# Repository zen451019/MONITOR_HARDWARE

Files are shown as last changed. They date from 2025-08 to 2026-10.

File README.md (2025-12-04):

# NEMO: Electromechanical Monitoring Firmware

This repository contains the complete source code for the firmware for NEMO (Node for Electromechanical Monitoring & Operation), a high-performance IoT node designed for real-time monitoring of analog signals.

The system is optimized to capture, process, and transmit voltage and current data from sensors, making it an ideal solution for predictive maintenance, energy consumption monitoring, and industrial machinery diagnostics applications.

## Modbus master monitor documentation

English
https://zen451019.github.io/MONITOR_HARDWARE/28-11-25/English/MASTER_MODBUS/html/index.html

Spanish
https://zen451019.github.io/MONITOR_HARDWARE/28-11-25/Español/MASTER_MODBUS/html/index.html

## Modbus slave monitor documentation
English
https://zen451019.github.io/MONITOR_HARDWARE/28-11-25/English/SLAVE_MODBUS/html/index.html

Spanish
https://zen451019.github.io/MONITOR_HARDWARE/28-11-25/Español/SLAVE_MODBUS/html/index.html

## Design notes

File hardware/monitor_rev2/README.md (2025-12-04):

# MODBUS MASTER MONITOR

## Description
This PCB uses an ESP32 TTGO LoRa V2.1 that functions as a Modbus master and acts as a gateway for Modbus slaves with various integrated sensors. The design includes a UART to RS485 transceiver for network communication using the Modbus protocol. Additionally, it integrates a voltage detector for a 12-volt battery, a multipurpose digital input, and an 8-position DIP switch for Modbus address selection.

## Repository Contents
- `monitor_REV2/` folder: KiCad files for the schematic and PCB.
- `docs/` folder: Diagrams, images, and PDFs of the design.

## Schematic
Schematic

## PCB
PCB

## Manufacturing
### Gerber Files
The Gerber files are in `monitor_REV2/output`.

### Bill of Materials (BOM)
Included as `monitor_REV2/monitor REV2.csv`.

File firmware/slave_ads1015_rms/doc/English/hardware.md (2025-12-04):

@file hardware.md
@defgroup group_hardware Hardware and System

@section group_hardware_overview Overview
This module implements the ESP32 hardware configuration and complete flow of:
- I2C peripheral configuration for ADS1015 communication.
- RS485 UART configuration for Modbus RTU communication.
- ADC conversion interrupt system initialization.
- FreeRTOS configuration with tasks distributed across cores.

@section Structure_and_components Structure and Components

- Pin and peripheral configuration
  - I2C_SDA_PIN, I2C_SCL_PIN: I2C bus for ADS1015.
  - RX_PIN, TX_PIN: RS485 serial communication.
  - ADS_ALERT_PIN: conversion complete interrupt.

- Hardware objects
  - Adafruit_ADS1015: analog-to-digital converter instance.
  - HardwareSerial: serial port for Modbus RTU.
  - ModbusServerRTU: Modbus protocol server.

- System configuration
  - NUM_CHANNELS: configured ADC channels (3 channels).
  - Speed parameters: 19200 bps UART, 400kHz I2C, 3300 SPS ADC.
  - GAIN_TWOTHIRDS: ADS1015 gain for ±6.144V range.

@section group_hardware_api Main API
- Configuration: `I2C_SDA_PIN`, `I2C_SCL_PIN`, `ADS_ALERT_PIN`, `RX_PIN`, `TX_PIN`, `NUM_CHANNELS`.
- Objects: `ads`.
- Functions: `setup()`, `loop()`, `on_adc_data_ready()`.

@section group_hardware_usage Usage
Flow summary:

1) Hardware initialization
   - I2C bus configuration (SDA=9, SCL=8) at 400kHz.
   - ADS1015 initialization with TWOTHIRDS gain and 3300 SPS speed.
   - UART configuration (RX=20, TX=21) at 19200 bps, 8N1 for RS485.
   - Interrupt registration on pin 10 for ADS1015 ALERT signal.

2) FreeRTOS task configuration
   - `task_adquisicion`: core 0, priority 5, ADC conversion management.
   - `task_procesamiento`: core 0, priority 3, RMS calculation with FIFOs.
   - `dataUpdateTask`: core 0, priority 1, Modbus register updates.
   - Modbus server: core 0, RTU request handling.

3) ADC configuration
   - Single-ended mode on 3 channels (A0, A1, A2).
   - Interrupt-driven conversions using ALERT signal.
   - Round-robin sequence between channels managed by ISR.

4) Modbus configuration
   - RTU server with ID=1, timeout=2000ms.
   - Worker registration for function 03 (holding register read).
   - Discovery response (registers 0-7) and RMS data (registers 10+).

Warnings and best practices:
- Verify I2C connections before `ads.begin()` to avoid hangs.
- Use external pullups on SDA/SCL lines if communication issues occur.
- Properly configure ADS1015 ALERT signal for interrupts.
- Verify I2C bus speed according to cable length.
- Protect concurrent hardware access using appropriate semaphores.
- Ensure stable power supply for accurate ADC conversions.

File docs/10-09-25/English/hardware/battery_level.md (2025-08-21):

## Battery Level

The battery in an electromechanical system acts as a primary or backup power source, ensuring startup, continuous operation in the event of power outages, and system stability. It also dampens transients, supplies peak currents to actuators, and keeps control and sensing circuits powered for reliable operation.

## ## Signal Conditioning

The battery signal is direct current (DC) and, due to its voltage level, the [ESP32](./central_controller.md) cannot monitor it directly. Therefore, a voltage divider is implemented that reduces the signal to a safe range for the microcontroller, while maintaining its representativeness with respect to the actual battery level.



$$
V_{out} = V_{in} \frac{ R_2 }{R_1 + R_2}
$$
With Vin max at 3.3 volts and Vout max at 15 volts for a safe range, and defining R2 = 3.3 kΩ, we find R1.

$$
R_1 = R_2 \frac{ V_{in}-V_{out}}{V_{out}}
$$
$$
R_1 = 3.3 kΩ \frac{ 15V-3.3V}{3.3V} = 11700Ω
$$
Approximating the value of R1 to a commercial resistor, we have that R1 = 12 kΩ, with this the maximum Vin is

$$
V_{in} = 3.3V \frac{ 12 kΩ + 3.3 kΩ }{3.3 kΩ} = 15.3 V
$$

This voltage divider adapts the range from 0 V to 15.3 V to a safe range from 0 V to 3.3 V for microcontroller reading. The actual value is then scaled using software.



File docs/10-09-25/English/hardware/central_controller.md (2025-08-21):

# Central Controller

A microcontroller with high computing power, multiple input/output interfaces, integrated analog-to-digital conversion, and robust communication capabilities is required as the central control device. For these reasons, the ESP32 family was selected, which offers an appropriate balance between performance, wireless connectivity, development ecosystem, and cost, enabling local processing, communications management, and real-time control within a single SoC.

## Module Selection

To accelerate development and consolidate computing, radio, and power functions onto a single board, the TTGO LoRa32 v2.1 module/board is selected, based on the ESP32‑PICO‑D4 SoC and integrated with an SX127x family LoRa transceiver. This choice provides a ready-to-prototype and ready-to-operate environment, with wireless connectivity and sufficient I/O resources for system data acquisition and transmission.

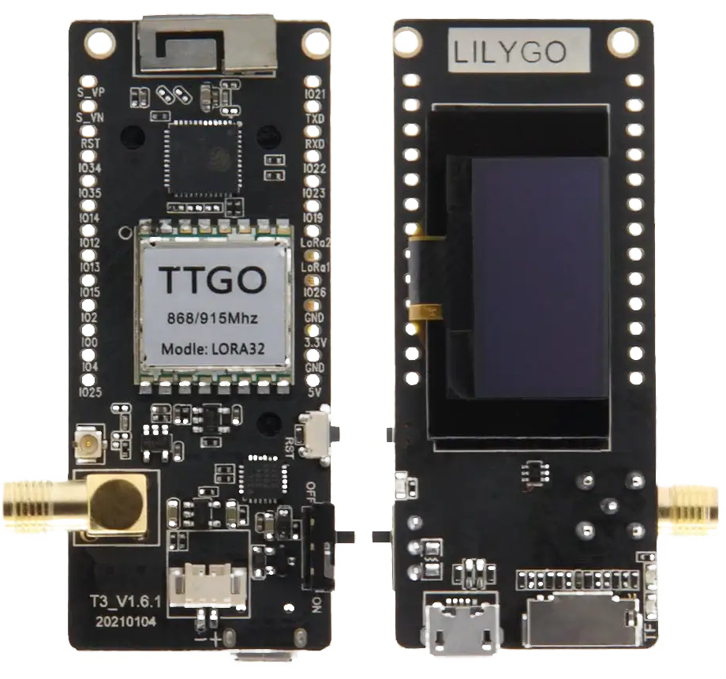
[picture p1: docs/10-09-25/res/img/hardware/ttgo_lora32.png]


### SoC ESP32 PICO D4 Capabilities

* CPU: dual-core Xtensa LX6 up to 240 MHz, with ULP coprocessor for ultra-low power tasks.
* Memory: integrated SRAM and support for external Flash; DMA for high-performance peripherals.
* ADC/DAC: 12-bit ADC with multiple channels and 2 8-bit DACs
* GPIO and interfaces: UART, I2C, SPI, I2S, PWM (ledc), RMT, SD/SDIO; Ethernet MAC and CAN (TWAI).
* Security: AES encryption, SHA, RSA/ECC, HMAC; Secure Boot and Flash Encryption.
* Industrial temperature range: −40 °C to +85 °C.

### Integrated LoRa Radio

The TTGO LoRa32 v2.1 incorporates a LoRaSX1276 transceiver compatible with LoRaWAN in the target regional band (868/915 MHz), with configurable dispersion factors and bandwidths, and adjustable transmission power for long-range links.

### Relevant Features of the TTGO LoRa32 v2.1

* Power supply: integrated regulator, USB input and 3V3 pin; charger for Li‑ion/Li‑Po battery with JST connector.
* User interface: integrated OLED display, buttons, and status LEDs for local diagnostics.
* Connectivity and programming: USB‑UART port for programming/debugging and log support; LoRa antenna included.

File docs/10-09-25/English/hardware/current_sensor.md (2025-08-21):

# Three-phase Current Transducer

The current transducer is the element responsible for capturing the electrical current present in the electromechanical system and transforming it into a signal suitable for the microcontroller's acquisition stage, through the corresponding conditioning. There are multiple variants of current transducers, based on principles such as the Hall effect, shunt resistance, or current transformer, and available with analog or digital outputs, depending on the interface requirements and system specifications.

## SCT-013-000 Sensor

The SCT-013-000 is a non-invasive split-core AC current transducer that uses a current transformer to measure AC with galvanic isolation. In its variant (100 A : 50 mA), it delivers a proportional current signal that requires an external load resistance (burden) to convert it into a voltage suitable for reading by microcontrollers.

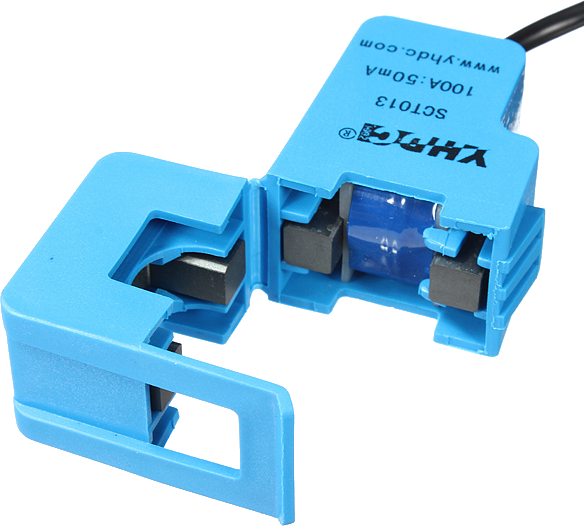
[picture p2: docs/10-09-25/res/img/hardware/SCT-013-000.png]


### Features
- Clip-type split core, installation without interrupting the circuit and with safe galvanic isolation.
- Transformation ratio 100 A : 50 mA (model SCT-013-000, without integrated load resistance).
- Requires external burden resistance sized according to the ADC range and the current level to be measured.
- Analog output proportional to the primary current; requires center bias for AC reading with 3.3 V or 5 V ADC.
- Nominal frequency 50/60 Hz; good linearity in residential and industrial applications.

## Signal Conditioning

The SCT-013-000 delivers an AC signal on its secondary side proportional to the current flowing through the primary side, operating as a current transformer. In this version (100 A : 50 mA), the ratio is 2000:1, so that, for example, if 50 A RMS flows through the primary, 25 mA RMS will flow through the secondary. In order for the microcontroller to register this magnitude, it is necessary to convert the secondary current into a voltage using a load resistor (**burden**) connected in parallel between the sensor terminals. According to Ohm's law, the resulting voltage is :  $$V = I_{sec} × R_{burden}$$
To size the **burden** resistance, the target voltage level at the sensor output must be considered so that the input range of the analog-to-digital converter (ADC) of the [ESP32](./central_controller.md), typically 0 to 3.3 V, is not exceeded. Consequently, the voltage generated by the secondary current through the **burden** must be, at most, equal to or less than the ADC limit. In AC applications, it is common to add a DC bias at the midpoint of the ADC scale to center the signal within the 0–3.3 V range and avoid clipping.

![[../../res/img/hardware/Sensor_and_conditioning.drawio.svg]]

A voltage range of 2.828 V has been considered, which is comfortably within the ADC range. By not operating near its limits, there is sufficient safety margin to reduce the risk of signal saturation and clipping.

Assuming a target voltage of

$$
2.828 V_{pico a pico} = 1.414 V_{pico}
$$
With a max current value
$$
I_{RMS(sec)} = 50 mA
$$
To resolve R
$$
I_{RMS(sec)} × R_{burden} = V_{RMS}   
$$
$$
50mA × R_{burden} =  \frac{ V_{pico} }{\sqrt{2}} 
$$
$$
50mA × R_{burden} =  \frac{ 1.414 V_{pico} }{\sqrt{2}} = 1 V_{RMS}
$$
$$
R_{burden} \approx 20 \Omega
$$

As a result, the necessary load resistance (burden) is approximately 20 Ω. It is still necessary to add a bias voltage to the signal, as otherwise half of the amplitude would be lost due to the microcontroller's inability to measure negative voltages. To take advantage of the widest possible dynamic range, this bias is set at half the measurement range, for which a voltage divider is used. The following equation represents the output voltage as a function of the input voltage to the voltage divider.



$$
V_{out} = V_{in} \frac{ R_2 }{R_1 + R_2}
$$
If R2 = R1
$$
V_{out} = V_{in} \frac{ R_2 }{2 R_2}
$$
$$
V_{out} =  \frac{ V_{in} }{2}
$$

To limit the current, R = 10 kΩ is selected. With this value, the following conditioning circuit is proposed for the SCT-013-000 AC current sensor (100 A / 50 mA).

![[../../res/img/hardware/Diagrama_sensor_corriente.drawio.svg]]

A 100 nF capacitor is added as an anti-aliasing filter and another 10 µF capacitor to keep the bias voltage stable. Like the [voltage sensor](./voltage_sensor.md), the sensor and its conditioning circuit can only measure a single-phase signal. To compensate for this and obtain two-phase or three-phase measurements, the use of three sensors with their respective conditioning circuits is proposed; in this way, each one is responsible for one voltage line and complete measurements are obtained.

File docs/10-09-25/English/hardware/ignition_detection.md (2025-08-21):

# Ignition Detection

The module must have a mechanism to detect when the electromechanical system is turned on and off, as certain variables depend directly on it being active in order to be processed correctly. To this end, a digital input is designed to allow the microcontroller to capture external signals.

The signal to be monitored will be the presence or absence of DC voltage from the battery, the controller, or any other device in the electromechanical system. This offers flexibility in both hardware (using a relay, the controller itself, etc., to generate the power-on signal) and software for encoding the logic.

## Signal Conditioning

In order for the microcontroller to safely capture these signals, given the differences in voltage levels, an opto-coupler level shifter is used, providing level adaptation and galvanic isolation.



Each time a digital signal arrives, the optocoupler activates its diode, which in turn turns on the phototransistor. This allows the pin on the [ESP32](./central_controller.md) to drop to GND. For correct detection, the ESP32 pin must be configured as an input with pull-up.

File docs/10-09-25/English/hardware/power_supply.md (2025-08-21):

# Module power supply

The module's power supply must be reliable, stable, and uninterrupted. Since data is transmitted 24/7, it is essential to avoid shutdowns in the event of any contingency. This requires a power supply system that anticipates possible failures and, as far as possible, mitigates or counteracts them.
## Requirements

- **Power Supply:** The main power supply is the electromechanical system battery, so the module must be able to draw power from this source.
- **Uninterrupted Power Supply:** The module must continue to operate even if the main power source is interrupted, so it must include a system that guarantees a continuous power supply.
- **Stable voltage level:** Both the [ESP32](./central_controller.md) and the other components of the module require a 3.3-volt power supply. Therefore, the power supply system must guarantee a stable source for the module.

To meet these requirements, two modules are selected to form the power supply system.

## DC-DC step-down converter

- Input: 12–24 VDC. Output: 5 VDC.
- Maximum power: 50 W. Efficiency: 95%.
- Protections: overcurrent, overvoltage, overtemperature, shutdown, and short circuit.
- Temperature range: −40 to 85 °C
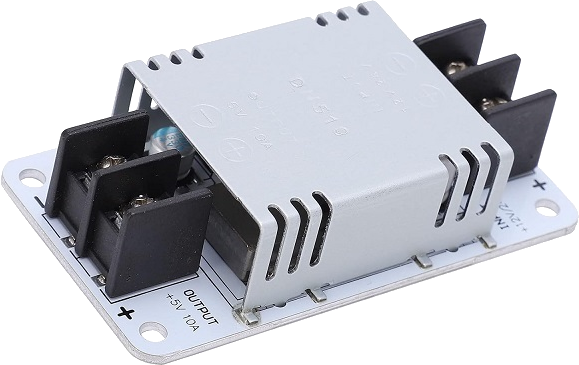
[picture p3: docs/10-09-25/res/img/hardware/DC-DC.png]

### 18650 battery UPS module
- Input: 5 VDC. Output: 3.3 VDC (800mA), 3.7VDC.
- With on/off switch.
- Low voltage and overcharge protection activation button.
- Maximum battery protection current limit: 2A.
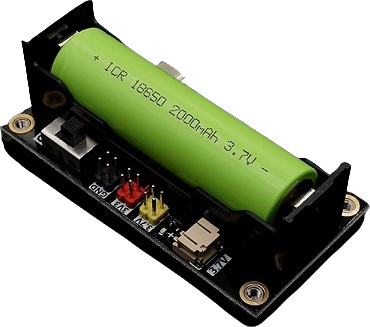
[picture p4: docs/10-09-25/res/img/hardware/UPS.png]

With this arrangement, the DC-DC converter is connected to the electromechanical system battery and delivers a fixed 5 V. That voltage powers the UPS module, which charges its 18650 cell and, through its 3.3 V regulator, supplies a stable voltage to the module.

In this way, the power supply system has protections against battery contingencies (voltage drops, short circuits, etc.). In addition, if the power supply is interrupted, the UPS kicks in instantly, ensuring continuity and preventing the module from shutting down.

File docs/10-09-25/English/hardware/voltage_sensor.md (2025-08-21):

# Three-phase Voltage Transducer

The voltage transducer is the device responsible for measuring the voltage signal generated by the electromechanical system and converting it into a signal compatible with the microcontroller's acquisition stage, through the corresponding signal conditioning. There are various types of voltage transducers, with analog or digital outputs, depending on their measurement principle and the system's interface requirements.

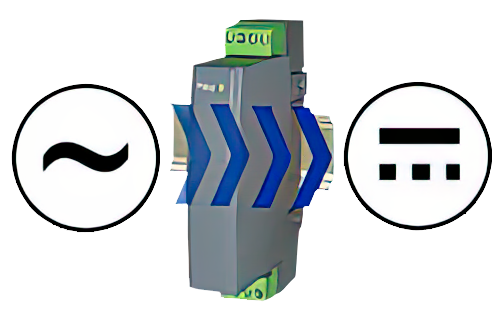
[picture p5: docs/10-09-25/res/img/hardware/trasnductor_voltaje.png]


##  ZMPT101B Sensor

The ZMPT101B is a single-phase AC voltage transducer that uses a microtransformer to measure AC voltages with galvanic isolation. The module integrates an amplifier and a potentiometer for calibrating the gain, delivering a proportional analog signal suitable for reading with microcontrollers.
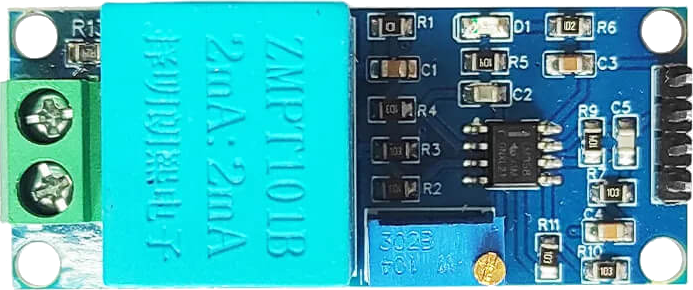
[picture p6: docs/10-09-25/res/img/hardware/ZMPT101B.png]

### Features

* Galvanic isolation via microtransformer, safe for network measurements.
* Module with conditioning stage: operational amplifier and adjustment trimmer.
* Proportional analog output, compatible with 3.3 V and 5 V ADCs.
* Nominal frequency: 50/60 Hz; good linearity in residential and industrial applications.

## Signal Conditioning

The ZMPT101B module delivers an analog signal proportional to the AC input voltage. When powered by 3.3 V, the output is an alternating signal superimposed on a reference level of 1.65 V, so that variations around that point are proportional to the measured voltage and can be sampled with an analog-to-digital converter from the [ESP32](./central_controller.md).

Thanks to this module, it is possible to record a representative AC voltage signal with little more than a direct connection between the ZMPT101B module and the microcontroller. In this way, signal conditioning is reduced to the inclusion of a capacitor designed to filter high-frequency components and improve the performance of the microcontroller's analog-to-digital converter (ADC) during sampling.

Since the ZMPT101B sensor is a single-phase device, its application in three-phase voltage measurement is limited. To compensate for this restriction, it is proposed to use three ZMPT101B sensors, each dedicated to one phase of the system, thus obtaining an effective three-phase measurement.

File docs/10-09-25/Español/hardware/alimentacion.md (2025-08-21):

# Alimentación del modulo

La alimentación del módulo debe ser confiable, estable e ininterrumpida. Como los datos se transmiten 24/7, es imprescindible evitar apagados ante cualquier eventualidad. Para ello, se requiere un sistema de alimentación que contemple posibles fallas y, en lo posible, las mitigue o contrarreste.
## Requerimientos

- **Punto de Alimentación:** El principal punto de alimentación es la batería del sistema electromecánico, por lo que el módulo debe ser capaz de tomar energía de esta fuente.
- **Alimentación ininterrumpida:** El módulo debe seguir operando aun si se interrumpe la fuente principal, por lo que debe incluir un sistema que garantice un suministro continuo de energía.
- **Nivel de voltaje estable:** Tanto el [ESP32](./controlador_central.md) como los demás componentes del módulo requieren una alimentación de 3.3 Voltios. Por lo tanto, el sistema de alimentación debe garantizar una fuente estable para el módulo.

Para cumplir estos requisitos, se seleccionan dos módulos para conformar el sistema de alimentación.

## Conversor reductor DC-DC

- Entrada: 12–24 VDC. Salida: 5 VDC.
- Potencia máxima: 50 W. Eficiencia: 95%.
- Protecciones: sobrecorriente, sobretensión, sobretemperatura, apagado y cortocircuito.
- Rango de temperatura: −40 a 85 °C



###  Módulo UPS de batería 18650

- Entrada: 5 VDC. Salida: 3.3 VDC (800mA), 3.7VDC.
- Con interruptor on/off.
- Botón de activación de protección contra baja tensión y sobredescarga.
- Límite máximo de corriente de protección de la batería: 2A.



Con este arreglo, el convertidor DC‑DC se conecta a la batería del sistema electromecánico y entrega 5 V fijos. Ese voltaje alimenta el módulo UPS, que carga su celda 18650 y, mediante su regulador de 3.3 V, suministra una tensión estable al módulo.



De este modo, el sistema de alimentación cuenta con protecciones ante eventualidades de la batería (caídas de tensión, cortocircuitos, etc.). Además, si se interrumpe la alimentación, la UPS entra en acción de forma instantánea, garantizando la continuidad y evitando que el módulo se apague.

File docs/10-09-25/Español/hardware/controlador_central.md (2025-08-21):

# Controlador Central

Como dispositivo de control central se requiere un microcontrolador con alta capacidad de cómputo, múltiples interfaces de entrada/salida, conversión analógica–digital integrada y capacidades de comunicación robustas. Por estos motivos se selecciona la familia ESP32, que ofrece un balance adecuado entre desempeño, conectividad inalámbrica, ecosistema de desarrollo y costo, permitiendo ejecutar procesamiento local, gestión de comunicaciones y control en tiempo real dentro de un solo SoC.

## Selección del módulo

Para acelerar el desarrollo y consolidar en una sola placa las funciones de cómputo, radio y alimentación, se selecciona el módulo/placa TTGO LoRa32 v2.1, basado en el SoC ESP32‑PICO‑D4 e integrado con un transceptor LoRa de la familia SX127x. Esta elección proporciona un entorno listo para prototipado y operación, con conectividad inalámbrica y recursos de E/S suficientes para la adquisición y transmisión de datos del sistema.



### Capacidades del SoC ESP32 PICO D4

* CPU: doble núcleo Xtensa LX6 hasta 240 MHz, con coprocesador ULP para tareas de ultra bajo consumo.
* Memoria: SRAM integrada y soporte para Flash externa; DMA para periféricos de alto rendimiento.
* ADC/DAC: ADC de 12 bits con múltiples canales y 2 DAC de 8 bits
* GPIO e interfaces: UART, I2C, SPI, I2S, PWM (ledc), RMT, SD/SDIO; Ethernet MAC y CAN (TWAI).
* Seguridad: cifrado AES, SHA, RSA/ECC, HMAC; Secure Boot y Flash Encryption.
* Rango de temperatura industrial: −40 °C a +85 °C.

### Radio LoRa integrada

La TTGO LoRa32 v2.1 incorpora un transceptor LoRa SX1276 compatible con LoRaWAN en la banda regional objetivo (868/915 MHz), con factores de dispersión y anchos de banda configurables, y potencia de transmisión ajustable para enlaces de largo alcance.

### Características relevantes de la placa TTGO LoRa32 v2.1

* Alimentación: regulador integrado, entrada por USB y pin 3V3; cargador para batería Li‑ion/Li‑Po con conector JST.
* Interfaz de usuario: pantalla OLED integrada, botones y LED de estado para diagnóstico local.
* Conectividad y programación: puerto USB‑UART para programación/depuración y soporte de logs; antena para LoRa incluida.

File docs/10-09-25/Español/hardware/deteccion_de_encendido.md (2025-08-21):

# Detección De Encendido

El modulo debe contar con un mecanismo para detectar el encendido y apagado del sistema electromecánico, ya que ciertas variables dependen directamente de que esté activo para procesarse correctamente. Para ello, se diseña una entrada digital que permita al microcontrolador captar señales externas.

La señal a monitorear será la presencia o ausencia de voltaje DC, proveniente de la batería, el controlador o cualquier otro dispositivo del sistema electromecánico. Esto ofrece flexibilidad tanto en hardware (usando un relé, el propio controlador, etc., para generar la señal de encendido) como en software para codificar la lógica.

## Acondicionamiento de señal

Para que el microcontrolador capte estas señales de forma segura, dadas las diferencias de nivel de voltaje, se utiliza un level shifter con optoacoplador, proporcionando adaptación de niveles y aislamiento galvánico.



Cada vez que llega una señal digital, el optoacoplador activa su diodo, lo que a su vez enciende el fototransistor. Esto permite que el pin del [ESP32](./controlador_central) caiga a GND. Para una detección correcta, el pin del ESP32 debe configurarse como una entrada con pull-up.

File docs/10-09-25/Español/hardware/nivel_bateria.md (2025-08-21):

## Nivel de batería

La batería de un sistema electromecánico cumple el papel de fuente de energía primaria o de respaldo, asegurando el arranque, la continuidad de operación ante cortes de suministro y la estabilidad del sistema. Además, amortigua transitorios, suministra corrientes de pico a actuadores, y mantiene alimentados los circuitos de control y sensado para un funcionamiento confiable.

## Acondicionar señal

La señal de una batería es de corriente continua (DC) y, debido a su nivel de voltaje, el [ESP32](./controlador_central.md) no puede monitorearla directamente. Por ello, se implementa un divisor de voltaje que reduce la señal a un rango seguro para el microcontrolador, manteniendo su representatividad respecto al nivel real de la batería.


$$
V_{out} = V_{in} \frac{ R_2 }{R_1 + R_2}
$$
Siendo el Vin máximo 3.3 Volts y el Vout máximo Y un Vout máximo de 15 volts para tener un rango seguro y definiendo R2 = 3.3 kΩ se halla R1

$$
R_1 = R_2 \frac{ V_{in}-V_{out}}{V_{out}}
$$
$$
R_1 = 3.3 kΩ \frac{ 15V-3.3V}{3.3V} = 11700Ω
$$
Aproximando el valor de R1 a una resistencia comercial tenemos que R1 = 12 kΩ, con esto el Vin máximo queda

$$
V_{in} = 3.3V \frac{ 12 kΩ + 3.3 kΩ }{3.3 kΩ} = 15.3 V
$$

Este divisor de voltaje adapta el rango de 0 V a 15.3 V a un rango seguro de 0 V a 3.3 V para la lectura del microcontrolador. Posteriormente, el valor real se escala mediante software.



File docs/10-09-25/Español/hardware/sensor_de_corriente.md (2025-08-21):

../../res/img/hardware/# Transductor de corriente trifásico

El transductor de corriente es el elemento responsable de captar la corriente eléctrica presente en el sistema electromecánico y de transformarla en una señal adecuada para la etapa de adquisición del microcontrolador, mediante el acondicionamiento correspondiente. Existen múltiples variantes de transductores de corriente, basadas en principios como el efecto Hall, la resistencia shunt o el transformador de corriente, y disponibles con salidas analógicas o digitales, de acuerdo con las necesidades de interfaz y las especificaciones del sistema.

## Sensor SCT-013-000

El SCT-013-000  es un transductor de corriente alterna no invasivo de núcleo partido que emplea un transformador de corriente para medir AC con aislamiento galvánico. En su variante (100 A : 50 mA) entrega una señal de corriente proporcional que requiere una resistencia de carga (burden) externa para convertirla en una tensión apta para lectura por microcontroladores.



### Características
- Núcleo partido tipo clip, instalación sin interrumpir el circuito y con aislamiento galvánico seguro.
- Relación de transformación 100 A : 50 mA (modelo SCT-013-000, sin resistencia de carga integrada).
- Requiere resistencia burden externa dimensionada según el rango del ADC y el nivel de corriente a medir.
- Salida analógica proporcional a la corriente primaria; precisa sesgo de media (bias) para lectura AC con ADC de 3.3 V o 5 V.
- Frecuencia nominal 50/60 Hz; buena linealidad en aplicaciones residenciales e industriales.

## Acondicionamiento de señal

El SCT-013-000 entrega una señal de corriente alterna en su secundario proporcional a la corriente que circula por el primario, al operar como un transformador de corriente. En esta versión (100 A : 50 mA), la relación es 2000:1, de modo que, por ejemplo, si por el primario circulan 50 A RMS, por el secundario circularán 25 mA RMS. Para que el microcontrolador pueda registrar esta magnitud, es necesario convertir la corriente secundaria en una tensión mediante una resistencia de carga (**burden**) conectada en derivación entre los terminales del sensor. Por ley de Ohm, la tensión resultante es :  $$V = I_{sec} × R_{burden}$$
Para dimensionar la resistencia de **burden** debe considerarse el nivel de tensión objetivo en la salida del sensor, de modo que no se exceda el rango de entrada del convertidor analógico-digital (ADC) del [ESP32](./controlador_central.md), típicamente 0 a 3.3 V. En consecuencia, la tensión generada por la corriente secundaria a través de la **burden** debe ser, como máximo, igual o inferior al límite del ADC. En aplicaciones de corriente alterna, es habitual añadir un sesgo de corriente continua (bias) a mitad de escala del ADC para centrar la señal dentro del rango 0–3.3 V y evitar recortes.

![[../../res/img/hardware/señal_acodiciona.drawio.svg]]

Se ha considerado un rango de tensión de 2.828 V, el cual se ubica cómodamente dentro del rango del ADC. Al no operar cerca de sus límites, se dispone de un margen de seguridad suficiente que reduce el riesgo de saturación y recorte de la señal. 

Suponiendo un voltaje objetivo de

$$
2.828 V_{pico a pico} = 1.414 V_{pico}
$$
Con una corriente máxima de
$$
I_{RMS(sec)} = 50 mA
$$
Se despeja R
$$
I_{RMS(sec)} × R_{burden} = V_{RMS}   
$$
$$
50mA × R_{burden} =  \frac{ V_{pico} }{\sqrt{2}} 
$$
$$
50mA × R_{burden} =  \frac{ 1.414 V_{pico} }{\sqrt{2}} = 1 V_{RMS}
$$
$$
R_{burden} \approx 20 \Omega
$$

Como resultado, la resistencia de carga (burden) necesaria es de aproximadamente 20 Ω. Aún es necesario añadir una tensión de polarización (bias) a la señal, ya que de lo contrario se perdería la mitad de la amplitud debido a la incapacidad del microcontrolador para medir tensiones negativas. Para aprovechar el mayor rango dinámico posible, se fija dicha polarización en la mitad del rango de medida, para lo cual se emplea un divisor de tensión, la siguiente ecuación representa el voltaje de salida en función del voltaje de entrada al divisor de tensión.



$$
V_{out} = V_{in} \frac{ R_2 }{R_1 + R_2}
$$
Si R2 = R1
$$
V_{out} = V_{in} \frac{ R_2 }{2 R_2}
$$
$$
V_{out} =  \frac{ V_{in} }{2}
$$

Para limitar la corriente, se selecciona R = 10 kΩ. Con este valor, se propone el siguiente circuito de acondicionamiento para el sensor de corriente alterna SCT-013-000 (100 A / 50 mA).

![[../../res/img/hardware/Diagrama_sensor_corriente.drawio.svg]]

Se agrega un capacitor de 100 nF como filtro antialias y otro de 10 µF para mantener estable la tensión de bias. Al igual que el [sensor de voltaje](./sensor_de_voltaje.md), el sensor y su circuito de acondicionamiento solo pueden medir una señal monofásica. Para compensarlo y obtener mediciones bifásicas o trifásicas, se propone el uso de tres sensores con sus respectivos acondicionamientos; de esta forma, cada uno se encarga de una línea de voltaje y se obtienen mediciones completas.

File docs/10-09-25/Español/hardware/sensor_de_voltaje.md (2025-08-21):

# Transductor del voltaje trifásico

El transductor de voltaje es el dispositivo encargado de medir la señal de tensión generada por el sistema electromecánico y convertirla en una señal compatible con la etapa de adquisición del microcontrolador, mediante el correspondiente acondicionamiento de señal. Existen diversos tipos de transductores de tensión, con salidas analógicas o digitales, según su principio de medición y los requisitos de interfaz del sistema.



## Sensor zmpt101b

El ZMPT101B es un transductor de tensión alterna monofásica que utiliza un microtransformador para medir voltajes AC con aislamiento galvánico. El módulo integra un amplificador y un potenciómetro para calibrar la ganancia, entregando una señal analógica proporcional apta para lectura con microcontroladores.

### Características

* Aislamiento galvánico mediante microtransformador, seguro para mediciones de red.
* Módulo con etapa de acondicionamiento: amplificador operacional y trimmer de ajuste.
* Salida analógica proporcional, compatible con ADC de 3.3 V y 5 V.
* Frecuencia nominal: 50/60 Hz; buena linealidad en aplicaciones residenciales e industriales.

## Acondicionamiento de señal

El módulo ZMPT101B entrega una señal analógica proporcional al voltaje AC de entrada. Cuando se alimenta con 3,3 V, la salida es una señal alterna superpuesta a un nivel de referencia de 1,65 V, de modo que las variaciones alrededor de ese punto son proporcionales a la tensión medida y pueden muestrearse con un conversor análogo digital del [ESP32](./controlador_central.md).



Gracias a este módulo es posible registrar una señal representativa de la tensión en corriente alterna con poco más que una conexión directa entre el módulo ZMPT101B y el microcontrolador. De este modo, el acondicionamiento de la señal se reduce a la inclusión de un condensador destinado a filtrar componentes de alta frecuencia y a mejorar el desempeño del convertidor analógico-digital (ADC) del microcontrolador durante el muestreo.



Dado que el sensor ZMPT101B es un dispositivo monofásico, su aplicación en la medición de tensión trifásica se encuentra limitada. Para compensar esta restricción, se propone emplear tres sensores ZMPT101B, cada uno dedicado a una fase del sistema, obteniendo así una medición trifásica efectiva.

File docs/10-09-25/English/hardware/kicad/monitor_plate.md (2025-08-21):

# Electromechanical variable monitoring module MONITOR

Electronic board based on the [TTGO LoRa32 V2.1](../central_controller.md) module (ESP32 + LoRa) for measuring electrical parameters of electromechanical systems and transmitting them wirelessly. The system integrates three-phase AC voltage and current sensing, battery level monitoring, and a digital input for event detection.
#### Specifications
- Power supply: 3.3 V / 800 mA LDO for logic.
- Dedicated inputs for external current sensors.
- Integrated LoRa connectivity in the TTGO LoRa32 V2.1.
- Screw terminals for AC mains and sensor connections.
### [Hardware Architecture](../architecture.md)

## Interfaces and Pins

Voltage measurement: terminal blocks for connecting the three-phase AC voltage signal using [ZMPT101B](../voltage_sensor.md) modules, with power supply and analog output to the ESP32 ADC through a 5-pin JST connector.

| INPUT | DESCRIPTION | OUTPUT  |
| ----- | --- | --- |
| 1 | NEUTRAL | |
| 2 | LINE 3 | GPIO 36 |
| 3 | LINE 2 | GPIO 39 |
| 4 | LINE 1 | GPIO 34 |

Current measurement: terminal blocks for connecting [SCT-013-000](../current_sensor.md) sensors (current transformers), conditioning circuit, and output to the ESP32 ADC.

| INPUT | DESCRIPTION | OUTPUT  |
| ----- | --- | --- |
| 8 | SENSOR 3 WHITE TERMINAL | |
| 9 | SENSOR 3 RED TERMINAL | GPIO 13 |
| 10 | SENSOR 2 WHITE TERMINAL | |
| 11 | SENSOR 2 RED TERMINAL | GPIO 04 |
| 12 | SENSOR 1 WHITE TERMINAL | |
| 13 | SENSOR 1 RED TERMINAL | GPIO 25 |
Battery: terminal block connection for [battery voltage](../battery_level.md), resistive divider output to ESP32 ADC.

Power on/off signal: terminal block connection to [level shifter](../ignition_detection.md) circuit with PC817 optocoupler, output to ESP32 pull-up configured pin.

| INPUT | DESCRIPTION | OUTPUT  |
| ----- | --- | --- |
| 5 | BATTERY NEGATIVE | |
| 6 | POWER ON SIGNAL  | GPIO 35 |
| 7 | BATTERY POSITIVE | GPIO 14 |

[Power Supply](../power_supply.md): 3.3 Volt input through a 2-pin JST connector (auxiliary 4-pin JST connector, not soldered), powering the ESP32 and other components.
#### Electrical Requirements

- Main input: 3.3 V DC (capacity according to TTGO + sensor consumption).
- Analog signals: matched to the ESP32 ADC range (0–3.3 V). It is recommended to verify that dividers/conditioning circuits maintain proper amplitude and offset.
### [Electrical Schematic of the Monitor Board](./Schema.md)
— Detailed diagram of components and electrical connections.

### [PCB Design of the Monitor Board](./plate.md)
— Layout and physical distribution of components on the printed circuit board.

### [3D Model of the Monitor](./3D_E.md)
— Three-dimensional representation of the final assembly for visualization and mechanical verification.

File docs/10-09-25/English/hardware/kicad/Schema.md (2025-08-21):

# Circuit Schema

The schematic design of the system is carried out using the KICAD electronic design platform, version 9.0. This specialized software allows for the detailed and accurate creation of electrical and electronic diagrams, facilitating the graphical representation of components and their interconnections within the system. As a result of this process, a complete and structured schematic is obtained.

![[../../../res/img/schema/Esquematico.svg]]

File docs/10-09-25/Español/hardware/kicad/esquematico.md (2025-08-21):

# Esquema del circuito 

El diseño esquemático del sistema se lleva a cabo utilizando la plataforma de diseño electrónico KICAD, versión 9.0. Este software especializado permite la creación detallada y precisa de diagramas eléctricos y electrónicos, facilitando la representación gráfica de los componentes y sus interconexiones dentro del sistema. Como resultado de este proceso, se obtiene un esquema completo y estructurado.

![[../../../res/img/schema/Esquematico.svg]]

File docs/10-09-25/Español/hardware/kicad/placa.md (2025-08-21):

# PBC

El diseño de la placa de circuito impreso (PCB) se lleva a cabo en el editor de PCB integrado en KICAD V9.0, donde se realiza la disposición precisa de los componentes sobre la superficie de la placa y se definen las rutas de las pistas que los conectan eléctricamente. Durante este proceso, se identificó que algunos componentes clave, como el sensor de voltaje y el microcontrolador ESP32, no contaban con esquemas ni huellas prediseñadas en la biblioteca del software. Por esta razón, fue necesario crear manualmente tanto los esquemáticos como las huellas correspondientes para estos elementos, garantizando así su correcta integración en el diseño.

![[../../../res/img/schema/placa.svg]]

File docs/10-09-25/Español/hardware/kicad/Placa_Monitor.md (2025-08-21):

# Modulo de monitoreo de variables electromecánicas MONITOR

Placa electrónica basada en modulo [TTGO LoRa32 V2.1](../controlador_central.md) (ESP32 + LoRa) para medir parámetros eléctricos de sistemas electromecánicos y transmitirlos de forma inalámbrica. El sistema integra sensado de tensión y corriente AC trifásica, monitoreo de nivel batería y una entrada digital para la detección de eventos.
#### Especificaciones
- Alimentación: LDO a 3.3 V/800 mA para lógica.
- Entradas dedicadas para sensores de corriente externos.
- Conectividad LoRa integrada en el TTGO LoRa32 V2.1.
- Bornas de tornillo para conexión de red AC, sensores.
- Conectores JST para conexiones de lógica y alimentación.

### [Arquitectura de hardware](../arquitectura.md)

## Interfaces y pines

Medición de voltaje : borneras para conexión de señal de voltaje de corriente alterna trifásica mediante módulos [ZMPT101B](../sensor_de_voltaje.md), alimentación y salida analógica hacia ADC ESP32 mediante conector JST de 5 pines.

| ENTRADA | DESCRIPCIÓN | SALIDA  |
| --- | --- | --- |
| 1 | NEUTRO | |
| 2 | LINEA 3 | GPIO 36 |
| 3 | LINEA 2 | GPIO 39 |
| 4 | LINEA 1 | GPIO 34 |

Medición de corriente: borneras para la conexión de sensores [SCT-013-000](../sensor_de_corriente.md) (transformador de corriente), circuito de acondicionamiento y salida hacia ADC de ESP32.

| ENTRADA | DESCRIPCIÓN | SALIDA  |
| --- | --- | --- |
| 8 | TERMINAL BLANCO SENSOR 3 | |
| 9 | TERMINAL ROJO SENSOR 3 | GPIO 13 |
| 10 | TERMINAL BLANCO SENSOR 2 | |
| 11 | TERMINAL ROJO SENSOR 2 | GPIO 04 |
| 12 | TERMINAL BLANCO SENSOR 1 | |
| 13 | TERMINAL ROJO SENSOR 1 | GPIO 25 |

Batería: bornera de conexión de [voltaje de batería](../nivel_bateria.md), divisor resistivo salida hacia ADC ESP32.

Señal de encendido y apagado: bornera de conexión hacia circuito [level shifter](../deteccion_de_encendido.md) con optoacoplador PC817, salida a pin configuración pull-up ESP32.

| ENTRADA | DESCRIPCIÓN | SALIDA  |
| --- | --- | --- |
| 5 | NEGATIVO BATERIA | |
| 6 | SEÑAL DE ENCENDIDO | GPIO 35 |
| 7 | POSITIVO DE LA BAERIA | GPIO 14 |

[Alimentación](../alimentacion.md): Entrada de 3.3 Voltios mediante conector JST de dos 2 pines ( conector JST de 4 pines auxiliar, no soldado), alimentación de ESP32 Y demás componentes. DESCRIPCION

#### Requisitos eléctricos

- Entrada principal: 3.3 V DC (capacidad según consumo del TTGO + sensores).
- Señales analógicas: adecuadas al rango ADC del ESP32 (0–3.3 V). Se recomienda verificar que los divisores/condicionamiento mantengan amplitud y offset correctos.

### [Esquema eléctrico de la placa Monitor](./esquematico.md) 
— Diagrama detallado de los componentes y conexiones eléctricas.
### [Diseño de la PCB de la placa Monitor](./placa.md) 
— Layout y distribución física de los componentes en la placa de circuito impreso.
###  [Modelo 3D del Monitor](./3D.md)
— Representación tridimensional del ensamblaje final para visualización y verificación mecánica.

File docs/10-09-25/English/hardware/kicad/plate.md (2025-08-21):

# PBC

The printed circuit board (PCB) design is carried out in the PCB editor integrated into KICAD V9.0, where the precise layout of the components on the board surface is performed and the routes of the tracks that connect them electrically are defined. During this process, it was identified that some key components, such as the voltage sensor and the ESP32 microcontroller, did not have pre-designed schematics or footprints in the software library. For this reason, it was necessary to manually create both the schematics and the corresponding footprints for these elements, thus ensuring their correct integration into the design.
![[placa.svg]]

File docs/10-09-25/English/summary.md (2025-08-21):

# SUMMARY

## Objective

Monitor operating variables in electromechanical systems using dedicated hardware: precise measurement of operating voltage, operating current, battery level, and other critical parameters through sensors and data acquisition modules, with wireless data transmission to a LoRaWAN Gateway.
## Key Metrics

- **System voltage:** ability to accurately measure voltage in single-phase, two-phase, and three-phase AC systems, within a range of 0 to 220 V AC.
- **System current:** ability to accurately measure alternating current in single-phase, two-phase, and three-phase systems, within a range of 0 to 100 A AC.
- **Battery voltage:** ability to accurately measure the battery voltage of the electromechanical system (when applicable) and estimate its state of charge (SoC).
- **Event detection:** ability to detect power-on and power-off events in the electromechanical system.
## Requirements

In addition to measuring current and voltage in three-phase systems, the module must wirelessly transmit the information using LoRaWAN technology, sending it to a gateway located a few meters or even tens of meters away from the acquisition module. It must also guarantee uninterrupted transmission, requiring autonomous operation capability when the main power supply is deactivated.

### [Electromechanical Variables Monitoring Board — Monitor](./hardware/kicad/monitor_plate.md)

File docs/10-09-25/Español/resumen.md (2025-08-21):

# RESUMEN

## Objetivo 

Monitorear variables de operación en sistemas electromecánicos mediante hardware dedicado: medición precisa de voltaje de funcionamiento, corriente de operación, nivel de batería y otros parámetros críticos usando sensores y módulos de adquisición de datos, con transmisión inalámbrica de datos hacia un Gateway Lora WAN.
## Métricas clave

* Tensión del sistema: capacidad para medir con precisión el voltaje en sistemas monofásicos, bifásicos y trifásicos de corriente alterna, en un rango de 0 a 220 V AC.
* Corriente del sistema: capacidad para medir con precisión corriente alterna en sistemas monofásicos, bifásicos y trifásicos, en un rango de 0 a 100 A AC.
* Tensión de batería: capacidad para medir con precisión el voltaje de la batería del sistema electromecánico (cuando aplique) y estimar su estado de carga (SoC).
* Detección de eventos: Capacidad para detectar eventos de encendido y apagado en el sistema electromecánico. 
## Requerimientos

El módulo, además de medir corriente y tensión en sistemas trifásicos, debe transmitir la información de forma inalámbrica mediante tecnología LoRaWAN, enviándola a un gateway ubicado a pocos metros o a decenas de metros del módulo de adquisición. Asimismo, debe garantizar transmisión ininterrumpida, por lo que requiere capacidad de operación autónoma cuando la fuente de alimentación principal esté desactivada.

### [Placa de monitoreo de variables electromecánicas Monitor](./hardware/kicad/Placa_Monitor.md)

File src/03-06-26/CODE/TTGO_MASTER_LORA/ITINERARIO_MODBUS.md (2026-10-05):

# Itinerario Modbus — `TTGO_MASTER_LORA` (versión ÚLTIMA)

Master Modbus RTU sobre LoRaWAN (ESP32 / TTGO LoRa32 v2.1).
Arquitectura **table-driven**: una tabla estática de lecturas y una sola tarea de polling.

- **Dispositivo actual**: medidor trifásico `DEV_TRIFASICO_NUEVO` (slave **1**).
- **Base commiteada de referencia**: `origin/main` → `4a03fc7`
  (`DEV_TRIFASICO_NUEVO`, polling cada 30 s, `-D SINGLE_CHANNEL_MODE` + `pre:apply_lmic_patch.py`).

---

## 1. Configuración del bus RS485 (`kBusCfg`)

| Parámetro | Valor |
|---|---|
| Baud rate | `9600` |
| UART config | `SERIAL_8N1` |
| RX pin | `13` |
| TX pin | `12` |
| Timeout por defecto | `2000 ms` |

Archivo: `include/ModbusConfig.h`.

## 2. Configuración por dispositivo (`kDeviceCfg`)

| Slave | Function code | `swapWords` | Timeout |
|---|---|---|---|
| `DEV_TRIFASICO_NUEVO` = **1** | `0x04` (input registers) | `true` (byte bajo primero / little-endian por registro) | `2000 ms` |

Los helpers `lookupFunctionCode()`, `lookupTimeout()` y `lookupSwapWords()` resuelven
estos valores por `slaveID`; si no hay entrada, se usa `0x03`, `kBusCfg.defaultTimeoutMs` y `false`.

## 3. Itinerario de instrucciones (`kRequests[]`)

Orden exacto en que se ejecutan las lecturas (el `channelIndex` documenta el orden dentro
de cada `sensorType`; la agrupación real sigue el orden de la tabla):

| # | sensorType (bit) | Dirección | #regs | canal | `swapWordOrder` | Descripción |
|---|---|---|---|---|---|---|
| 1 | BATERIA (0) | `0x003A` | 2 | 0 | `true` | Energía activa total (32-bit, LOW word first) |
| 2 | VOLTAJE (1) | `0x0000` | 1 | 0 | `false` | V Fase A (16-bit, 0.1 V) |
| 3 | VOLTAJE (1) | `0x0001` | 1 | 1 | `false` | V Fase B |
| 4 | VOLTAJE (1) | `0x0002` | 1 | 2 | `false` | V Fase C |
| 5 | CORRIENTE (2) | `0x0003` | 1 | 0 | `false` | I Fase A (16-bit, 0.01 A) |
| 6 | CORRIENTE (2) | `0x0004` | 1 | 1 | `false` | I Fase B |
| 7 | CORRIENTE (2) | `0x0005` | 1 | 2 | `false` | I Fase C |
| 8 | EXT+0 (3) | `0x0020` | 2 | 0 | `true` | Potencia activa total (int32, LOW word first) |
| 9 | EXT+1 (4) | `0x0024` | 2 | 0 | `true` | Potencia aparente total (int32 signed) |
| 10 | EXT+2 (5) | `0x0022` | 2 | 0 | `true` | Potencia reactiva total (int32 signed) |
| 11 | EXT+3 (6) | `0x0027` | 1 | 0 | `false` | Factor de potencia combinado |
| 12 | EXT+4 (7) | `0x0006` | 1 | 0 | `false` | Frecuencia fase A (0.01 Hz) |

Total: **12 requests**.

## 4. Cómo las toma (`mainPollingTask`, `src/main.cpp`)

Cada `POLL_INTERVAL_MS` se ejecuta un ciclo completo:

1. **Resolver parámetros**: `fnCode`, `timeout` y `swapWords` desde `kDeviceCfg`.
2. **Lectura**: `modbus_api_read_registers(slaveID, fnCode, startAddr, numRegs, timeout)`.
3. **Orden de bytes** del registro: si `swapWords`, se emite `lo,hi`; si no, `hi,lo`.
4. **Padding** de cada request a múltiplo de 4 bytes (se anteponen ceros).
5. **`swapWordOrder`**: si aplica, intercambia palabra alta/baja (`bytes[0]↔[2]`, `bytes[1]↔[3]`).
6. **Agrupación** por `sensorType` concatenando los bytes en el orden de la tabla.
7. **Fallo parcial**: si un request falla, se marca `failedTypes[sensorType]` y ese tipo
   completo se descarta del payload.
8. **Cierre de grupo**: se rellena a múltiplo de 4; `regsPerChannel = size / 4`.
9. **Payload**: `construirPayloadUnificado(msgId, payloads)`.
10. **Envío**: `xQueueSend(queueFragmentos, ...)` → tarea LoRa (`LMIC_setTxData2`).

## 5. Formato del payload LoRa

```
[ msgId(1B) ][ timestamp(4B BE / UNIX) ][ activateByte(1B) ][ lenBytes(1B c/u) ][ dataBlocks ]
```

- `activateByte`: un bit por `sensorType` (definidos en `include/SensorRegistry.h`).
  - bit 0 = BATERIA, bit 1 = VOLTAJE, bit 2 = CORRIENTE, bits 3..7 = EXT+0..EXT+4.
- `lenBytes`: un byte por bit activo, en orden LSB→MSB; valor = registros por canal (`& 0x1F`).
- `dataBlocks`: bloques de datos en el mismo orden; cada canal ocupa 32 bits (4 bytes).

## 6. Build (`platformio.ini`)

```
[env:ttgo-lora32-v21]
platform = espressif32
board = ttgo-lora32-v21
framework = arduino
monitor_speed = 921600
lib_deps =
  ModbusClient=https://github.com/eModbus/eModbus.git
  mcci-catena/MCCI LoRaWAN LMIC library@^5.0.1
  adafruit/Adafruit SSD1306@^2.5.15
build_flags =
  -D ARDUINO_LMIC_PROJECT_CONFIG_H_SUPPRESS
  -D CFG_us915
  -D CFG_sx1276_radio
  -D SINGLE_CHANNEL_MODE
extra_scripts =
  pre:apply_lmic_patch.py
```

`SINGLE_CHANNEL_MODE` (en `initLoRa()`): `LMIC_selectSubBand(0)`, deshabilita canales
1..7 y 64 → modo gateway de canal único. Sin el flag, usa `LMIC_selectSubBand(7)`.
`apply_lmic_patch.py` parchea la librería LMIC durante el build.

## 7. Estado de esta carpeta

- Código local basado en `main` con el intervalo de polling extendido a
  `POLL_INTERVAL_MS = 600000` (10 min). **Sin auto-restart.**
- Incluye `-D SINGLE_CHANNEL_MODE` + `pre:apply_lmic_patch.py` (gateway de canal único),
  ya integrado en `main` (commit `4a03fc7`, merge `9eb61bb`).
- La tabla `kRequests[]`, el flujo y el payload son idénticos a la versión 630.

### Requisito local NO versionado: `include/loraconfig.h`

Contiene las credenciales LoRaWAN y está en `.gitignore` (no viaja en git). Debe existir
para compilar; sin él aparece `fatal error: loraconfig.h: No such file or directory`.

## 8. Diferencias con la versión 630

| Aspecto | Esta versión (3 fases) | `TTGO_MASTER_LORA_630` |
|---|---|---|
| Slave ID | 1 | 10 |
| `swapWords` | `true` (byte bajo primero) | `false` (byte alto primero) |
| Formato | 16-bit (V/I) + int32 LOW-word-first | float IEEE-754 32-bit (MSB primero) |
| Requests | 12 | 11 |
| Tensión | F-N L1/L2/L3 | F-F L1L2/L2L3/L3L1 |
| Energía | total `0x003A` | total `0x0156` |
| Macros LMIC | `SINGLE_CHANNEL_MODE` + parche | no |

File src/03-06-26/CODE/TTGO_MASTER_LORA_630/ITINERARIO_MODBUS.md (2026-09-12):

# Itinerario Modbus — `TTGO_MASTER_LORA_630` (copia congelada)

Master Modbus RTU sobre LoRaWAN (ESP32 / TTGO LoRa32 v2.1).
Arquitectura **table-driven**: una tabla estática de lecturas y una sola tarea de polling.

- **Snapshot congelado** del commit **`96ad3a6`** (rama `backup-sdm630`).
- **Dispositivo**: analizador Eastron **SDM630MCT** (`DEV_SDM`, slave **10**, float IEEE-754 32-bit).
- Reprogramable tal cual: es un proyecto PlatformIO completo e independiente.

---

## 1. Configuración del bus RS485 (`kBusCfg`)

| Parámetro | Valor |
|---|---|
| Baud rate | `9600` |
| UART config | `SERIAL_8N1` |
| RX pin | `13` |
| TX pin | `12` |
| Timeout por defecto | `2000 ms` |

Archivo: `include/ModbusConfig.h`.

## 2. Configuración por dispositivo (`kDeviceCfg`)

| Slave | Function code | `swapWords` | Timeout |
|---|---|---|---|
| `DEV_SDM` = **10** | `0x04` (input registers) | `false` (byte alto primero / MSB register first) | `2000 ms` |

Los helpers `lookupFunctionCode()`, `lookupTimeout()` y `lookupSwapWords()` resuelven
estos valores por `slaveID`; si no hay entrada, se usa `0x03`, `kBusCfg.defaultTimeoutMs` y `false`.

## 3. Itinerario de instrucciones (`kRequests[]`)

Orden exacto en que se ejecutan las lecturas (todas float 32-bit = 2 registros):

| # | sensorType (bit) | Dirección | #regs | canal | `swapWordOrder` | Registro SDM630 | Descripción |
|---|---|---|---|---|---|---|---|
| 1 | BATERIA (0) | `0x0156` | 2 | 0 | `false` | 30343 | Energía activa total (kWh) |
| 2 | VOLTAJE (1) | `0x00C8` | 2 | 0 | `false` | 30201 | V L1-L2 |
| 3 | VOLTAJE (1) | `0x00CA` | 2 | 1 | `false` | 30203 | V L2-L3 |
| 4 | VOLTAJE (1) | `0x00CC` | 2 | 2 | `false` | 30205 | V L3-L1 |
| 5 | CORRIENTE (2) | `0x0006` | 2 | 0 | `false` | 30007 | I L1 |
| 6 | CORRIENTE (2) | `0x0008` | 2 | 1 | `false` | 30009 | I L2 |
| 7 | CORRIENTE (2) | `0x000A` | 2 | 2 | `false` | 30011 | I L3 |
| 8 | EXT+0 (3) | `0x0034` | 2 | 0 | `false` | 30053 | Potencia activa total (P) |
| 9 | EXT+1 (4) | `0x0038` | 2 | 0 | `false` | 30057 | Potencia aparente total (S) |
| 10 | EXT+2 (5) | `0x003C` | 2 | 0 | `false` | 30061 | Potencia reactiva total (Q) |
| 11 | EXT+3 (6) | `0x003E` | 2 | 0 | `false` | 30063 | Factor de potencia total (PF) |
| 12 | EXT+4 (7) | `0x0046` | 2 | 0 | `false` | 30071 | Frecuencia |

Total: **11 requests** (comparten `SENSOR_ID_EXT_START + n` para P/S/Q/PF/Frecuencia).

## 4. Cómo las toma (`mainPollingTask`, `src/main.cpp`)

Cada `POLL_INTERVAL_MS` (30 s) se ejecuta un ciclo completo:

1. **Resolver parámetros**: `fnCode`, `timeout` y `swapWords` desde `kDeviceCfg`.
2. **Lectura**: `modbus_api_read_registers(slaveID, fnCode, startAddr, numRegs, timeout)`.
3. **Orden de bytes** del registro: si `swapWords` (aquí `false`), emite `hi,lo`.
4. **Padding** de cada request a múltiplo de 4 bytes (se anteponen ceros).
5. **`swapWordOrder`**: si aplica (aquí `false`), intercambia palabra alta/baja.
6. **Agrupación** por `sensorType` concatenando los bytes en el orden de la tabla.
7. **Fallo parcial**: si un request falla, se marca `failedTypes[sensorType]` y ese tipo
   completo se descarta del payload.
8. **Cierre de grupo**: se rellena a múltiplo de 4; `regsPerChannel = size / 4`.
9. **Payload**: `construirPayloadUnificado(msgId, payloads)`.
10. **Envío**: `xQueueSend(queueFragmentos, ...)` → tarea LoRa (`LMIC_setTxData2`).

> Nota: en este commit **no** existe el retardo inter-frame de 10 ms entre lecturas
> (se añadió después en `3439a67`) ni auto-reinicio por cantidad de mensajes.

## 5. Formato del payload LoRa

```
[ msgId(1B) ][ timestamp(4B BE / UNIX) ][ activateByte(1B) ][ lenBytes(1B c/u) ][ dataBlocks ]
```

- `activateByte`: un bit por `sensorType` (definidos en `include/SensorRegistry.h`).
  - bit 0 = BATERIA, bit 1 = VOLTAJE, bit 2 = CORRIENTE, bits 3..7 = EXT+0..EXT+4.
- `lenBytes`: un byte por bit activo, en orden LSB→MSB; valor = registros por canal (`& 0x1F`).
- `dataBlocks`: bloques de datos en el mismo orden; cada canal ocupa 32 bits (4 bytes).

## 6. Build (`platformio.ini`)

```
[env:ttgo-lora32-v21]
platform = espressif32
board = ttgo-lora32-v21
framework = arduino
monitor_speed = 921600
lib_deps =
  ModbusClient=https://github.com/eModbus/eModbus.git
  mcci-catena/MCCI LoRaWAN LMIC library@^5.0.1
  adafruit/Adafruit SSD1306@^2.5.15
build_flags =
  -D ARDUINO_LMIC_PROJECT_CONFIG_H_SUPPRESS
  -D CFG_us915
  -D CFG_sx1276_radio
```

Sin `SINGLE_CHANNEL_MODE` y sin `apply_lmic_patch.py` (pasó a subbanda 7 estándar).
Para reprogramar un gateway de canal único habría que añadir esos dos elementos.

## 7. Requisito local NO versionado: `include/loraconfig.h`

`include/loraconfig.h` está en `.gitignore` porque contiene las credenciales LoRaWAN
(`DEVADDR`, `NWKSKEY`, `APPSKEY`, etc.). **No se incluye en los snapshots de git**, así que
hay que colocarlo manualmente para poder compilar (error típico:
`fatal error: loraconfig.h: No such file or directory`).

- En este snapshot ya se copió desde `TTGO_MASTER_LORA/include/loraconfig.h`.
- Para el dispositivo 630 debes ajustar ahí su `DEVADDR` / `NWKSKEY` / `APPSKEY` propios.

## 8. Diferencias con la versión última (3 fases)

| Aspecto | Esta versión (630) | `TTGO_MASTER_LORA` |
|---|---|---|
| Slave ID | 10 | 1 |
| `swapWords` | `false` (byte alto primero) | `true` (byte bajo primero) |
| Formato | float IEEE-754 32-bit (MSB primero) | 16-bit (V/I) + int32 LOW-word-first |
| Requests | 11 | 12 |
| Tensión | F-F L1L2/L2L3/L3L1 | F-N L1/L2/L3 |
| Energía | total `0x0156` | total `0x003A` |
| Macros LMIC | no | `SINGLE_CHANNEL_MODE` + parche |

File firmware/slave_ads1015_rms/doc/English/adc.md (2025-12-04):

@file adc.md
@defgroup group_adc_rms ADC Processing and RMS Calculation

@section group_adc_rms_overview Overview
This module implements analog signal acquisition via ADS1015 and the complete flow of:
- ADC sample acquisition in round-robin mode between 3 channels using interrupts.
- Real-time processing with circular FIFOs for efficient RMS calculation.
- RMS value history storage in thread-safe buffers.
- Application of channel-specific conversion factors for individual calibration.

@section Structure_and_components Structure and Components

- Data and configuration
  - ADC_Sample: sample structure with value and associated channel.
  - RMS_FIFO: circular buffer with cumulative sums for incremental calculation.
  - CONVERSION_FACTORS[]: channel-specific calibration factors.

- Acquisition and processing
  - queue_adc_samples: FreeRTOS queue for acquisition → processing transfer.
  - fifos[NUM_CHANNELS]: array of circular FIFOs for each channel.
  - rms_history_ch0/ch1/ch2: independent histories of RMS values.

- Main tasks
  - `task_adquisicion`: ADC conversion management with improved multiplexer.
  - `task_procesamiento`: incremental RMS calculation and history update.
  - ISR: `on_adc_data_ready()` for conversion completion notification.

@section group_adc_rms_api Main API
- Configuration: `FIFO_SIZE`, `PROCESS_INTERVAL_MS`, `RMS_HISTORY_SIZE`, `CONVERSION_FACTORS[]`.
- Structures: `ADC_Sample`, `RMS_FIFO`.
- Data: `queue_adc_samples`, `fifos[]`, `rms_history_ch0/ch1/ch2`, `rms_history_mutex`.
- Functions: `task_adquisicion()`, `task_procesamiento()`, `get_rms_history()`, `on_adc_data_ready()`.

@section group_adc_rms_usage Usage
Flow summary:

1) ADC initialization
   - ADS1015 configuration: TWOTHIRDS gain (±6.144V), 3300 SPS speed.
   - Interrupt configuration on ALERT pin for completed conversions.
   - Creation of `queue_adc_samples` queue with FIFO_SIZE capacity.
   - Initialization of `rms_history_mutex` mutex for history protection.

2) Sample acquisition
   - `task_adquisicion` executes on core 0 with priority 5.
   - Round-robin sequence between channels 0, 1, 2 using explicit multiplexer.
   - Direct mapping: channel → MUX configuration (SINGLE_0/SINGLE_1/SINGLE_2).
   - ISR `on_adc_data_ready()` notifies conversion completion via `adc_data_ready` flag.
   - Samples queued in `queue_adc_samples` with ADC_Sample structure.

3) RMS processing
   - `task_procesamiento` consumes samples from queue on core 0 with priority 3.
   - Circular FIFO update with incremental algorithm:
     - Sum maintenance: sum_x (∑x) and sum_x2 (∑x²).
     - Circular buffer with automatic replacement upon reaching FIFO_SIZE=320.
     - Mean calculation: μ = sum_x / count.
     - Variance calculation: σ² = (sum_x2 / count) - μ².
     - RMS value: √σ² with negative variance protection.

4) History management
   - RMS calculation every PROCESS_INTERVAL_MS=1000ms.
   - Storage in independent circular buffers per channel.
   - Thread-safe protection with `rms_history_mutex`.
   - `get_rms_history()` function for extracting last N values.

5) Channel calibration
   - `CONVERSION_FACTORS[]` array with specific factors:
     - Channel 0: 0.653f
     - Channel 1: 0.679f  
     - Channel 2: 1.133f
   - Applied in `dataUpdateTask` to compensate sensor differences.
   - Allows individual adjustment of measurement ranges and conditioning.

6) Incremental RMS algorithm
   - O(1) efficiency for new sample insertion.
   - No need to traverse entire buffer for calculation.
   - Automatic maintenance of cumulative statistics.
   - Robust overflow management in circular buffer.

Warnings and best practices:
- Verify ADS1015 power supply stability for accurate conversions.
- Configure external pullups on I2C lines if communication issues occur.
- Validate ALERT pin connection before enabling interrupts.
- Protect RMS history access with appropriate mutex timeout.
- Calibrate CONVERSION_FACTORS[] according to actual sensor characteristics.
- Monitor processing latency to avoid queue saturation.
- Verify that FIFO_SIZE is sufficient for required analysis window.

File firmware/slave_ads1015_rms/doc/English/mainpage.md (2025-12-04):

@mainpage Modbus RTU Slave Monitor with RMS Sensor

@section summary Summary
Firmware for Modbus RTU slave device on ESP32 with ADS1015 ADC, calculates real-time RMS values using circular FIFOs, maintains measurement history and responds to Modbus RTU queries over RS485 within a FreeRTOS environment.

@section deps Dependencies
 * FreeRTOS: tasks, queues, semaphores and synchronization.
 * Arduino core ESP32 + Wire/I2C + ModbusServerRTU.
 * [Adafruit_ADS1X15](https://github.com/adafruit/Adafruit_ADS1X15) for ADC communication.
 * PlatformIO as recommended toolchain.

@section groups Groups
 * `group_hardware`: pin configuration, peripherals and system initialization.
 * `group_adc_rms`: ADC acquisition, signal processing and RMS calculation with circular FIFOs.
 * `group_modbus`: Modbus RTU server, registers and RS485 communication.
 
@section flow General Flow
  1. **Startup**: `setup()` initializes Serial/I2C, ADS1015, ModbusServerRTU, queues and tasks.
  2. **ADC Configuration**: sets gain, sampling rate and interrupt mode for ADS1015.
  3. **Acquisition**: `task_adquisicion` manages round-robin conversions between channels using interrupts; queues samples in `queue_adc_samples`.
  4. **Processing**: `task_procesamiento` consumes samples, updates circular FIFOs with cumulative sums and calculates RMS periodically using incremental algorithms.
  5. **History**: RMS values are stored in thread-safe circular buffers protected by `rms_history_mutex`.
  6. **Modbus Update**: `dataUpdateTask` extracts data from history, applies conversion factor and updates `holdingRegisters`.
  7. **Modbus Responses**: `readHoldingRegistersWorker` handles read requests for configuration parameters (registers 0-7) and RMS data (registers 10+).
  8. **Debug**: `loop()` displays RMS values periodically for system verification.
 
@section data_paths Queues and Synchronization
* `queue_adc_samples`: bridge acquisition → processing of ADC samples.
* `fifos[NUM_CHANNELS]`: circular buffers for efficient RMS calculation.
* `rms_history_ch0/ch1/ch2`: independent histories for each channel.
* `holdingRegisters`: Modbus registers updated periodically.
* `rms_history_mutex` and `dataMutex`: critical synchronization for concurrent access.

@section modbus_interface Modbus Interface
* **Registers 0-7**: sensor configuration parameters (sensorID, numberOfChannels, startAddress, etc.).
* **Registers 10+**: historical RMS data organized by channel with applied conversion factor.
* **Function 03**: holding register read with address validation and error handling.
* **Discovery**: responds with `SensorData` structure for automatic identification by masters.

@section rms_algorithm RMS Algorithm
* **Circular FIFO**: 320-sample buffer with cumulative sums for efficiency.
* **Incremental calculation**: mean and variance calculated without traversing entire buffer.
* **Periodic update**: RMS values calculated every 1000ms.
* **Thread-safe**: protected access through semaphores for safe concurrency.

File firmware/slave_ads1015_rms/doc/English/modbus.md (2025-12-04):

@file modbus.md
@defgroup group_modbus Modbus Communication

@section group_modbus_overview Overview
This module implements the Modbus RTU server (ESP32) and the complete flow of:
- Response to sensor discovery requests from RS485 masters.
- Holding register management for RMS data and configuration parameters.
- Periodic data updates from the RMS processing subsystem.
- Error handling and address validation in the Modbus protocol.

@section Structure_and_components Structure and Components

- Data and configuration
  - SensorData: sensor parameter definition for discovery.
  - holdingRegisters[]: Modbus register array with RMS data.
  - sensor: global instance with device configuration.

- Communication and protocol
  - ModbusServerRTU: RTU server with configurable timeout.
  - HardwareSerial: RS485 serial port for physical communication.
  - readHoldingRegistersWorker(): main worker for function 03.

- Main tasks
  - `dataUpdateTask`: periodic register update from RMS history.
  - Callbacks: registered worker for READ_HOLD_REGISTER.

@section group_modbus_api Main API
- Configuration: `SLAVE_ID`, `NUM_REGISTERS`, `MODBUS_UPDATE_INTERVAL_MS`.
- Data: `SensorData`, `holdingRegisters[]`, `sensor`.
- Communication: `ModbusSerial`, `MBserver`, `dataMutex`.
- Functions: `dataUpdateTask()`, `readHoldingRegistersWorker()`.

@section group_modbus_usage Usage
Flow summary:

1) Modbus initialization
   - RS485 UART configuration (19200 bps, 8N1) on pins RX=20, TX=21.
   - ModbusServerRTU initialization with SLAVE_ID=1 and timeout=2000ms.
   - Worker registration for function 03 (holding register read).
   - Creation of `dataMutex` for register protection.

2) Sensor discovery
   - readHoldingRegistersWorker() responds to requests for addresses 0-7.
   - Returns SensorData structure with: sensorID=1, numberOfChannels=3, startAddress=10.
   - Includes parameters: maxRegisters=18, samplingInterval=1000ms, dataType=1, scale=1.
   - Enables automatic identification by Modbus masters.

3) Data update
   - `dataUpdateTask` runs every 300ms on core 0 with priority 1.
   - Extracts RMS history using get_rms_history() for each channel.
   - Applies CONVERSION_FACTOR=0.618 to convert to physical units.
   - Updates holdingRegisters[] thread-safely with dataMutex.

4) Data read response
   - readHoldingRegistersWorker() handles requests for addresses 10+.
   - Validates address range and number of requested registers.
   - Protects access to holdingRegisters[] with dataMutex (100ms timeout).
   - Returns RMS data organized by channel or ILLEGAL_DATA_ADDRESS error.

5) Modbus error handling
   - Validation of out-of-range addresses (>= NUM_REGISTERS).
   - SERVER_DEVICE_BUSY response if dataMutex cannot be obtained.
   - Debug logs for received ServerID and FunctionCode.

Warnings and best practices:
- Ensure consistent layout of 8 parameter registers for discovery.
- Respect data offset in Modbus RTU registers according to specification.
- Protect access to holdingRegisters[] with dataMutex in all operations.
- Verify NUM_REGISTERS limits to prevent buffer overflow.
- Maintain consistency between numberOfChannels and data organization in registers.
- Configure appropriate server timeout according to expected RS485 bus latency.

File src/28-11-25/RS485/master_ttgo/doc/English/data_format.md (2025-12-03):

@file data_format.md
@defgroup group_data_format Data Format & Payload

@section group_data_format_overview Overview
This module is responsible for:
- Parsing raw Modbus responses from `queueRespuestas`.
- Normalizing data per sensor and generating `SensorDataPayload`.
- Aggregating multiple payloads into a compact message with Activate Byte and metadata.
- Delivering ready-for-transmission fragments to the external layer (LMIC) via `queueFragmentos`.

@section Structure_and_components Structure and components

- Intermediate transport
  - ResponseFormat: raw data from `handleData()` (bytes, length, deviceId, order).

- Normalized data
  - SensorDataPayload: per-sensor packet with processed registers and metadata (sensorID, slaveID, useful length).

- Tasks/Flow
  - `DataFormatter`: decides if response is discovery or sampling, and produces `SensorDataPayload`.
  - `DataAggregatorTask`: consumes payloads, builds Activate Byte, adds headers and constructs final message.

@section group_data_format_api Main API
- Input
  - `queueRespuestas` (ResponseFormat).
- Output
  - `queueSensorDataPayload` (SensorDataPayload).
  - `queueFragmentos` (aggregated message ready for transmission).
- Utilities
  - `formatAndEnqueueSensorData()` (extraction and formatting).
  - `parseAndStoreDiscoveryResponse()` (discovery; updates structures).
  - `construirPayloadUnificado()` (aggregation).
  - `BitPacker` optional compression by `compressedBytes`.

@section group_data_format_usage Usage
Flow summary:

1) Response formatting
   - `DataFormatter` reads `ResponseFormat` from `queueRespuestas`.
   - Discovery: validates structure and delegates sensor parameter update (see group \ref group_modbus_discovery "Modbus").
   - Sampling: extracts registers, applies `dataType`, `scale` and compression if `compressedBytes > 0`.
   - Generates `SensorDataPayload` and publishes it to `queueSensorDataPayload`.

2) Payload aggregation
   - `DataAggregatorTask` consumes `SensorDataPayload` within a fixed interval.
   - Builds Activate Byte per present sensor and calculates lengths per channel.
   - Calls `construirPayloadUnificado()` and publishes result to `queueFragmentos`.

3) Delivery to transmission
   - The aggregated fragment is ready to be taken by the external transmission task.

@section Structure_and_encoding Structure and payload encoding

The firmware uses an optimized binary scheme to maximize transmission efficiency over LoRaWAN. This section describes the payload structure to facilitate decoder implementation.

Payload components:

- Header (1 byte): Message identifier to maintain reception order.
- Timestamp (4 bytes): Time mark since system startup in UNIX format.
- Activate byte (1 byte): Flags indicating operation by sensor type, encoded bit by bit (Bit 0 = battery, Bit 1 = voltage, Bit 2 = current; rest reserved).
- Data length bytes (depend on Activate byte): Define quantity and encoding format for each active sensor type. The number of these bytes equals the number of active sensors indicated in the Activate byte.

Structure of each length byte (8 bits):

```
Bit 7 | Bit 6 | Bit 5 | Bit 4 | Bit 3 | Bit 2 | Bit 1 | Bit 0
------|-------|-------|-------|-------|-------|-------|-------
PKD   | 2BIT  |               DATA_LENGTH (5 bits)
```

Field descriptions:

- Bits 0-4 (DATA_LENGTH): Number of sensor readings (0–31 samples).
- Bit 6 (2BIT):
  - 0: Standard encoding (1 bit per sample).
  - 1: 2-bit per sample encoding.
- Bit 7 (PKD):
  - 0: Byte-aligned format.
  - 1: Bit-level packed format.

Length byte order:

Length bytes follow the same order as the Activate byte flags (LSB → MSB):

- Bit 0: Battery (if active)
- Bit 1: Voltage (if active)
- Bit 2: Current (if active)

Example: If Activate byte = 0x06 (voltage + current active), there will be 2 length bytes: first for voltage, second for current.

- Data bytes: Bytes with sensor data; both the Activate byte and length bytes are necessary to decode this data.

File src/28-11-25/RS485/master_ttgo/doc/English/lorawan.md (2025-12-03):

@file lorawan.md
@defgroup group_lorawan LoRaWAN

@section group_lorawan_overview Overview
This module manages LoRaWAN transmission using LMIC:
- Initializes the LMIC stack and device HAL (TTGO LORA 32 V2.1).
- Manages frame construction and transmission from `queueFragmentos`.
- Monitors LMIC events (EV_TXCOMPLETE, join, duty cycle) and synchronizes via `semaforoEnvioCompleto`.

@section Structure_and_components Structure and components

- Configuration
  - Network parameters (OTAA/ABP), channels and region.
  - HAL and SPI/Radio pinmap.

- Transport to LMIC
  - Fragment: binary block ready for transmission (produced by aggregation in Data Format).

- Tasks/Callbacks
  - `tareaLoRa`: takes fragments from `queueFragmentos` and calls `LMIC_setTxData2`.
  - `tareaRunLoop`: executes `os_runloop_once` to process LMIC events.
  - `onEvent()`: event callback (EV_TXCOMPLETE, EV_JOINED, EV_LINK_DEAD, etc.).

@section group_lorawan_api Main API
- Input
  - `queueFragmentos` (payload ready for TX).
- Output
  - Signaling via `semaforoEnvioCompleto` after EV_TXCOMPLETE.
- Functions/Callbacks
  - `LMIC_setTxData2(port, data, len, confirmed)`.
  - `onEvent(ev)` state and error handling.
  - `tareaLoRa`, `tareaRunLoop`.
- Configuration
  - `LMIC_reset()`, `LMIC_setTxData2()`, `LMIC_setClockError()`, channel/region setup.

@section group_lorawan_usage Usage
Flow summary:

1) LoRaWAN startup
   - Initializes HAL/SPI/Radio and resets LMIC (`LMIC_reset()`).
   - Configures OTAA/ABP, region and channels.
   - Creates `tareaRunLoop` and `tareaLoRa`.

2) Data transmission
   - `tareaLoRa` blocks on `queueFragmentos`, builds frame and calls `LMIC_setTxData2`.
   - Avoids collisions by checking `LMIC.opmode & OP_TXRXPEND`.

3) LMIC events
   - `onEvent(EV_TXCOMPLETE)`: releases `semaforoEnvioCompleto` and optionally schedules next transmission.
   - `onEvent(EV_JOINED/EV_JOINING)`: controls join state.
   - Handles duty cycle and retries according to region.

Best practices (LoRaWAN)
- Check `OP_TXRXPEND` before sending to avoid breaking duty cycle.
- Use consistent application ports and payload sizes within regional limits.
- Minimize work inside `onEvent`; delegate to tasks when possible.
- Adjust `LMIC_setClockError()` if crystal has notable deviation.
- Ensure join retry with backoff and log states for diagnostics.

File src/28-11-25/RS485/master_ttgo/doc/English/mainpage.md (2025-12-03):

@mainpage Modbus RTU Master Monitor

@section summary Summary
Firmware for a Modbus RTU master gateway on ESP32 TTGO LORA 32 V2.1 based on RS485, schedules periodic readings, normalizes data and transmits it via LoRaWAN (LMIC) within a FreeRTOS environment.

@section deps Dependencies
 * FreeRTOS: tasks, queues, semaphores and synchronization.
 * Arduino core ESP32 + SPI/UART + ModbusClientRTU.
 * [LMIC (LoRaWAN)](https://github.com/mcci-catena/arduino-lmic) and associated HAL stack.
 * PlatformIO as recommended toolchain.

@section groups Groups
 * `group_modbus_discovery`: Pure Modbus (discovery, scheduler, EventManager, callbacks, tokens).
 * `group_data_format`: parsing and response normalization.
 * `group_lorawan`: LMIC and transmission.
 
@section flow General flow
  1. **Startup**: `setup()` initializes Serial/SPI, ModbusClientRTU, queues and tasks.
  2. **Discovery**: `initialDiscoveryTask` issues FC03→EventManager orders, which delegates to MB; `parseAndStoreDiscoveryResponse` fills `slaveList`.
  3. **Scheduling**: `initScheduler` derives `scheduleList`; `DataRequestScheduler` publishes sampling events to `queueEventos_Scheduler`.
  4. **Event management**: `EventManager` prioritizes scheduler vs peripheral, creates tokens, invokes `MB.addRequest` and registers context in `requestBuffer`.
  5. **Modbus callbacks**: `handleData`/`handleError` encapsulate responses and send them to `queueRespuestas`, updating failures and cleaning scheduler as needed.
  6. **Formatting**: `DataFormatter` decides if response is discovery or sampling; uses `BitPacker` and `formatAndEnqueueSensorData` to generate `SensorDataPayload` and sends them to `queueSensorDataPayload`.
  7. **Aggregation**: `DataAggregatorTask` consumes payloads, builds an Activate Byte and constructs the final message with `construirPayloadUnificado`, which deposits to `queueFragmentos`.
  8. **LoRaWAN transmission**: `tareaLoRa` takes fragments, waits for `semaforoEnvioCompleto` and calls `LMIC_setTxData2`; `tareaRunLoop` maintains `os_runloop_once`.
 
@section data_paths Queues and synchronization
* `queueEventos_Peripheral` and `queueEventos_Scheduler`: input to EventManager.
* `queueRespuestas`: bridge callbacks → formatter.
* `queueSensorDataPayload`: normalized data ready for aggregation.
* `queueFragmentos`: packets ready for LMIC.
* `schedulerMutex` and `semaforoEnvioCompleto`: critical synchronization.

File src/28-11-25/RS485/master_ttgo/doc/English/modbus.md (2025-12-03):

@file modbus.md
@defgroup group_modbus_discovery Modbus Core

@section group_modbus_overview Overview
This module implements the Modbus RTU client (ESP32/TTGO) and the complete flow of:
- Initial sensor discovery on RS485 slaves.
- Periodic reading scheduling (Scheduler) based on each sensor's parameters.
- Response and error management with token correlation.
- Data formatting in payloads per sensor and aggregation in a LoRaWAN payload.

@section Structure_and_components Structure and components

- Data and configuration
  - ModbusSensorParam, ModbusSlaveParam: sensor and slave definitions.
  - SensorSchedule: sampling scheduler entries.
  - ResponseFormat: internal response transport from callbacks.

- Requests and correlation
  - ModbusRequestInfo: asynchronous request tracking by token.
  - API: addRequest(), findRequestByToken(), DiscoveryOrder, RequestType.

- Main tasks
  - `initialDiscoveryTask`: sensor discovery.
  - `EventManager`: translates events into Modbus transactions and registers tokens.
  - `DataRequestScheduler`: generates sampling events according to scheduleList.
  - Callbacks: `handleData` and `handleError`.

@section group_modbus_api Main API
- Data/Config: `ModbusSensorParam`, `ModbusSlaveParam`, `SensorSchedule`.
- Transport: `ResponseFormat`.
- Requests: `ModbusRequestInfo`, `DiscoveryOrder`, `RequestType`, `addRequest()`, `findRequestByToken()`.
- Callbacks/Tasks: `initialDiscoveryTask`, `handleData`, `handleError`, `EventManager`, `DataRequestScheduler`.

@section group_modbus_usage Usage
Flow summary:

1) Modbus startup
   - Initializes UART RS485 and ModbusClientRTU (timeout/begin).
   - Registers callbacks: handleData(), handleError().
   - Creates tasks: EventManager and DataRequestScheduler.
   - Launches initialDiscoveryTask with devicesToQuery.

2) Discovery
   - initialDiscoveryTask publishes order=DISCOVERY_READ_SENSOR_PARAM.
   - EventManager sends read request (addr=0, qty=8) and registers token.
   - handleData() parses and updates slaveList with parseAndStoreDiscoveryResponse().
   - initScheduler() calculates scheduleList.

3) Periodic sampling
   - DataRequestScheduler triggers REQUEST_SAMPLING according to nextSampleTime.
   - EventManager queries getSensorParams() and sends read request with startAddress/numRegs.
   - handleData() delivers registers to the next subsystem.

4) Modbus errors
   - handleError(): handles TIMEOUT, increases consecutiveFails, removes inactive slaves and recalculates scheduler.
   - Tokens are invalidated after processing.

Warnings and best practices:
- Ensure consistent layout of 8 parameter registers for discovery.
- Respect offset 3 for register data in Modbus RTU responses.
- Protect scheduleList access with `schedulerMutex`.
- Review `MAX_*` limits to avoid overflow in queues and tokens.

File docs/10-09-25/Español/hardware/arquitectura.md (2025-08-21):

# Arquitectura del Sistema

El sistema se compone de un controlador central responsable de la adquisición, procesamiento y transmisión de datos, apoyado por múltiples transductores y módulos de acondicionamiento que adaptan las distintas señales para su correcta lectura e interpretación por el controlador.

![[../../res/img/hardware/Arquitecruta_Sistema.drawio.svg]]

Las señales crudas pasan por acondicionamiento, son digitalizadas por el controlador, procesadas y clasificadas, y finalmente serializadas en vectores de datos para su envío por LoRaWAN. El gateway recibe y reenvía los datos a la plataforma de backend donde se almacenan y explotan.

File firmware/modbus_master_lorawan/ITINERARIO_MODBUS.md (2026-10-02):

# Itinerario Modbus — `TTGO_MASTER_MODBUS_LORA`

Master Modbus RTU sobre LoRaWAN (ESP32 / TTGO LoRa32 v2.1).
Arquitectura **table-driven**: una tabla estática de lecturas y una sola tarea de polling.

- **Dispositivo**: medidor trifásico **`DEV_TRIFASICO_NUEVO`** (slave **1**, `u16`/`int32` little-endian por registro, ver `manual_modbus_rtu_clean.txt`).
- Reprogramable tal cual: es un proyecto PlatformIO completo e independiente.
- **Stack LoRaWAN**: **RadioLib** (migrado desde MCCI LMIC). Activación **OTAA**, **Class A**.
  Rejoin en cada arranque; solo se persisten los **nonces** en NVS (`Preferences`).

---

## 1. Configuración del bus RS485 (`kBusCfg`)

| Parámetro | Valor |
|---|---|
| Baud rate | `9600` |
| UART config | `SERIAL_8N1` |
| RX pin | `13` |
| TX pin | `12` |
| Timeout por defecto | `2000 ms` |

Archivo: `include/ModbusConfig.h`.

## 2. Configuración por dispositivo (`kDeviceCfg`)

| Slave | Function code | `swapWords` | Timeout |
|---|---|---|---|
| `DEV_TRIFASICO_NUEVO` = **1** | `0x04` (input registers) | `true` (byte bajo primero / little-endian por registro) | `2000 ms` |

Los helpers `lookupFunctionCode()`, `lookupTimeout()` y `lookupSwapWords()` resuelven
estos valores por `slaveID`; si no hay entrada, se usa `0x03`, `kBusCfg.defaultTimeoutMs` y `false`.

## 3. Itinerario de instrucciones (`kRequests[]`)

Orden exacto en que se ejecutan las lecturas (el `channelIndex` documenta el orden dentro
de cada `sensorType`; la agrupación real sigue el orden de la tabla):

| # | sensorType (bit) | Dirección | #regs | canal | `swapWordOrder` | Descripción |
|---|---|---|---|---|---|---|
| 1 | BATERIA (0) | `0x003A` | 2 | 0 | `true` | Energía activa total (32-bit, LOW word first) |
| 2 | VOLTAJE (1) | `0x0000` | 1 | 0 | `false` | V Fase A (16-bit, 0.1 V) |
| 3 | VOLTAJE (1) | `0x0001` | 1 | 1 | `false` | V Fase B |
| 4 | VOLTAJE (1) | `0x0002` | 1 | 2 | `false` | V Fase C |
| 5 | CORRIENTE (2) | `0x0003` | 1 | 0 | `false` | I Fase A (16-bit, 0.01 A) |
| 6 | CORRIENTE (2) | `0x0004` | 1 | 1 | `false` | I Fase B |
| 7 | CORRIENTE (2) | `0x0005` | 1 | 2 | `false` | I Fase C |
| 8 | EXT+0 (3) | `0x0020` | 2 | 0 | `true` | Potencia activa total (int32, LOW word first) |
| 9 | EXT+1 (4) | `0x0024` | 2 | 0 | `true` | Potencia aparente total (int32 signed) |
| 10 | EXT+2 (5) | `0x0022` | 2 | 0 | `true` | Potencia reactiva total (int32 signed) |
| 11 | EXT+3 (6) | `0x0027` | 1 | 0 | `false` | Factor de potencia combinado |
| 12 | EXT+4 (7) | `0x0006` | 1 | 0 | `false` | Frecuencia fase A (0.01 Hz) |

Total: **12 requests**.

## 4. Cómo las toma (`mainPollingTask`, `src/main.cpp`)

Cada `POLL_INTERVAL_MS` (30 s) se ejecuta un ciclo completo:

1. **Resolver parámetros**: `fnCode`, `timeout` y `swapWords` desde `kDeviceCfg`.
2. **Lectura**: `modbus_api_read_registers(slaveID, fnCode, startAddr, numRegs, timeout)`.
3. **Orden de bytes** del registro: si `swapWords` (aquí `true`), emite `lo,hi`
   (endereza el little-endian del dispositivo a big-endian).
4. **Padding** de cada request a múltiplo de 4 bytes (se anteponen ceros).
5. **`swapWordOrder`**: si aplica (aquí `true` en los 32-bit), intercambia palabra alta/baja.
6. **Retardo inter-frame**: `vTaskDelay(10 ms)` entre lecturas (margen RS485).
7. **Agrupación** por `sensorType` concatenando los bytes en el orden de la tabla.
8. **Fallo parcial**: si un request falla, se marca `failedTypes[sensorType]` y ese tipo
   completo se descarta del payload.
9. **Cierre de grupo**: se rellena a múltiplo de 4; `regsPerChannel = size / 4`.
10. **Payload**: `construirPayloadUnificado(msgId, payloads)`.
11. **Envío**: `xQueueSend(queueFragmentos, ...)` → tarea LoRa
    (`node.sendReceive(..., FPORT_DATA, ...)` de RadioLib).
12. **Downlink**: si `sendReceive` devuelve ventana > 0, se procesan los comandos en
    `FPORT_CMD` (ver sección 9).
13. **Espera**: `ulTaskNotifyTake` con `g_pollIntervalMs` (mutable por downlink); un
    comando `FORCE_POLL` despierta el ciclo de inmediato.

> Nota: el retardo inter-frame de 10 ms entre lecturas (commit `3439a67`) **sí** está
> presente. No hay auto-reinicio por cantidad de mensajes.

## 5. Formato del payload LoRa

```
[ msgId(1B) ][ timestamp(4B BE / UNIX) ][ activateByte(1B) ][ lenBytes(1B c/u) ][ dataBlocks ]
```

- `activateByte`: un bit por `sensorType` (definidos en `include/SensorRegistry.h`).
  - bit 0 = BATERIA, bit 1 = VOLTAJE, bit 2 = CORRIENTE, bits 3..7 = EXT+0..EXT+4.
- `lenBytes`: un byte por bit activo, en orden LSB→MSB; valor = registros por canal (`& 0x1F`).
- `dataBlocks`: bloques de datos en el mismo orden; cada canal ocupa 32 bits (4 bytes).

## 6. Build (`platformio.ini`)

```
[env:ttgo-lora32-v21]
platform = espressif32
board = ttgo-lora32-v21
framework = arduino
monitor_speed = 921600
lib_deps =
  ModbusClient=https://github.com/eModbus/eModbus.git
  jgromes/RadioLib@^7.0.0
```

Sin `build_flags` de LMIC y sin `SINGLE_CHANNEL_MODE`/`apply_lmic_patch.py`.

### Pinout de radio (TTGO LoRa32 v2.1)

| Señal | GPIO |
|---|---|
| NSS/CS | 18 |
| DIO0/IRQ | 26 |
| RST | 23 |
| DIO1 | 33 |

Definido en `src/main.cpp`: `SX1276 radio = new Module(18, 26, 23, 33);`.

### Subbanda US915

`LoRaWANNode node(&radio, &US915, LORAWAN_SUB_BAND);` con `LORAWAN_SUB_BAND = 2`.
RadioLib indexa las subbandas **desde 1**: subbanda **2** = **FSB 2** (canales 8-15),
que es la que tiene configurada el gateway. Debe coincidir con el `FSB` del gateway.

## 7. Requisito local NO versionado: `include/loraconfig.h`

`include/loraconfig.h` está en `.gitignore` porque contiene las credenciales LoRaWAN.
**No se incluye en los snapshots de git**, así que hay que colocarlo manualmente para poder
compilar (error típico: `fatal error: loraconfig.h: No such file or directory`).

Ahora usa **OTAA** (placeholders `0x00...` por defecto):

| Símbolo | Bytes | Descripción |
|---|---|---|
| `DEVEUI[8]` | 8 | Device EUI (MSB primero) |
| `JOINEUI[8]` | 8 | Join/App EUI (todo ceros es válido en desarrollo) |
| `APPKEY[16]` | 16 | Application root key |
| `NWKKEY[16]` | 16 | Network root key (LoRaWAN 1.0.x: igual a `APPKEY`) |

El helper `lorawan_eui_to_uint64()` empaqueta los EUI big-endian al `uint64_t` de RadioLib.

## 8. Diferencias con la versión SDM630

| Aspecto | Esta versión (trifásico) | `TTGO_MASTER_LORA_630` (SDM630MCT) |
|---|---|---|
| Slave ID | 1 | 10 |
| `swapWords` | `true` (byte bajo primero) | `false` (byte alto primero) |
| Formato | 16-bit (V/I) + int32 LOW-word-first | float IEEE-754 32-bit (MSB primero) |
| Requests | 12 | 11 |
| Tensión | F-N A/B/C | F-F L1L2/L2L3/L3L1 |
| Energía | total `0x003A` | total `0x0156` |
| Stack LoRaWAN | RadioLib (OTAA/Class A) | LMIC (o RadioLib tras la migración) |

## 9. Downlink / control (`FPORT_CMD` = 2, Class A)

Cada uplink abre las ventanas RX1/RX2; si el servidor encola un downlink, RadioLib lo
entrega en `sendReceive()` y `handleDownlink()` lo procesa:

| Comando | Bytes | Acción |
|---|---|---|
| `0x01` SET_POLL_INTERVAL | `[1..4]` uint32 BE (ms) | Cambia `g_pollIntervalMs` (mín. 1000) |
| `0x02` FORCE_POLL | — | Despierta el ciclo de polling ya (`xTaskNotifyGive`) |
| `0x03` SET_TX_POWER | `[1]` int8 (dBm) | `node.setTxPower()` |
| `0x04` SET_DATARATE | `[1]` uint8 DR | `node.setDatarate()` (ADR debe estar off) |
| `0x05` REBOOT | — | `ESP.restart()` |
| `0x06` REJOIN | — | `node.clearSession()` + join |
| `0x07` SET_ADR | `[1]` 0/1 | `node.setADR()` |

Uplinks en `FPORT_DATA` = 1.

### Persistencia y rejoin (estrategia)

- **Se re-une en cada arranque** (OTAA). No se persiste la sesión: así el `FCnt` arranca en 0
  y el servidor acepta la sesión nueva, sin huecos de contador ni desgaste de NVS.
- Solo se persiste el **DevNonce/JoinNonce** (`saveNonces()` / `loadNonces()`), para que el
  Join Server no rechace el join por `reuse_dev_nonce`. `loadNonces()` se llama **después** de
  `beginOTAA()` (que limpia el buffer y fija el checksum).
- **Auto-rejoin**: si fallan `REJOIN_FAIL_THRESHOLD` (3) uplinks seguidos con error de radio,
  se hace `clearSession()` + join. También de forma manual con el comando `0x06`.
- **Reintentos de join en el arranque**: `joinNetwork()` intenta hasta `JOIN_MAX_ATTEMPTS`
  (5) con `JOIN_RETRY_DELAY_MS` (5 s). Si el DevNonce guardado va por detrás de la marca del
  servidor (`reuse_dev_nonce`), cada intento lo incrementa y se autocorrige en segundos.
  Loguea el **DevNonce** restaurado y el de cada intento (`readDevNonce()`).
- `joinNetwork()` aplica `setADR(false)`/`setDatarate(3)`/`setTxPower(20)` **después** de
  activar (durante el join, `selectChannels()` deja el DR en 0 y provocaría `PACKET_TOO_LONG`).

> En Class A el downlink solo puede llegar tras un uplink. Para control en cualquier
> momento habría que pasar a Class C (`node.setClass(RADIOLIB_LORAWAN_CLASS_C)` +
> `getDownlinkClassC()`).

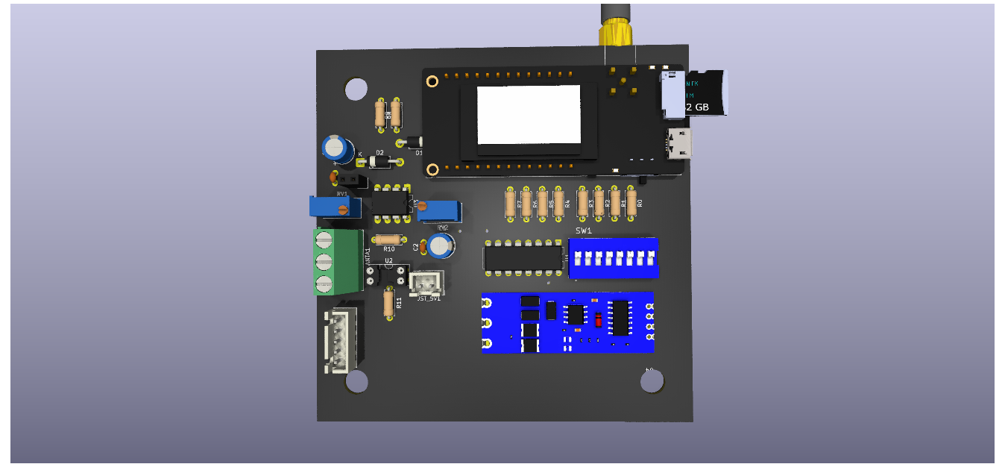
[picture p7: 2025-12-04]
hardware/monitor_rev2/docs/3D_MODEL.png

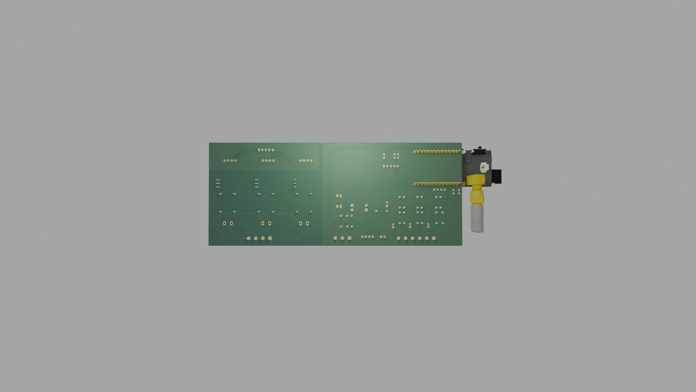
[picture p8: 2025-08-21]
docs/10-09-25/res/img/schema/3d_plate_back.png

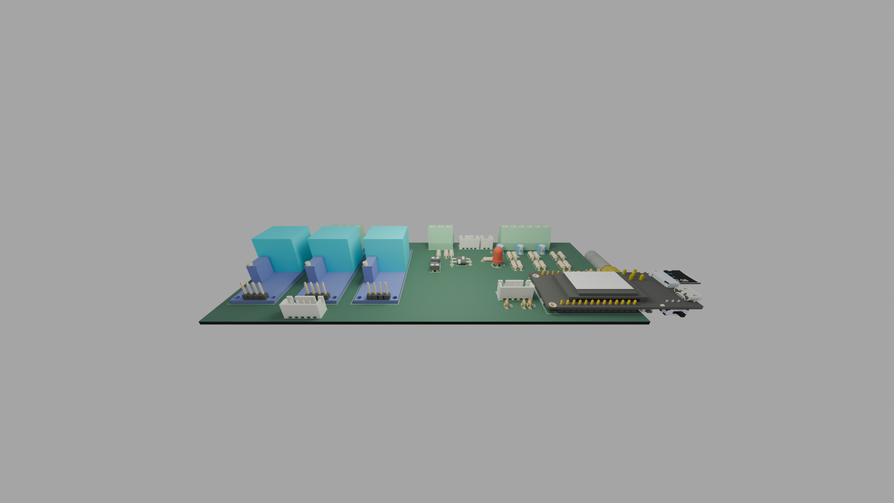
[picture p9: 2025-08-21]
docs/10-09-25/res/img/schema/3d_plate_side.png

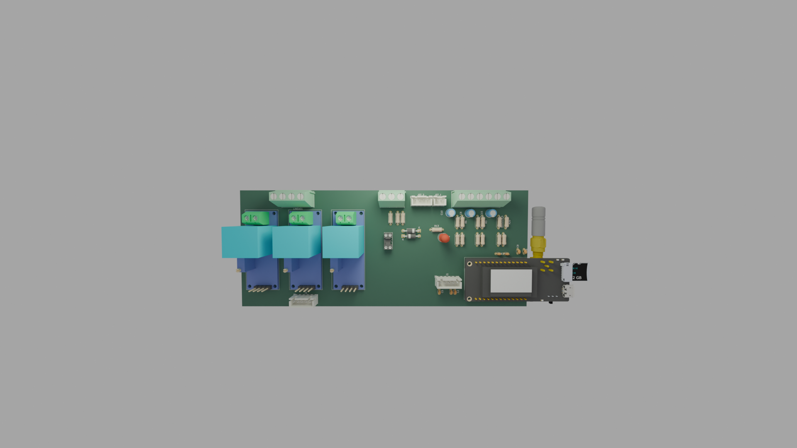
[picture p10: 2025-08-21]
docs/10-09-25/res/img/schema/3d_plate_front.png

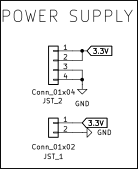
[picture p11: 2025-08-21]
docs/10-09-25/res/img/schema/POWER_SUPPLY.png

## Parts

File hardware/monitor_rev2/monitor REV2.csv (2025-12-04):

Id | Identificador | Huella | Cantidad | Identificación | Suministrador y ref
1 | R8,R9 | R_Axial_DIN0207_L6.3mm_D2.5mm_P7.62mm_Horizontal | 2 | 100k |  | SI
2 | D1,D2 | D_DO-41_SOD81_P10.16mm_Horizontal | 2 | 1N5819 |  | FALTA
3 | C4,C1 | CP_Radial_D6.3mm_P2.50mm | 2 | 100uF |  | SI
4 | C2,C3 | C_Disc_D3.0mm_W1.6mm_P2.50mm | 2 | 100nF |  | SI
5 | R6,R4,R5,R11,R1,R7,R3,R2,R0 | R_Axial_DIN0207_L6.3mm_D2.5mm_P7.62mm_Horizontal | 9 | 10k |  | FALTA
6 | RV1,RV2 | Potentiometer_Bourns_3296W_Vertical | 2 | R_Potentiometer |  | FALTA
7 | PLANTA1 | TerminalBlock_Phoenix_MKDS-1,5-3-5.08_1x03_P5.08mm_Horizontal | 1 | Screw_Terminal_01x03 |  | SI
8 | J2 | JST_XH_B5B-XH-A_1x05_P2.50mm_Vertical | 1 | Conn_01x05 |  | SI
9 | U4 | XY-017 | 1 | ~ |  | SI
10 | U3 | DIP-8_W7.62mm_LongPads | 1 | LM358 |  | FALTA
11 | U2 | DIP-4_W7.62mm_Socket_LongPads | 1 | PC817 |  | SI
12 | J1 | PinSocket_1x02_P2.54mm_Vertical | 1 | Conn_01x02_Pin |  | SI
13 | U1 | DIP-16_W7.62mm | 1 | 74HC165 |  | FALTA
14 | R10 | R_Axial_DIN0207_L6.3mm_D2.5mm_P7.62mm_Horizontal | 1 | 1.2k |  | SI
15 | JST_5V1 | JST_XH_B2B-XH-A_1x02_P2.50mm_Vertical | 1 | Conn_01x02 |  | SI
16 | SW1 | SW_DS01C-254-S-08BE | 1 | SW_DIP_x08 |  | FALTA
17 | ESP32 | ttgo_lora32 | 1 | ~ |  | SI

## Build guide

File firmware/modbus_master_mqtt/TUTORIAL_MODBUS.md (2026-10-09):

# Tutorial: como funciona y como se extiende el Modbus de `modbus_master_mqtt`

Guia practica de la variante MQTT del master Modbus. Explica la arquitectura, como
agregar lecturas (bloques y senales), como escribir funciones de decodificacion y como
llega la data a la tarea MQTT.

---

## 1. Idea general

El firmware lee el medidor por **bloques** (varios registros contiguos en una sola
peticion Modbus), decodifica cada valor con **su propia funcion**, y entrega el
resultado a la tarea MQTT por una **cola**.

```
mainPollingTask (core 0)                       tareaMqtt (core 1)
  1. por cada bloque: leer registros
  2. por cada senal: llamar su decode()
  3. armar MeasureFrame  ---- xQueueSend ---->  [ queueMqtt ] --- xQueueReceive ---> (JSON + publish)
```

Piezas clave (en `include/ModbusConfig.h`):

| Pieza | Que es |
|---|---|
| `kBlocks[]` | Que rangos de registros se leen y como (1 peticion por bloque) |
| `kSignals[]` | Cada valor: a que sensor/canal pertenece y **como decodificarlo** |
| `mb_u16/mb_i32/mb_byte` | Helpers de decodificacion (little-endian) |
| `SensorRegistry.h` | IDs logicos de sensor (`SENSOR_ID_*`) |

En `src/main.cpp`:

| Pieza | Que es |
|---|---|
| `MeasureFrame` / `SensorValues` | Estructura que viaja a la tarea MQTT (valores ya escalados) |
| `mainPollingTask` | Lee bloques, decodifica y encola |
| `tareaMqtt` | Recibe el frame y (a futuro) publica JSON |

---

## 2. El modelo de datos

### 2.1 Bloque (`ModbusBlock`)
Una peticion Modbus = un bloque.

```cpp
struct ModbusBlock {
    uint8_t  slaveID;       // esclavo (1)
    uint8_t  functionCode;  // 0x04 = input registers
    uint16_t startAddr;     // direccion inicial
    uint16_t numRegs;       // cuantos registros leer
};
```

```cpp
const ModbusBlock kBlocks[] = {
    {DEV_TRIFASICO_NUEVO, 0x04, 0x0000, 9},  // V A/B/C + I A/B/C + Freq A/B/C
    {DEV_TRIFASICO_NUEVO, 0x04, 0x0020, 6},  // P/Q/S totales
    {DEV_TRIFASICO_NUEVO, 0x04, 0x0026, 2},  // Factor de potencia
    {DEV_TRIFASICO_NUEVO, 0x04, 0x003A, 2},  // Energia activa total
};
```

### 2.2 Senal (`ModbusSignal`)
Cada valor que quieres publicar. Lleva **su funcion** `decode`.

```cpp
struct ModbusSignal {
    uint8_t sensorType;                                  // SENSOR_ID_*
    uint8_t channel;                                     // 0,1,2,3...
    uint8_t blockIndex;                                  // indice en kBlocks
    float (*decode)(const uint8_t* data, size_t len);    // como decodificar
};
```

### 2.3 Funcion de decodificacion
Recibe los **bytes crudos del bloque** (`data`, `len`) y devuelve el valor final.
Es el equivalente al `lambda` por sensor de ESPHome: tu decides como acomodar los datos.

```cpp
{SENSOR_ID_VOLTAJE, 0, 0, [](const uint8_t* d, size_t n) { return mb_u16(d, n, 0) * 0.1f; }},
```

---

## 3. Orden de bytes (importante)

El medidor **no** usa el orden Modbus estandar. Manda:

- **Dentro de cada registro:** byte bajo primero (little-endian de 16 bits).
- **En valores de 32 bits:** palabra baja primero (little-endian de 32 bits).

Resultado: en el aire, los valores son **little-endian puro**. Por eso los helpers
decodifican directo:

```cpp
uint16_t mb_u16(const uint8_t* d, size_t len, uint16_t reg);  // d[2r] | d[2r+1]<<8
int32_t  mb_i32(const uint8_t* d, size_t len, uint16_t reg);  // 4 bytes little-endian
uint8_t  mb_byte(const uint8_t* d, size_t len, uint16_t i);   // byte crudo i
```

`reg` es el **offset en registros dentro del bloque** (0 = primer registro del bloque).

> Los helpers tienen guardas de limites: si pides fuera de rango devuelven 0.

---

## 4. Como agregar una lectura

### Caso A: extender un bloque existente (registros contiguos)
Ejemplo ya aplicado: **Frecuencia B/C** (`0x0007`, `0x0008`) son contiguos al bloque 0.

1. Subir `numRegs` del bloque 0 de `7` a `9`:
   ```cpp
   {DEV_TRIFASICO_NUEVO, 0x04, 0x0000, 9},
   ```
2. Agregar las senales (mismo `sensorType`, nuevos `channel`):
   ```cpp
   {SENSOR_ID_FRECUENCIA, 1, 0, [](const uint8_t* d, size_t n) { return mb_u16(d, n, 7) * 0.01f; }},
   {SENSOR_ID_FRECUENCIA, 2, 0, [](const uint8_t* d, size_t n) { return mb_u16(d, n, 8) * 0.01f; }},
   ```
   El offset (7 y 8) es el registro **dentro del bloque** (0x0007 - 0x0000 = 7).

### Caso B: bloque nuevo (registros en otra zona)
1. Agregar el bloque:
   ```cpp
   // Potencia activa por fase A/B/C (32-bit) @0x000E..0x0013
   {DEV_TRIFASICO_NUEVO, 0x04, 0x000E, 6},
   ```
   (recuerda: es un indice nuevo, p. ej. 4)
2. Agregar las senales apuntando a ese `blockIndex`:
   ```cpp
   {SENSOR_ID_POTENCIA_ACTIVA, 0, 4, [](const uint8_t* d, size_t n) { return mb_i32(d, n, 0) * 0.1f; }}, // Fase A
   {SENSOR_ID_POTENCIA_ACTIVA, 1, 4, [](const uint8_t* d, size_t n) { return mb_i32(d, n, 2) * 0.1f; }}, // Fase B
   {SENSOR_ID_POTENCIA_ACTIVA, 2, 4, [](const uint8_t* d, size_t n) { return mb_i32(d, n, 4) * 0.1f; }}, // Fase C
   ```

> Regla: `channel` debe ser < `MQTT_MAX_CHANNELS` (hoy 4). Si necesitas mas, sube esa constante en `main.cpp`.

---

## 5. Ejemplo real: Factor de Potencia empaquetado

El medidor empaqueta **dos valores por registro** (cada byte ×0.01):

| Registro | Byte bajo | Byte alto |
|---|---|---|
| `0x0026` | Fase B | Fase A |
| `0x0027` | Combinado | Fase C |

Como el dispositivo manda **byte bajo primero**, en el aire:
- `0x0026` = `[B, A]`  -> `d[0]=B`, `d[1]=A`
- `0x0027` = `[Combinado, C]` -> `d[2]=Combinado`, `d[3]=C`

Se lee con `mb_byte`:

```cpp
{SENSOR_ID_FACTOR_POTENCIA, 0, 2, [](const uint8_t* d, size_t n) { return mb_byte(d, n, 1) * 0.01f; }}, // A
{SENSOR_ID_FACTOR_POTENCIA, 1, 2, [](const uint8_t* d, size_t n) { return mb_byte(d, n, 0) * 0.01f; }}, // B
{SENSOR_ID_FACTOR_POTENCIA, 2, 2, [](const uint8_t* d, size_t n) { return mb_byte(d, n, 3) * 0.01f; }}, // C
{SENSOR_ID_FACTOR_POTENCIA, 3, 2, [](const uint8_t* d, size_t n) { return mb_byte(d, n, 2) * 0.01f; }}, // Combinado
```

Esto es exactamente lo que pediste: **una funcion por llamada** para separar los 4 datos.

---

## 6. Como agregar un TIPO de sensor nuevo

Hoy hay 8 tipos (IDs 0..7) y `main.cpp` usa `acc[8]` / `frame.sensors[8]`.

1. Definir el ID en `include/SensorRegistry.h`:
   ```cpp
   constexpr uint8_t SENSOR_ID_MI_SENSOR = 8;
   ```
2. Subir los topes en `src/main.cpp`:
   ```cpp
   #define MQTT_MAX_SENSORS  9   // o mas
   ```
   y en `mainPollingTask` el arreglo `SensorAcc acc[8];` -> `acc[MQTT_MAX_SENSORS];`
   y el bucle `for (uint8_t st = 0; st < 8; ++st)` -> `< MQTT_MAX_SENSORS`.
3. Agregar su bloque/senal en `kBlocks`/`kSignals`.
4. (Cuando exista el paso MQTT) mapear el ID -> nombre de topic.

> Nota: los IDs 0..7 coinciden con los bits del `activateByte` del firmware LoRaWAN y
> con `codec.js`. A partir de 8 ya no existen en ese formato; son **solo para MQTT**.

---

## 7. Como llega la data a la tarea MQTT

En `mainPollingTask`:

1. Por cada bloque: `modbus_api_read_registers(...)` (sincrona).
2. Si el bloque responde, por cada senal de ese bloque: `a.value[channel] = s.decode(r.data, r.data_len);`
3. Se arma `MeasureFrame` (con `sensorId`, `channels` y los `float value[]`).
4. `xQueueSend(queueMqtt, &frame, ...)`.

En `tareaMqtt`:

```cpp
if (xQueueReceive(queueMqtt, &frame, portMAX_DELAY) == pdTRUE) {
    // el frame llego -> aqui se empaqueta JSON y se publica
}
```

- `xQueueReceive` **duerme** hasta que hay un frame; el `pdTRUE` es el "ya hay que empaquetar".
- La cola lleva una **copia** del struct: no hay memoria compartida ni carreras.

---

## 8. Como compilar y flashear

```powershell
# Compilar
& "$env:USERPROFILE\.platformio\penv\Scripts\platformio.exe" run

# Flashear (con el TTGO por USB)
& "$env:USERPROFILE\.platformio\penv\Scripts\platformio.exe" run -t upload

# Monitor serie
& "$env:USERPROFILE\.platformio\penv\Scripts\platformio.exe" device monitor
```

Credenciales WiFi/MQTT: `include/netconfig.h` (gitignored).

---

## 9. Errores comunes

| Sintoma | Causa probable |
|---|---|
| Valor negativo raro | Usaste `mb_u16` para algo con signo (potencias -> `mb_i32`) |
| Valor x10 / /10 | Escala equivocada (V x0.1, I x0.01, P/Q/S x0.1, Freq x0.01) |
| PF absurdo | Leiste el registro completo en vez de un byte (`mb_byte`) |
| "Bloque fallo: err=..." | El medidor no acepta ese rango -> divide el bloque en sub-bloques |
| Frecuencia no cambia | No extendiste `numRegs` del bloque 0 |
| Todo 0 | Revision de cableado A/B, alimentacion, direccion de esclavo |

---

## 10. Resumen del flujo para agregar algo
1. Ver el manual del medidor: direccion y escala.
2. Decidir si va en un bloque existente (contiguo) o bloque nuevo.
3. Agregar/extender `kBlocks`.
4. Agregar la senal en `kSignals` con su `decode` (usando los helpers).
5. Si es tipo nuevo: ID + subir topes en `main.cpp`.
6. Compilar y validar en el banco.

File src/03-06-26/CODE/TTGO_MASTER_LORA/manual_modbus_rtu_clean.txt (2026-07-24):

# Manual Técnico de Especificación del Protocolo - Medidor de Energía Trifásico (Modbus-RTU)

## 1. Capa Física (Physical Layer)
* **Interfaz de comunicación:** UART / RS485.
* **Configuración de parámetros serie:**
  * Velocidad de transmisión (Baud rate): Configurable.
  * Bits de datos: 8 bits.
  * Bits de parada (Stop bits): 1 bit.
  * Paridad: Ninguna (No parity).

---

## 2. Capa de Aplicación (Modbus-RTU)
* **Rol del dispositivo:** Esclavo (Slave).

### Códigos de Función Soportados

| Código (Hex) | Operación Estándar Modbus | Descripción y Aplicación |
| :--- | :--- | :--- |
| `0x03` | Read Holding Registers | Lectura de parámetros de configuración y control del esclavo. |
| `0x04` | Read Input Registers | Lectura de los resultados de las mediciones eléctricas en tiempo real. |
| `0x10` | Write Multiple Registers | Escritura de múltiples registros para modificación de parámetros. |
| `0x41` | Calibration (Propietario) | Función de uso exclusivo para calibración de fábrica (requiere contraseña). |
| `0x42` | Reset Energy (Propietario) | Comando dedicado para reinicio y puesta a cero de los contadores de energía. |

> **Nota sobre el Código de Función 0x41 (Calibración):**  
> Reservado exclusivamente para mantenimiento y calibración en fábrica. Solo se puede direccionar usando la dirección de esclavo general `0xF8`. Requiere obligatoriamente una contraseña de 16 bits cuyo valor por defecto es `0x3721`.

### Direccionamiento de Nodos (Slave Addressing)
* **Direcciones válidas de esclavos:** `0x01` a `0xF7` (1 a 247 en decimal).
* **Dirección Broadcast (`0x00`):** Difusión general desde el Maestro. Los esclavos ejecutan la acción pero no responden para evitar colisiones en el bus.
* **Dirección General/Unitaria (`0xF8`):** Reservada para entornos de un único esclavo (Single-slave environment). Utilizada principalmente para calibración y ajustes.

---

## 3. Lectura de Resultados de Medición (Función 0x04)

### Estructura de la Trama de Petición (Maestro)
`[Dirección Esclavo] + [0x04] + [Reg. Alto] + [Reg. Bajo] + [Cant. Reg. Alto] + [Cant. Reg. Bajo] + [CRC Alto] + [CRC Bajo]`  
*(Tamaño total: 8 bytes)*

### Respuestas del Esclavo
1. **Respuesta Correcta:**  
   `[Dirección Esclavo] + [0x04] + [Número de Bytes] + [Reg 1 Data Bajo] + [Reg 1 Data Alto] + ... + [CRC Alto] + [CRC Bajo]`  
   * **IMPORTANTE (Endianness / Distribución de Bytes):** A diferencia del estándar Modbus convencional, los datos de los registros de medición se transmiten con el **byte bajo primero (Low Byte First / Little Endian a nivel de registro)**, seguido por el byte alto.

2. **Respuesta de Error (Excepción Modbus):**  
   `[Dirección Esclavo] + [0x84] + [Código de Excepción] + [CRC Alto] + [CRC Bajo]`

### Códigos de Excepción / Anomalía
* `0x01` (**Illegal Function**): Código de función no soportado.
* `0x02` (**Illegal Address**): Dirección de registro fuera de rango o inválida.
* `0x03` (**Illegal Data**): Valor de datos no permitido o cantidad de registros incorrecta.
* `0x04` (**Slave Error**): Error interno en el dispositivo esclavo.

---

## 4. Mapa de Registros de Medición (Función 0x04 - Read Input Registers)

*Nota: Todos los registros son enteros sin signo (unsigned) a menos que se indique "Signed".*

| Dirección (Hex) | Descripción de la Variable | Resolución y Tipo de Dato |
| :--- | :--- | :--- |
| `0x0000` | Voltaje Fase A | LSB = 0.1 V (Unsigned, Low Byte First) |
| `0x0001` | Voltaje Fase B | LSB = 0.1 V (Unsigned) |
| `0x0002` | Voltaje Fase C | LSB = 0.1 V (Unsigned) |
| `0x0003` | Corriente Fase A | LSB = 0.01 A (Unsigned) |
| `0x0004` | Corriente Fase B | LSB = 0.01 A (Unsigned) |
| `0x0005` | Corriente Fase C | LSB = 0.01 A (Unsigned) |
| `0x0006` | Frecuencia Voltaje Fase A | LSB = 0.01 Hz |
| `0x0007` | Frecuencia Voltaje Fase B | LSB = 0.01 Hz |
| `0x0008` | Frecuencia Voltaje Fase C | LSB = 0.01 Hz |
| `0x0009` | Ángulo de Fase Voltaje B | LSB = 0.01° (Relativo a Fase A de Voltaje) |
| `0x000A` | Ángulo de Fase Voltaje C | LSB = 0.01° (Relativo a Fase A de Voltaje) |
| `0x000B` | Ángulo de Fase Corriente A | LSB = 0.01° (Relativo a Fase A de Voltaje) |
| `0x000C` | Ángulo de Fase Corriente B | LSB = 0.01° (Relativo a Fase A de Voltaje) |
| `0x000D` | Ángulo de Fase Corriente C | LSB = 0.01° (Relativo a Fase A de Voltaje) |
| `0x000E` - `0x000F` | Potencia Activa Fase A (32-bit: Low 16 / High 16) | LSB = 0.1 W (Signed) |
| `0x0010` - `0x0011` | Potencia Activa Fase B (32-bit: Low 16 / High 16) | LSB = 0.1 W (Signed) |
| `0x0012` - `0x0013` | Potencia Activa Fase C (32-bit: Low 16 / High 16) | LSB = 0.1 W (Signed) |
| `0x0014` - `0x0015` | Potencia Reactiva Fase A (32-bit: Low 16 / High 16) | LSB = 0.1 Var (Signed) |
| `0x0016` - `0x0017` | Potencia Reactiva Fase B (32-bit: Low 16 / High 16) | LSB = 0.1 Var (Signed) |
| `0x0018` - `0x0019` | Potencia Reactiva Fase C (32-bit: Low 16 / High 16) | LSB = 0.1 Var (Signed) |
| `0x001A` - `0x001B` | Potencia Aparente Fase A (32-bit: Low 16 / High 16) | LSB = 0.1 VA (Signed) |
| `0x001C` - `0x001D` | Potencia Aparente Fase B (32-bit: Low 16 / High 16) | LSB = 0.1 VA (Signed) |
| `0x001E` - `0x001F` | Potencia Aparente Fase C (32-bit: Low 16 / High 16) | LSB = 0.1 VA (Signed) |
| `0x0020` - `0x0021` | Potencia Activa Total / Combinada (32-bit: Low 16 / High 16) | LSB = 0.1 W (Signed) |
| `0x0022` - `0x0023` | Potencia Reactiva Total / Combinada (32-bit: Low 16 / High 16) | LSB = 0.1 Var (Signed) |
| `0x0024` - `0x0025` | Potencia Aparente Total / Combinada (32-bit: Low 16 / High 16) | LSB = 0.1 VA (Signed) |
| `0x0026` | Factor de Potencia Fase A y Fase B | LSB = 0.01 (High Byte = Fase A, Low Byte = Fase B) |
| `0x0027` | Factor de Potencia Fase C y Combinado | LSB = 0.01 (High Byte = Fase C, Low Byte = Combinado) |
| `0x0028` - `0x0029` | Energía Activa Fase A (32-bit) | LSB = 0.1 kWh |
| `0x002A` - `0x002B` | Energía Activa Fase B (32-bit) | LSB = 0.1 kWh |
| `0x002C` - `0x002D` | Energía Activa Fase C (32-bit) | LSB = 0.1 kWh |
| `0x002E` - `0x002F` | Energía Reactiva Fase A (32-bit) | LSB = 0.1 kVar |
| `0x0030` - `0x0031` | Energía Reactiva Fase B (32-bit) | LSB = 0.1 kVar |
| `0x0032` - `0x0033` | Energía Reactiva Fase C (32-bit) | LSB = 0.1 kVar |
| `0x0034` - `0x0035` | Energía Aparente Fase A (32-bit) | LSB = 0.1 kVA |
| `0x0036` - `0x0037` | Energía Aparente Fase B (32-bit) | LSB = 0.1 kVA |
| `0x0038` - `0x0039` | Energía Aparente Fase C (32-bit) | LSB = 0.1 kVA |
| `0x003A` - `0x003B` | Energía Activa Total / Combinada (32-bit) | LSB = 0.1 kWh |
| `0x003C` - `0x003D` | Energía Reactiva Total / Combinada (32-bit) | LSB = 0.1 kVar |
| `0x003E` - `0x003F` | Energía Aparente Total / Combinada (32-bit) | LSB = 0.1 kVA |

---

## 5. Modificación de Parámetros del Esclavo (Función 0x10)

* Lectura de parámetros de configuración: Código `0x03` (Read Holding Registers).
* Modificación de parámetros de configuración: Código `0x10` (Write Multiple Registers).

### Estructura de la Trama de Escritura (Maestro)
`[Dirección Esclavo] + [0x10] + [Reg. Alto] + [Reg. Bajo] + [Cant. Reg. Alto] + [Cant. Reg. Bajo] + [N Bytes] + [Datos N Bytes...] + [CRC Alto] + [CRC Bajo]`

### Respuestas del Esclavo
* **Respuesta Correcta:**  
  `[Dirección Esclavo] + [0x10] + [Reg. Alto] + [Reg. Bajo] + [Cant. Reg. Alto] + [Cant. Reg. Bajo] + [CRC Alto] + [CRC Bajo]`
* **Respuesta de Error:**  
  `[Dirección Esclavo] + [0x90] + [Código de Excepción] + [CRC Alto] + [CRC Bajo]`

### Ejemplo Práctico
Para escribir 3 registros comenzando en `0x0000`:
* **Comando Maestro:** `[0x01] [0x10] [0x00] [0x00] [0x00] [0x03] [0x06] [Data 6 Bytes...] [CRC High] [CRC Low]`
* **Respuesta Esclavo:** `[0x01] [0x10] [0x00] [0x00] [0x00] [0x03] [CRC High] [CRC Low]`

---

## 6. Comando de Reinicio de Energía / Reset Energy (Función 0x42)

Comando propietario para poner a cero los contadores de consumo acumulados. Trama de longitud fija de 6 bytes.

### Estructura de la Trama de Reinicio (Maestro)
`[Dirección Esclavo] + [0x42] + [0x00] + [Secuencia de Fase] + [CRC Alto] + [CRC Bajo]`

### Codificación del Campo "Secuencia de Fase"
* `0x00`: Reiniciar Energía de Fase A.
* `0x01`: Reiniciar Energía de Fase B.
* `0x02`: Reiniciar Energía de Fase C.
* `0x03`: Reiniciar Energía de Fase Combinada / Total.
* `0x0F`: Reiniciar Toda la Energía (Reset total de todos los contadores).

### Respuestas del Esclavo
* **Respuesta Correcta (Echo/Acuse de recibo):** Réplica exacta de la trama recibida.  
  `[Dirección Esclavo] + [0x42] + [0x00] + [Secuencia de Fase] + [CRC Alto] + [CRC Bajo]`
* **Respuesta de Error:**  
  `[Dirección Esclavo] + [0xC2] + [Código de Excepción] + [CRC Alto] + [CRC Bajo]`

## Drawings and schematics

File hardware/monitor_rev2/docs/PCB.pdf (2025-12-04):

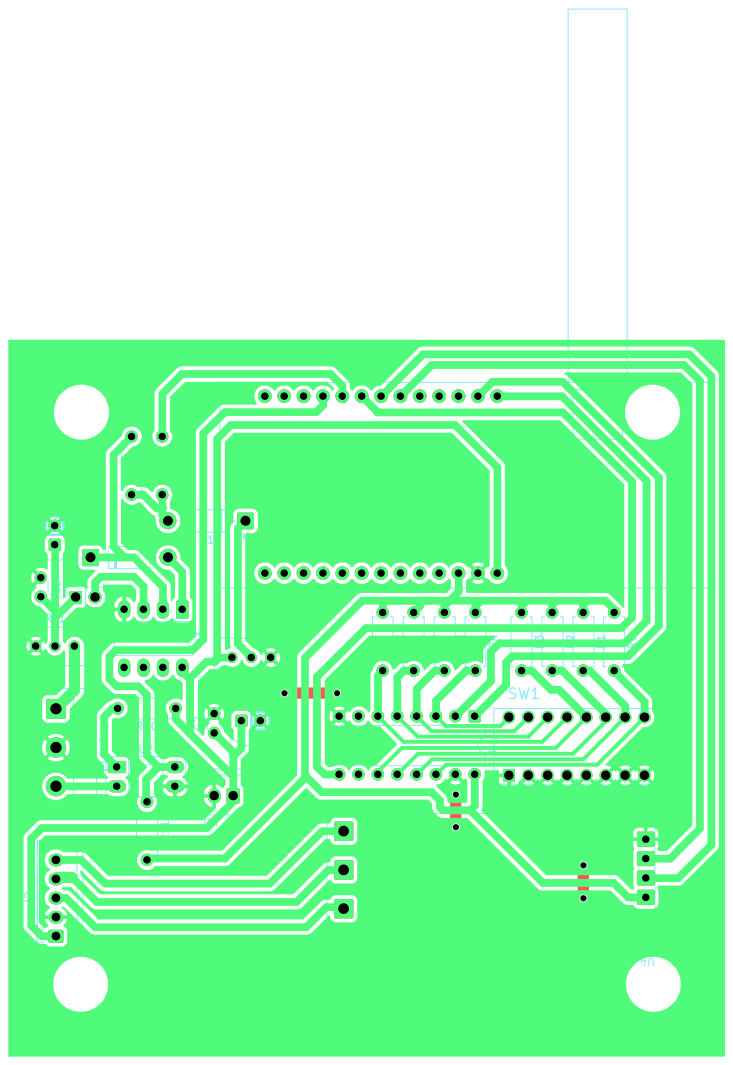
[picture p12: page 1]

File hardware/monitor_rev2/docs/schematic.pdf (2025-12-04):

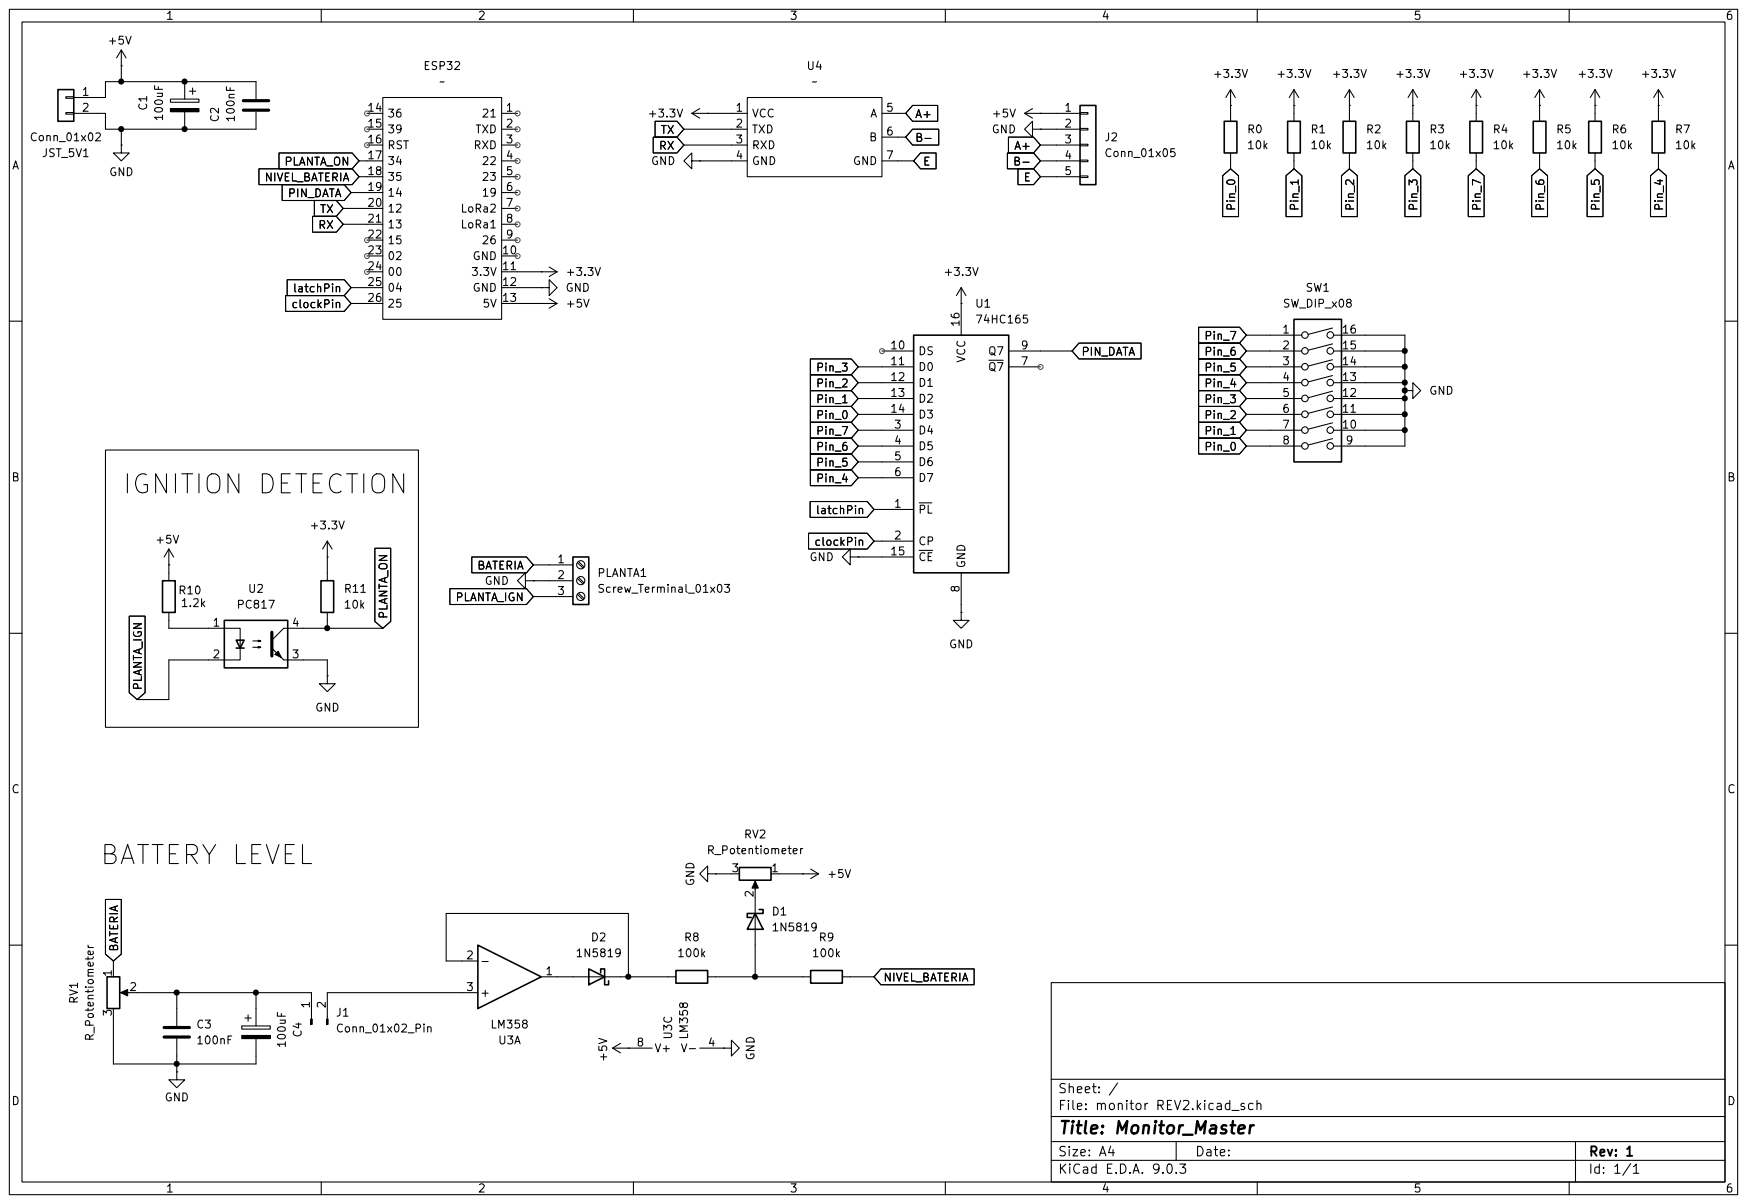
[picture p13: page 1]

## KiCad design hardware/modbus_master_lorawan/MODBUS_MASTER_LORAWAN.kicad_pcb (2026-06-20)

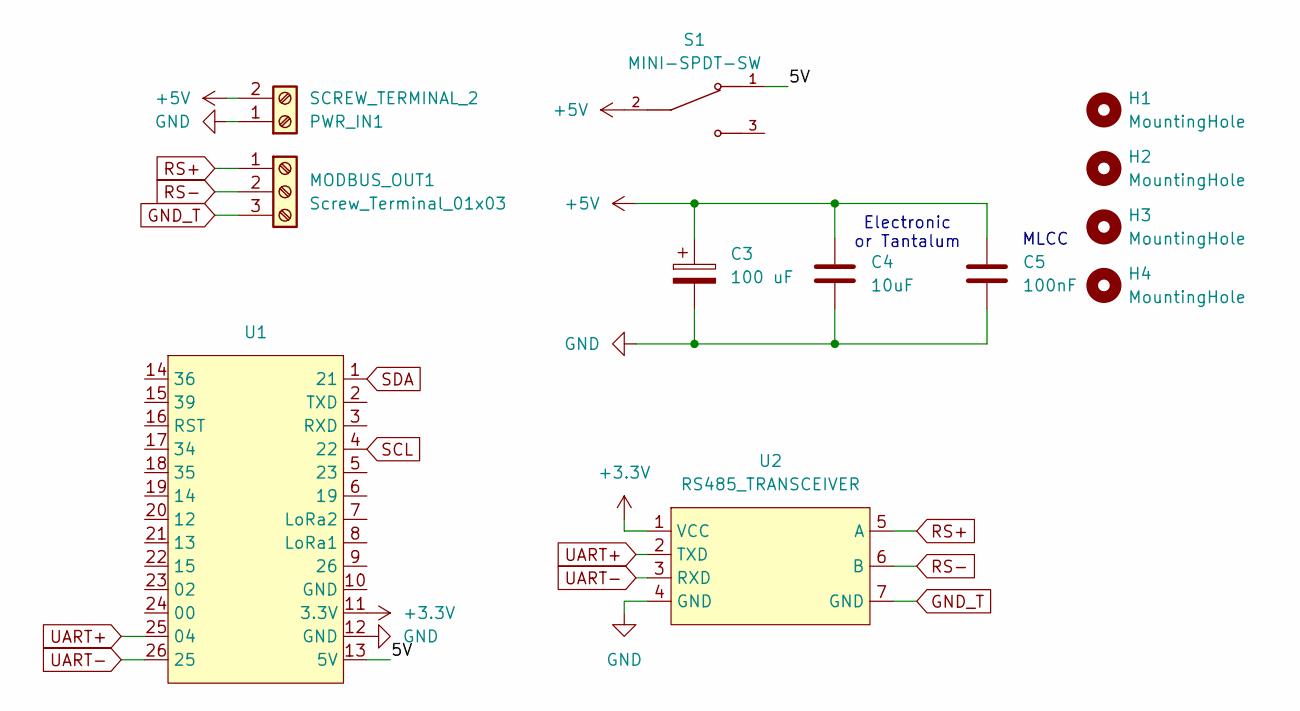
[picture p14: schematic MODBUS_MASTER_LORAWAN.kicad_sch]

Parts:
C3: 100 uF; CP_Radial_D8.0mm_P5.00mm
C4: 10uF; C_Disc_D7.5mm_W5.0mm_P5.00mm
C5: 100nF; C_Disc_D5.0mm_W2.5mm_P2.50mm
H1, H2, H3, H4: MountingHole; MountingHole_3.2mm_M3
MODBUS_OUT1: Screw_Terminal_01x03; TerminalBlock_Phoenix_MKDS-1,5-3-5.08_1x03_P5.08mm_Horizont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
PWR_IN1: SCREW_TERMINAL_2; TerminalBlock_Phoenix_MKDS-1,5-2-5.08_1x02_P5.08mm_Horizont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
S1: MINI-SPDT-SW; SW_MINI-SPDT-SW
U1: ttgo_lora32
U2: RS485_TRANSCEIVER; XY-017

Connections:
+3.3V: U1.11 (3.3V), U2.1 (VCC)
+5V: C3.1, C4.1, C5.1, PWR_IN1.2, S1.2
/5V: S1.1, U1.13 (5V)
GND: C3.2, C4.2, C5.2, PWR_IN1.1, U1.12 (GND), U2.4 (GND)
GND_T: MODBUS_OUT1.3, U2.7 (GND)
RS+: MODBUS_OUT1.1, U2.5 (A)
RS-: MODBUS_OUT1.2, U2.6 (B)
SCL: U1.4 (22)
SDA: U1.1 (21)
UART+: U1.25 (04), U2.2 (TXD)
UART-: U1.26 (25), U2.3 (RXD)

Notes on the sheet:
Electronic or Tantalum
MLCC

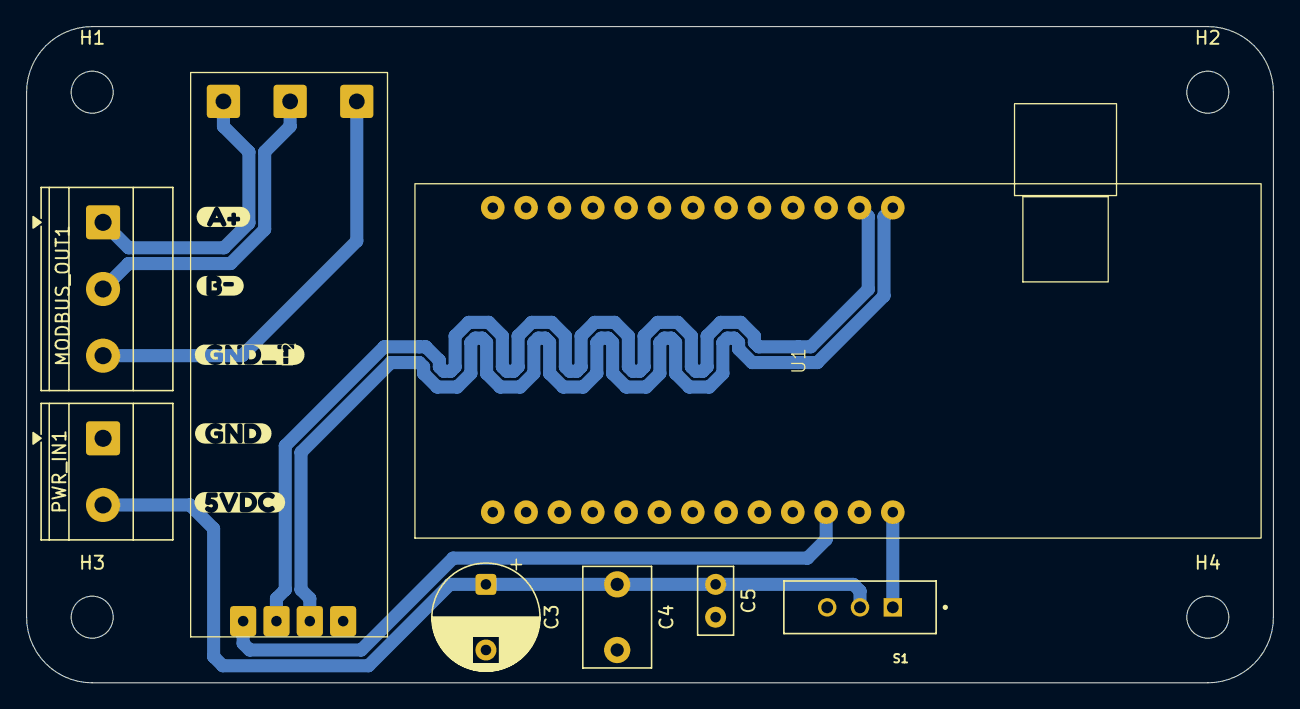
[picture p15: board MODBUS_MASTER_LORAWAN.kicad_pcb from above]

Board: 2 copper layers, 95.0 x 50.0 mm, 17 parts (0 on the bottom side), 9 nets.

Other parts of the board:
kibuzzard-6A3408A8: G***; kibuzzard-6A3408A8
kibuzzard-6A3408B7: G***; kibuzzard-6A3408B7
kibuzzard-6A34085A: G***; kibuzzard-6A34085A
kibuzzard-6A34088C: G***; kibuzzard-6A34088C
kibuzzard-6A340877: G***; kibuzzard-6A340877

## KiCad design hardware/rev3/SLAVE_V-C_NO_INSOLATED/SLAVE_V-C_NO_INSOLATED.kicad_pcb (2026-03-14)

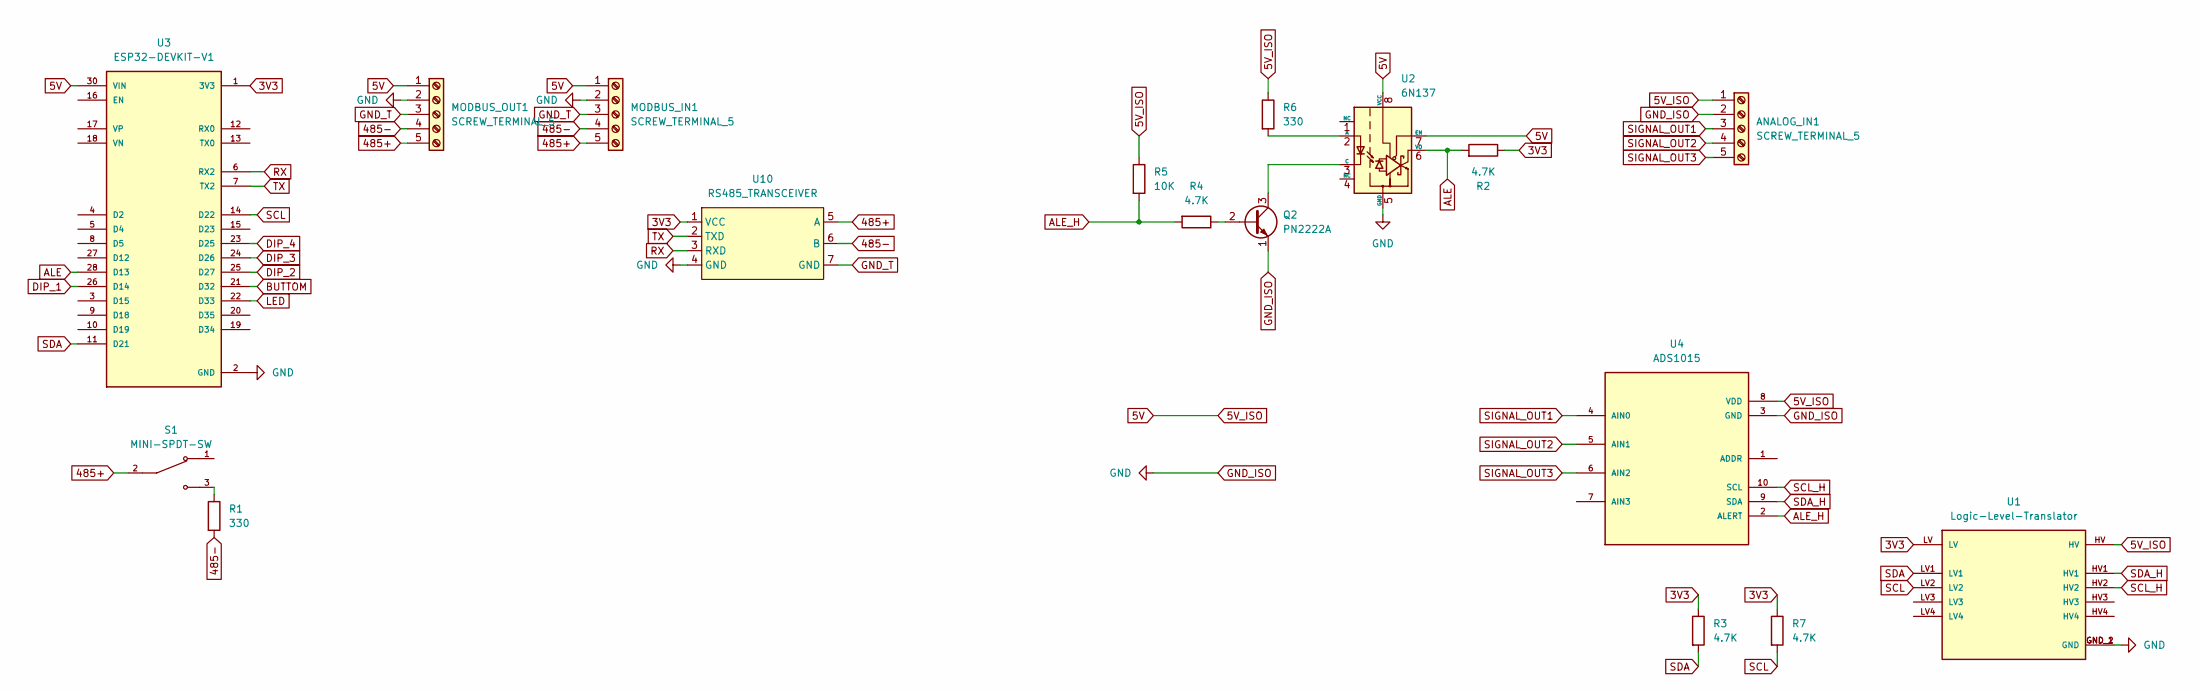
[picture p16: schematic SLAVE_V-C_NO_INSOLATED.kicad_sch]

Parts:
ANALOG_IN1: SCREW_TERMINAL_5; TerminalBlock_Phoenix_MKDS-1,5-5-5.08_1x05_P5.08mm_Horizont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
MODBUS_IN1: SCREW_TERMINAL_5; TerminalBlock_Phoenix_MKDS-1,5-5-5.08_1x05_P5.08mm_Horizont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
MODBUS_OUT1: SCREW_TERMINAL_5; TerminalBlock_Phoenix_MKDS-1,5-5-5.08_1x05_P5.08mm_Horizont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
Q2: PN2222A; TO-92_Inline
R1, R6: 330; R_Axial_DIN0207_L6.3mm_D2.5mm_P7.62mm_Horizontal
R2, R3, R4, R7: 4.7K; R_Axial_DIN0207_L6.3mm_D2.5mm_P7.62mm_Horizontal
R5: 10K; R_Axial_DIN0207_L6.3mm_D2.5mm_P7.62mm_Horizontal
S1: MINI-SPDT-SW; SW_MINI-SPDT-SW
U1: Logic-Level-Translator; CONV_BOB-12009
U2: 6N137; DIP-8_W7.62mm
U3: ESP32-DEVKIT-V1; MODULE_ESP32_DEVKIT_V1; PARTREV N/A
U4: ADS1015
U10: RS485_TRANSCEIVER; XY-017

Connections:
3V3: R2.1, R3.1, R7.1, U1.LV, U3.1 (3V3), U10.1 (VCC)
5V: ANALOG_IN1.1, MODBUS_IN1.1, MODBUS_OUT1.1, R5.1, R6.1, U1.HV, U2.7 (EN), U2.8 (VCC), U3.30 (VIN), U4.8 (VDD)
485+: MODBUS_IN1.5, MODBUS_OUT1.5, S1.2, U10.5 (A)
485-: MODBUS_IN1.4, MODBUS_OUT1.4, R1.2, U10.6 (B)
ALE: R2.2, U2.6 (VO), U3.28 (D13)
ALE_H: R4.2, R5.2, U4.2 (ALERT)
BUTTOM: U3.21 (D32)
DIP_1: U3.26 (D14)
DIP_2: U3.25 (D27)
DIP_3: U3.24 (D26)
DIP_4: U3.23 (D25)
GND_ISO: ANALOG_IN1.2, MODBUS_IN1.2, MODBUS_OUT1.2, Q2.1 (E), U1.GND_1 (GND), U1.GND_2 (GND), U2.5 (GND), U3.2 (GND), U3.29 (GND), U4.3 (GND), U10.4 (GND)
GND_T: MODBUS_IN1.3, MODBUS_OUT1.3, U10.7 (GND)
LED: U3.22 (D33)
unnamed: Q2.2 (B), R4.1
unnamed: Q2.3 (C), U2.3 (C)
unnamed: R1.1, S1.3
unnamed: R6.2, U2.2 (A)
RX: U3.6 (RX2), U10.3 (RXD)
SCL: R7.2, U1.LV2, U3.14 (D22)
SCL_H: U1.HV2, U4.10 (SCL)
SDA: R3.2, U1.LV1, U3.11 (D21)
SDA_H: U1.HV1, U4.9 (SDA)
SIGNAL_OUT1: ANALOG_IN1.3, U4.4 (AIN0)
SIGNAL_OUT2: ANALOG_IN1.4, U4.5 (AIN1)
SIGNAL_OUT3: ANALOG_IN1.5, U4.6 (AIN2)
TX: U3.7 (TX2), U10.2 (TXD)

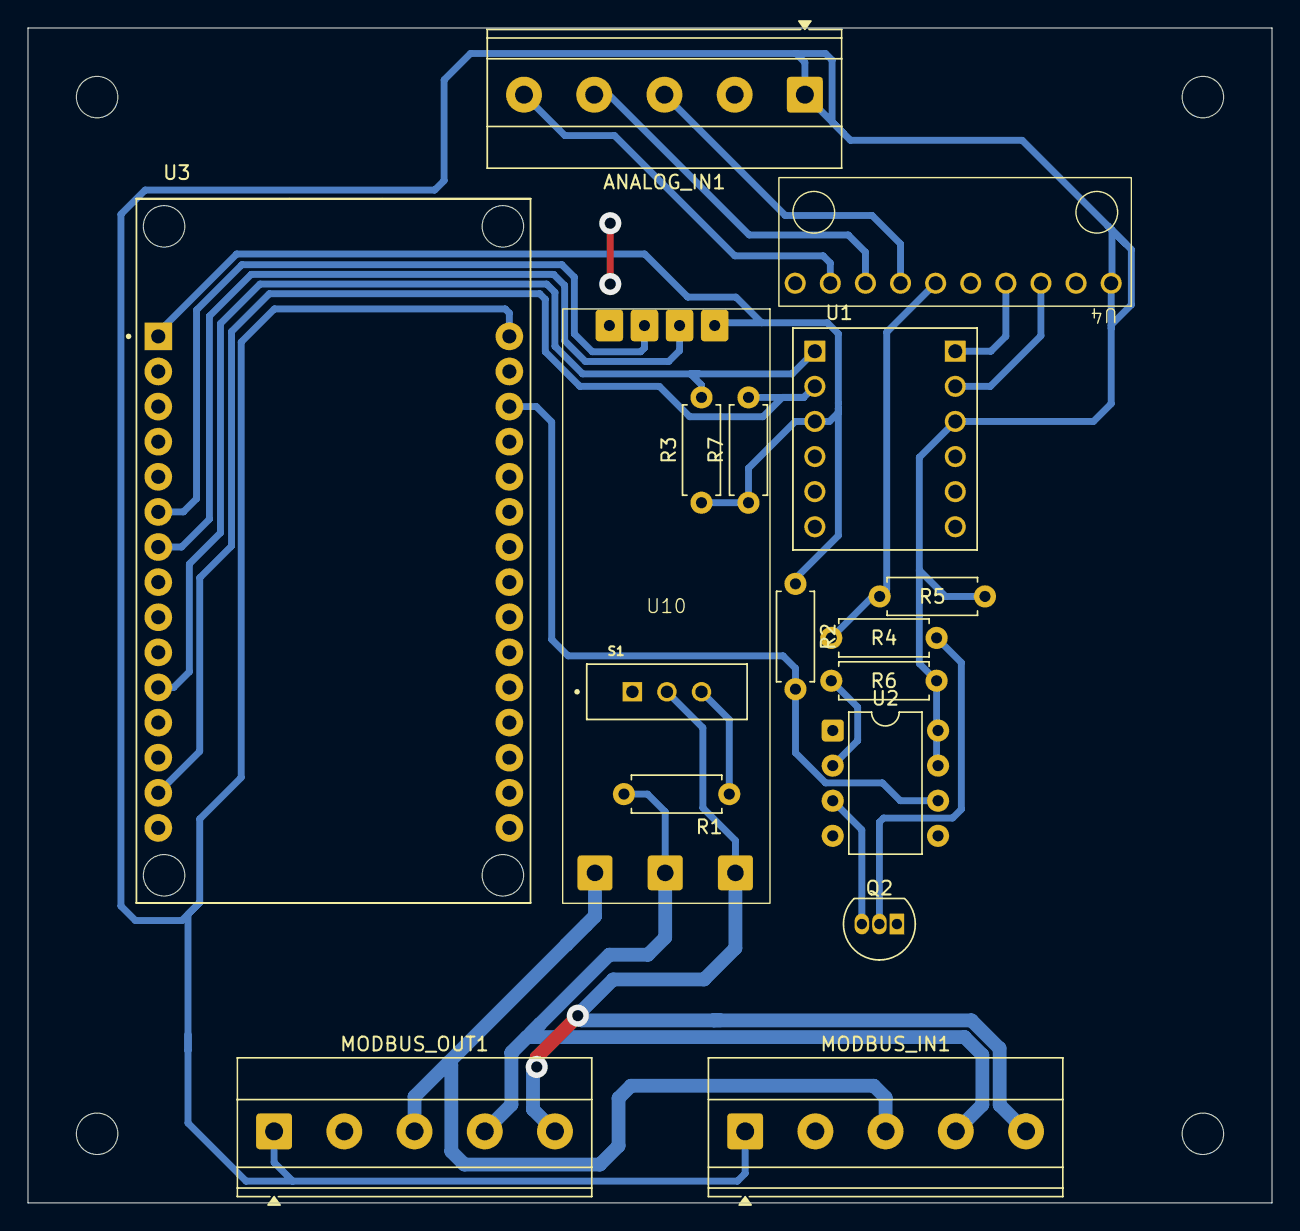
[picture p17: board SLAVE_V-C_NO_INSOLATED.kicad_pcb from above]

Board: 2 copper layers, 90.0 x 85.0 mm, 17 parts (0 on the bottom side), 21 nets.

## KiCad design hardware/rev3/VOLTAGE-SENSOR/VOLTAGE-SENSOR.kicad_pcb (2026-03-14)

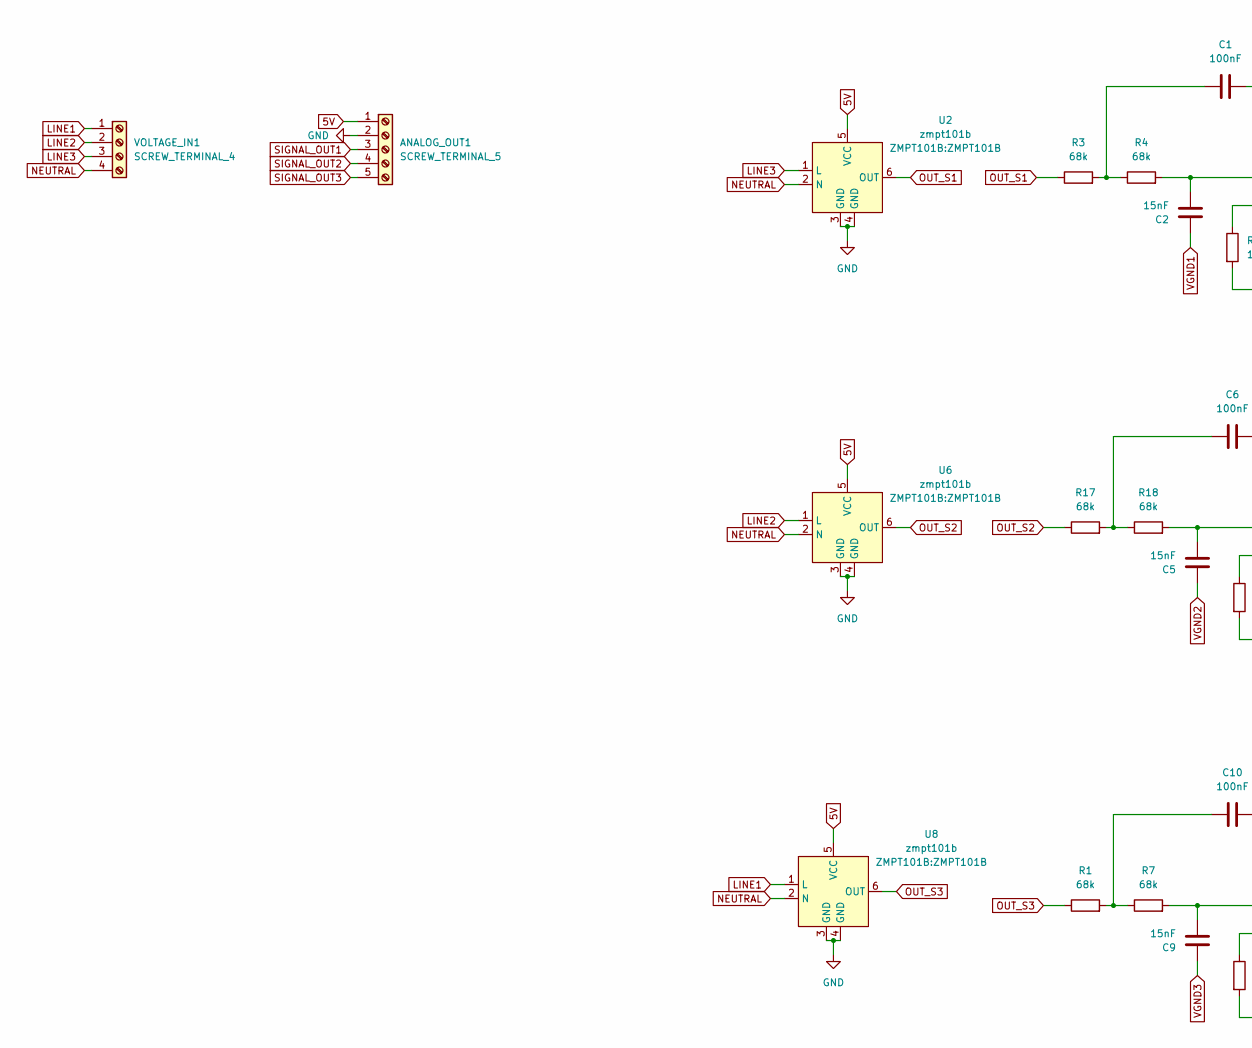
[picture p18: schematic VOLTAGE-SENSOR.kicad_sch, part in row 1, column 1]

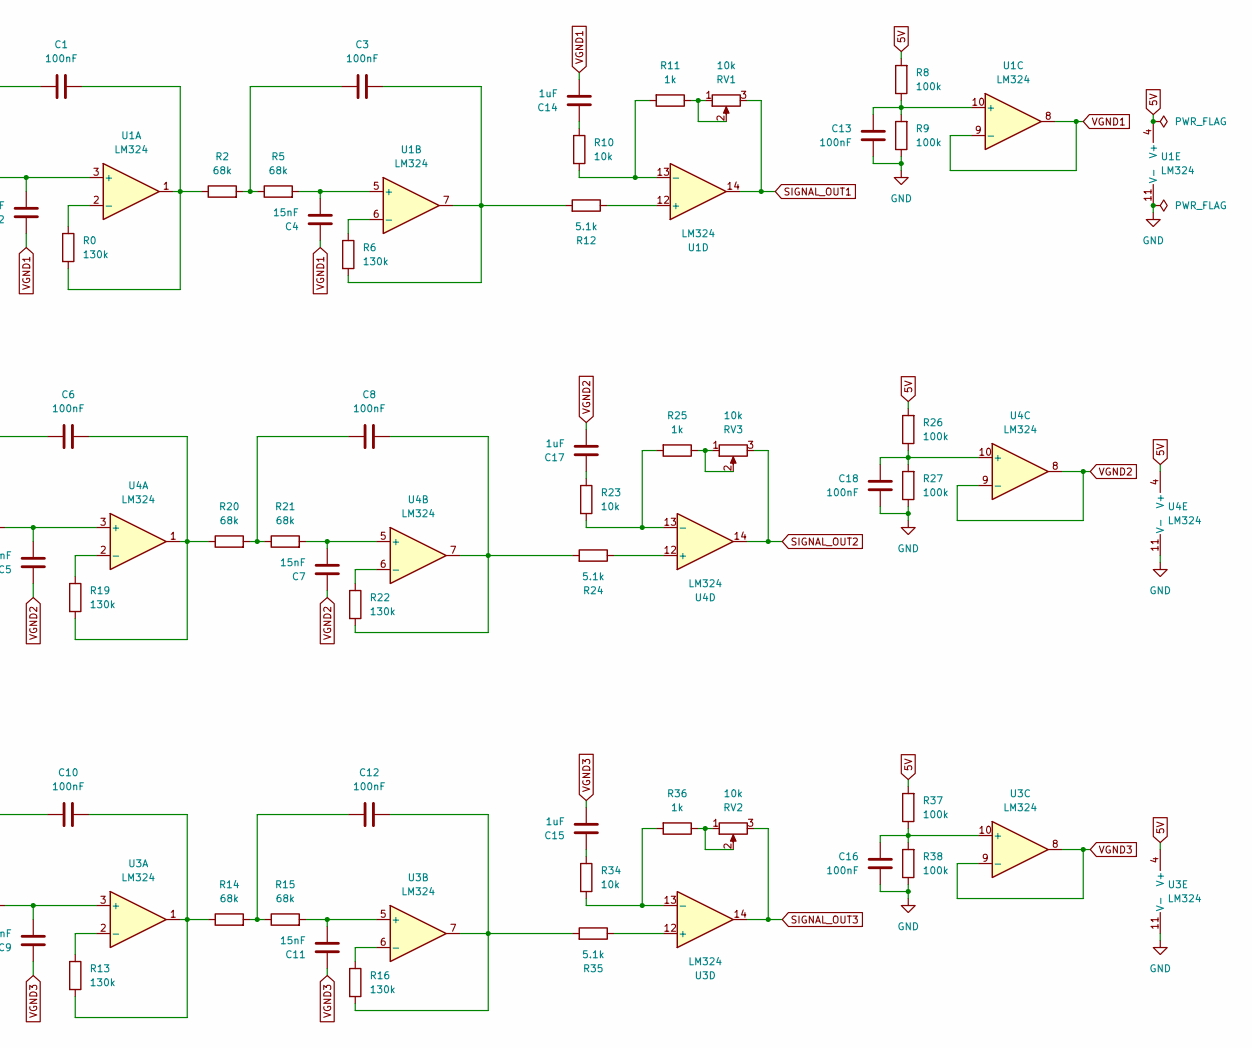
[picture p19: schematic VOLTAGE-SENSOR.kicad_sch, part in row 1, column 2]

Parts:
ANALOG_OUT1: SCREW_TERMINAL_5; TerminalBlock_Phoenix_MKDS-1,5-5-5.08_1x05_P5.08mm_Horizont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
C1, C3, C6, C8, C10, C12, C13, C16, C18: 100nF; C_Rect_L11.0mm_W4.3mm_P10.00mm_MKT
C2, C4, C5, C7, C9, C11: 15nF; C_Rect_L7.0mm_W2.5mm_P5.00mm
C14, C15, C17: 1uF; C_Rect_L7.0mm_W2.5mm_P5.00mm
R0, R6, R13, R16, R19, R22: 130k; R_Axial_DIN0207_L6.3mm_D2.5mm_P7.62mm_Horizontal
R1, R2, R3, R4, R5, R7, R14, R15, R17, R18, R20, R21: 68k; R_Axial_DIN0207_L6.3mm_D2.5mm_P7.62mm_Horizontal
R8, R9, R26, R27, R37, R38: 100k; R_Axial_DIN0207_L6.3mm_D2.5mm_P7.62mm_Horizontal
R10, R23, R34: 10k; R_Axial_DIN0207_L6.3mm_D2.5mm_P7.62mm_Horizontal
R11, R25, R36: 1k; R_Axial_DIN0207_L6.3mm_D2.5mm_P7.62mm_Horizontal
R12, R24, R35: 5.1k; R_Axial_DIN0207_L6.3mm_D2.5mm_P7.62mm_Horizontal
RV1, RV2, RV3: 10k; Potentiometer_Bourns_3296W_Vertical
U1, U3, U4: LM324; DIP-14_W7.62mm_LongPads
U2, U6, U8: zmpt101b; ZMPT101B
VOLTAGE_IN1: SCREW_TERMINAL_4; TerminalBlock_Phoenix_MKDS-1,5-4-5.08_1x04_P5.08mm_Horizont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

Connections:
5V: ANALOG_OUT1.1, R8.2, R26.2, R37.2, U1.4 (V+), U2.5 (VCC), U3.4 (V+), U4.4 (V+), U6.5 (VCC), U8.5 (VCC)
GND: ANALOG_OUT1.2, C13.1, C16.1, C18.1, R9.1, R27.1, R38.1, U1.11 (V-), U2.3 (GND), U2.4 (GND), U3.11 (V-), U4.11 (V-), U6.3 (GND), U6.4 (GND), U8.3 (GND), U8.4 (GND)
LINE1: U8.1 (L), VOLTAGE_IN1.1
LINE2: U6.1 (L), VOLTAGE_IN1.2
LINE3: U2.1 (L), VOLTAGE_IN1.3
NEUTRAL: U2.2 (N), U6.2 (N), U8.2 (N), VOLTAGE_IN1.4
unnamed: C1.1, R3.2, R4.1
unnamed: C1.2, R0.2, R2.1, U1.1
unnamed: C3.1, R2.2, R5.1
unnamed: C3.2, R6.2, R12.2, U1.7
unnamed: C6.1, R17.2, R18.1
unnamed: C6.2, R19.2, R20.1, U4.1
unnamed: C8.1, R20.2, R21.1
unnamed: C8.2, R22.2, R24.2, U4.7
unnamed: C10.1, R1.2, R7.1
unnamed: C10.2, R13.2, R14.1, U3.1
unnamed: C12.1, R14.2, R15.1
unnamed: C12.2, R16.2, R35.2, U3.7
unnamed: C14.1, R10.1
unnamed: C15.1, R34.1
unnamed: C17.1, R23.1
unnamed: R11.1, RV1.1, RV1.2
unnamed: R25.1, RV3.1, RV3.2
unnamed: R36.1, RV2.1, RV2.2
unnamed: C2.2, R4.2, U1.3 (+)
unnamed: R0.1, U1.2 (-)
unnamed: C4.2, R5.2, U1.5 (+)
unnamed: R6.1, U1.6 (-)
unnamed: C13.2, R8.1, R9.2, U1.10 (+)
unnamed: R12.1, U1.12 (+)
unnamed: R10.2, R11.2, U1.13 (-)
unnamed: C9.2, R7.2, U3.3 (+)
unnamed: R13.1, U3.2 (-)
unnamed: C11.2, R15.2, U3.5 (+)
unnamed: R16.1, U3.6 (-)
unnamed: C16.2, R37.1, R38.2, U3.10 (+)
unnamed: R35.1, U3.12 (+)
unnamed: R34.2, R36.2, U3.13 (-)
unnamed: C5.2, R18.2, U4.3 (+)
unnamed: R19.1, U4.2 (-)
unnamed: C7.2, R21.2, U4.5 (+)
unnamed: R22.1, U4.6 (-)
unnamed: C18.2, R26.1, R27.2, U4.10 (+)
unnamed: R24.1, U4.12 (+)
unnamed: R23.2, R25.2, U4.13 (-)
OUT_S1: R3.1, U2.6 (OUT)
OUT_S2: R17.1, U6.6 (OUT)
OUT_S3: R1.1, U8.6 (OUT)
SIGNAL_OUT1: ANALOG_OUT1.3, RV1.3, U1.14
SIGNAL_OUT2: ANALOG_OUT1.4, RV3.3, U4.14
SIGNAL_OUT3: ANALOG_OUT1.5, RV2.3, U3.14
VGND1: C2.1, C4.1, C14.2, U1.8, U1.9 (-)
VGND2: C5.1, C7.1, C17.2, U4.8, U4.9 (-)
VGND3: C9.1, C11.1, C15.2, U3.8, U3.9 (-)

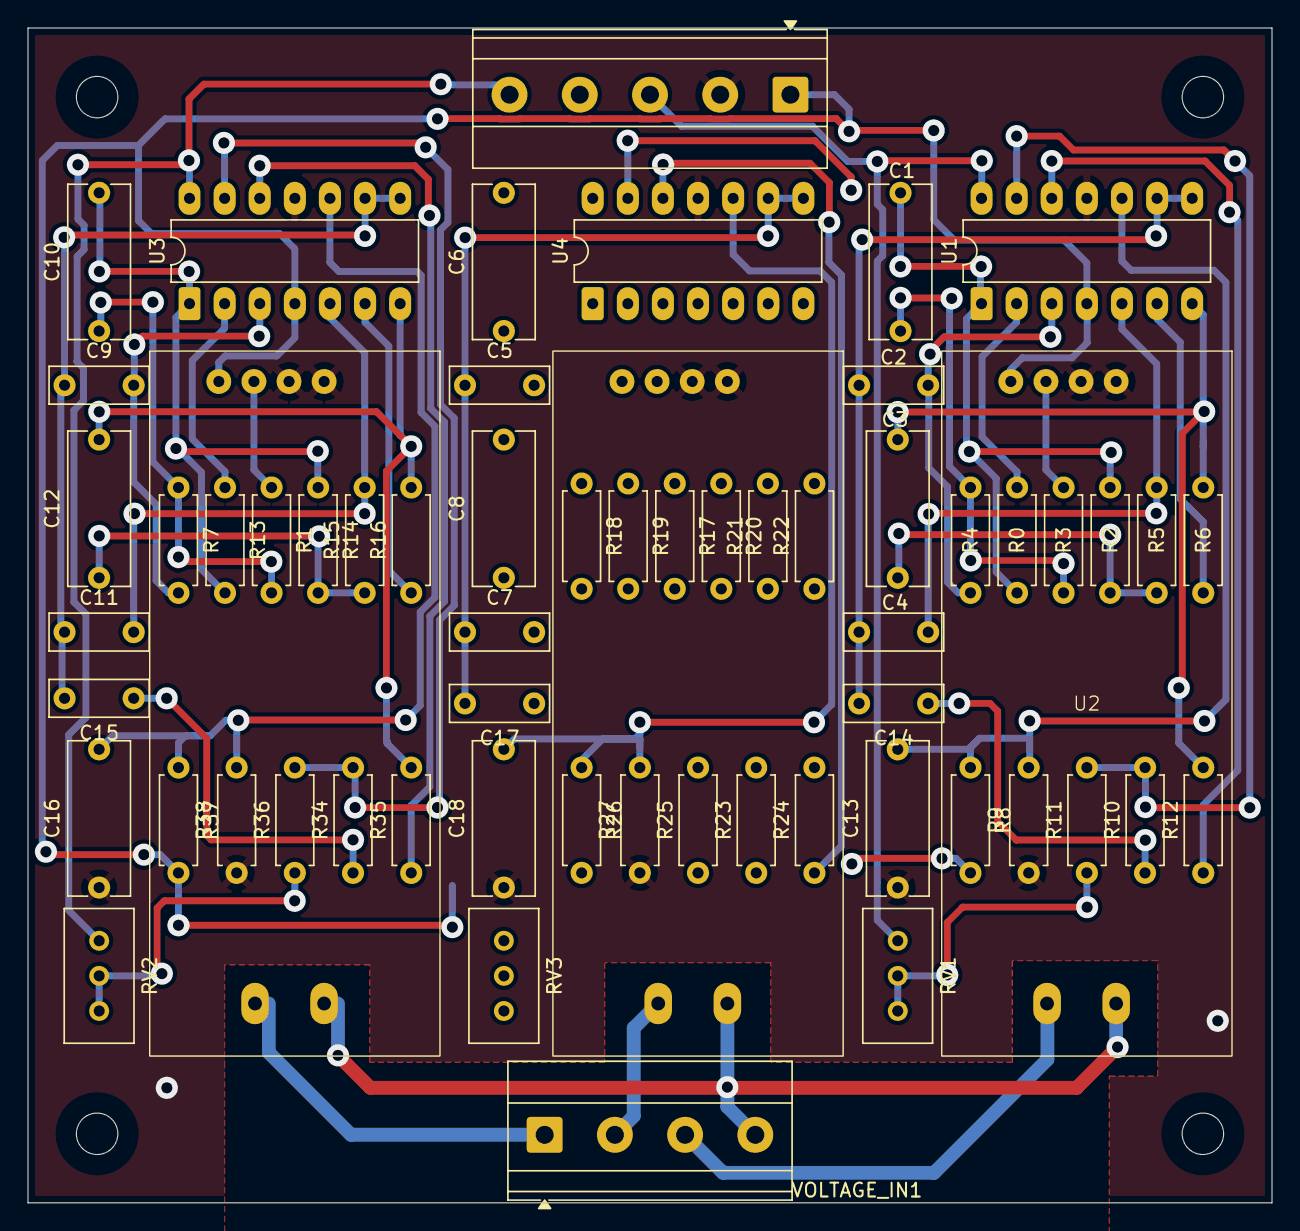
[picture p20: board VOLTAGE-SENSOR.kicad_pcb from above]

Board: 2 copper layers, 90.0 x 85.0 mm, 62 parts (0 on the bottom side), 54 nets.

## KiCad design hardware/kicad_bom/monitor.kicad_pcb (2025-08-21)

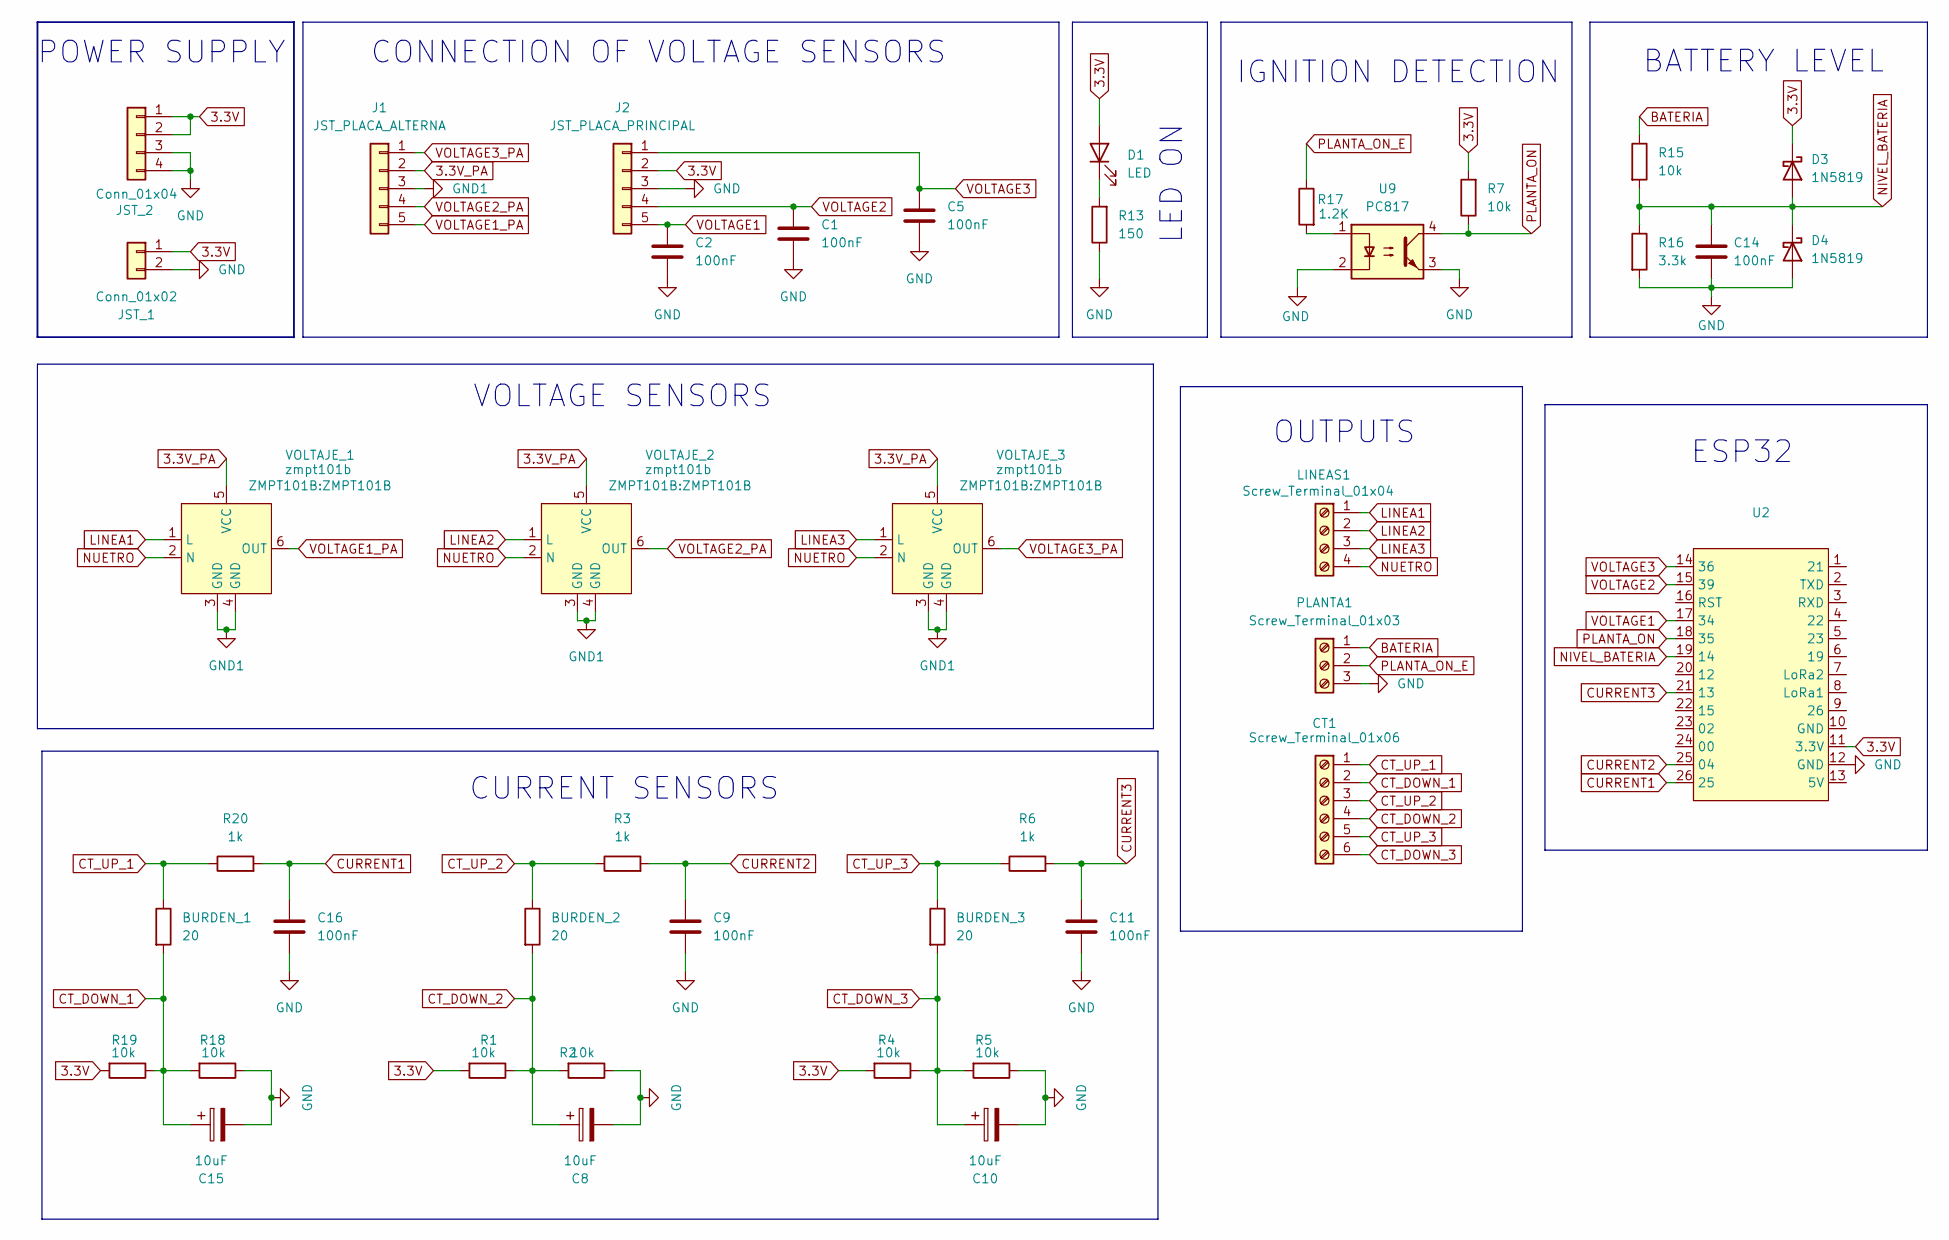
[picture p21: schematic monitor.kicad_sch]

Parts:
BURDEN_1, BURDEN_2, BURDEN_3: 20; R_Axial_DIN0207_L6.3mm_D2.5mm_P7.62mm_Horizontal
C1, C2, C5, C9, C11, C14, C16: 100nF; C_Disc_D3.0mm_W1.6mm_P2.50mm
C8, C10, C15: 10uF; CP_Radial_D5.0mm_P2.00mm
CT1: Screw_Terminal_01x06; TerminalBlock_Phoenix_MKDS-1,5-6-5.08_1x06_P5.08mm_Horizont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
D1: LED; LED_D5.0mm
D3, D4: 1N5819; D_DO-41_SOD81_P10.16mm_Horizontal
J1: JST_PLACA_ALTERNA; JST_XH_B5B-XH-A_1x05_P2.50mm_Vertical
J2: JST_PLACA_PRINCIPAL; JST_XH_B5B-XH-A_1x05_P2.50mm_Vertical
JST_1: Conn_01x02; JST_XH_B2B-XH-A_1x02_P2.50mm_Vertical
JST_2: Conn_01x04; JST_XH_B4B-XH-A_1x04_P2.50mm_Vertical
LINEAS1: Screw_Terminal_01x04; TerminalBlock_Phoenix_MKDS-1,5-4-5.08_1x04_P5.08mm_Horizont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
PLANTA1: Screw_Terminal_01x03; TerminalBlock_Phoenix_MKDS-1,5-3-5.08_1x03_P5.08mm_Horizont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
R1, R2, R4, R5, R7, R15, R18, R19: 10k; R_Axial_DIN0207_L6.3mm_D2.5mm_P7.62mm_Horizontal
R3, R6, R20: 1k; R_Axial_DIN0207_L6.3mm_D2.5mm_P7.62mm_Horizontal
R13: 150; R_Axial_DIN0207_L6.3mm_D2.5mm_P7.62mm_Horizontal
R16: 3.3k; R_Axial_DIN0207_L6.3mm_D2.5mm_P7.62mm_Horizontal
R17: 1.2K; R_Axial_DIN0207_L6.3mm_D2.5mm_P7.62mm_Horizontal
U2: ttgo_lora32
U9: PC817; DIP-4_W7.62mm_Socket_LongPads
VOLTAJE_1, VOLTAJE_2, VOLTAJE_3: zmpt101b; ZMPT101B

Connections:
3.3V: D1.2 (A), D3.1 (K), J2.2, JST_1.1, JST_2.1, JST_2.2, R1.2, R4.2, R7.2, R19.2, U2.11 (3.3V)
3.3V_PA: J1.2, VOLTAJE_1.5 (VCC), VOLTAJE_2.5 (VCC), VOLTAJE_3.5 (VCC)
BATERIA: PLANTA1.1, R15.1
CT_DOWN_1: BURDEN_1.2, C15.1, CT1.2, R18.2, R19.1
CT_DOWN_2: BURDEN_2.2, C8.1, CT1.4, R1.1, R2.2
CT_DOWN_3: BURDEN_3.2, C10.1, CT1.6, R4.1, R5.2
CT_UP_1: BURDEN_1.1, CT1.1, R20.1
CT_UP_2: BURDEN_2.1, CT1.3, R3.1
CT_UP_3: BURDEN_3.1, CT1.5, R6.1
CURRENT1: C16.2, R20.2, U2.26 (25)
CURRENT2: C9.2, R3.2, U2.25 (04)
CURRENT3: C11.2, R6.2, U2.21 (13)
GND: C1.2, C2.2, C5.2, C8.2, C9.1, C10.2, C11.1, C14.1, C15.2, C16.1, D4.2 (A), J2.3, JST_1.2, JST_2.3, JST_2.4, PLANTA1.3, R2.1, R5.1, R13.1, R16.2, R18.1, U2.12 (GND), U9.2, U9.3
GND1: J1.3, VOLTAJE_1.3 (GND), VOLTAJE_1.4 (GND), VOLTAJE_2.3 (GND), VOLTAJE_2.4 (GND), VOLTAJE_3.3 (GND), VOLTAJE_3.4 (GND)
LINEA1: LINEAS1.1, VOLTAJE_1.1 (L)
LINEA2: LINEAS1.2, VOLTAJE_2.1 (L)
LINEA3: LINEAS1.3, VOLTAJE_3.1 (L)
NIVEL_BATERIA: C14.2, D3.2 (A), D4.1 (K), R15.2, R16.1, U2.19 (14)
NUETRO: LINEAS1.4, VOLTAJE_1.2 (N), VOLTAJE_2.2 (N), VOLTAJE_3.2 (N)
unnamed: D1.1 (K), R13.2
unnamed: R17.2, U9.1
PLANTA_ON: R7.1, U2.18 (35), U9.4
PLANTA_ON_E: PLANTA1.2, R17.1
VOLTAGE1: C2.1, J2.5, U2.17 (34)
VOLTAGE1_PA: J1.5, VOLTAJE_1.6 (OUT)
VOLTAGE2: C1.1, J2.4, U2.15 (39)
VOLTAGE2_PA: J1.4, VOLTAJE_2.6 (OUT)
VOLTAGE3: C5.1, J2.1, U2.14 (36)
VOLTAGE3_PA: J1.1, VOLTAJE_3.6 (OUT)

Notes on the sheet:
ESP32
LED ON
CURRENT SENSORS
VOLTAGE SENSORS
IGNITION DETECTION
OUTPUTS
CONNECTION OF VOLTAGE SENSORS
BATTERY LEVEL
POWER SUPPLY

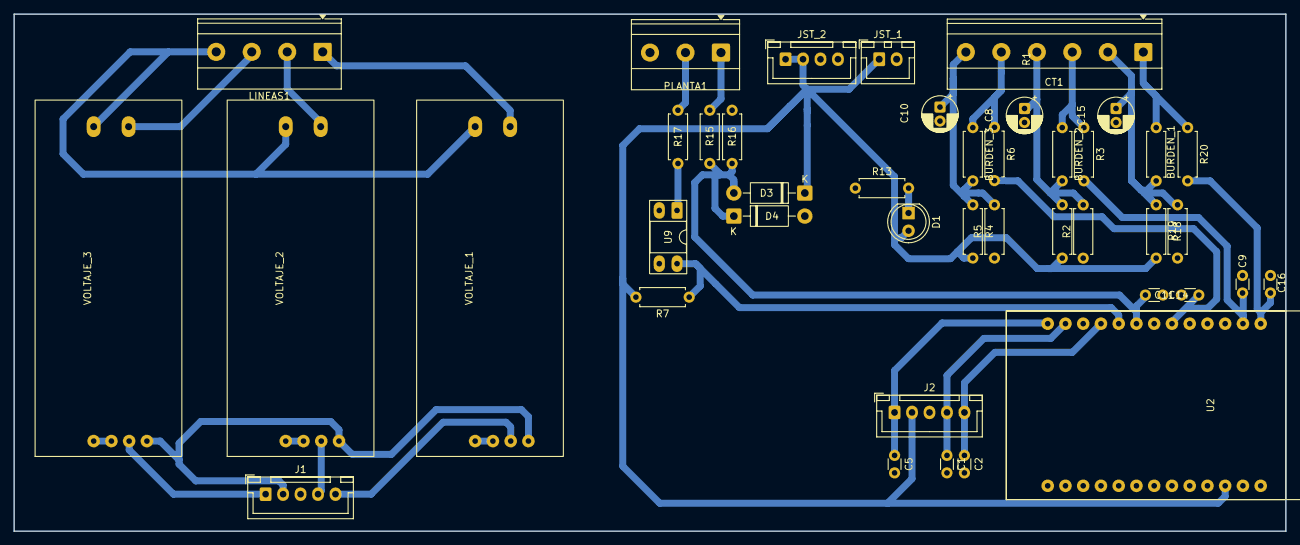
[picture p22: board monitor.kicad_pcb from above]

Board: 2 copper layers, 182.0 x 74.0 mm, 42 parts (0 on the bottom side), 29 nets.

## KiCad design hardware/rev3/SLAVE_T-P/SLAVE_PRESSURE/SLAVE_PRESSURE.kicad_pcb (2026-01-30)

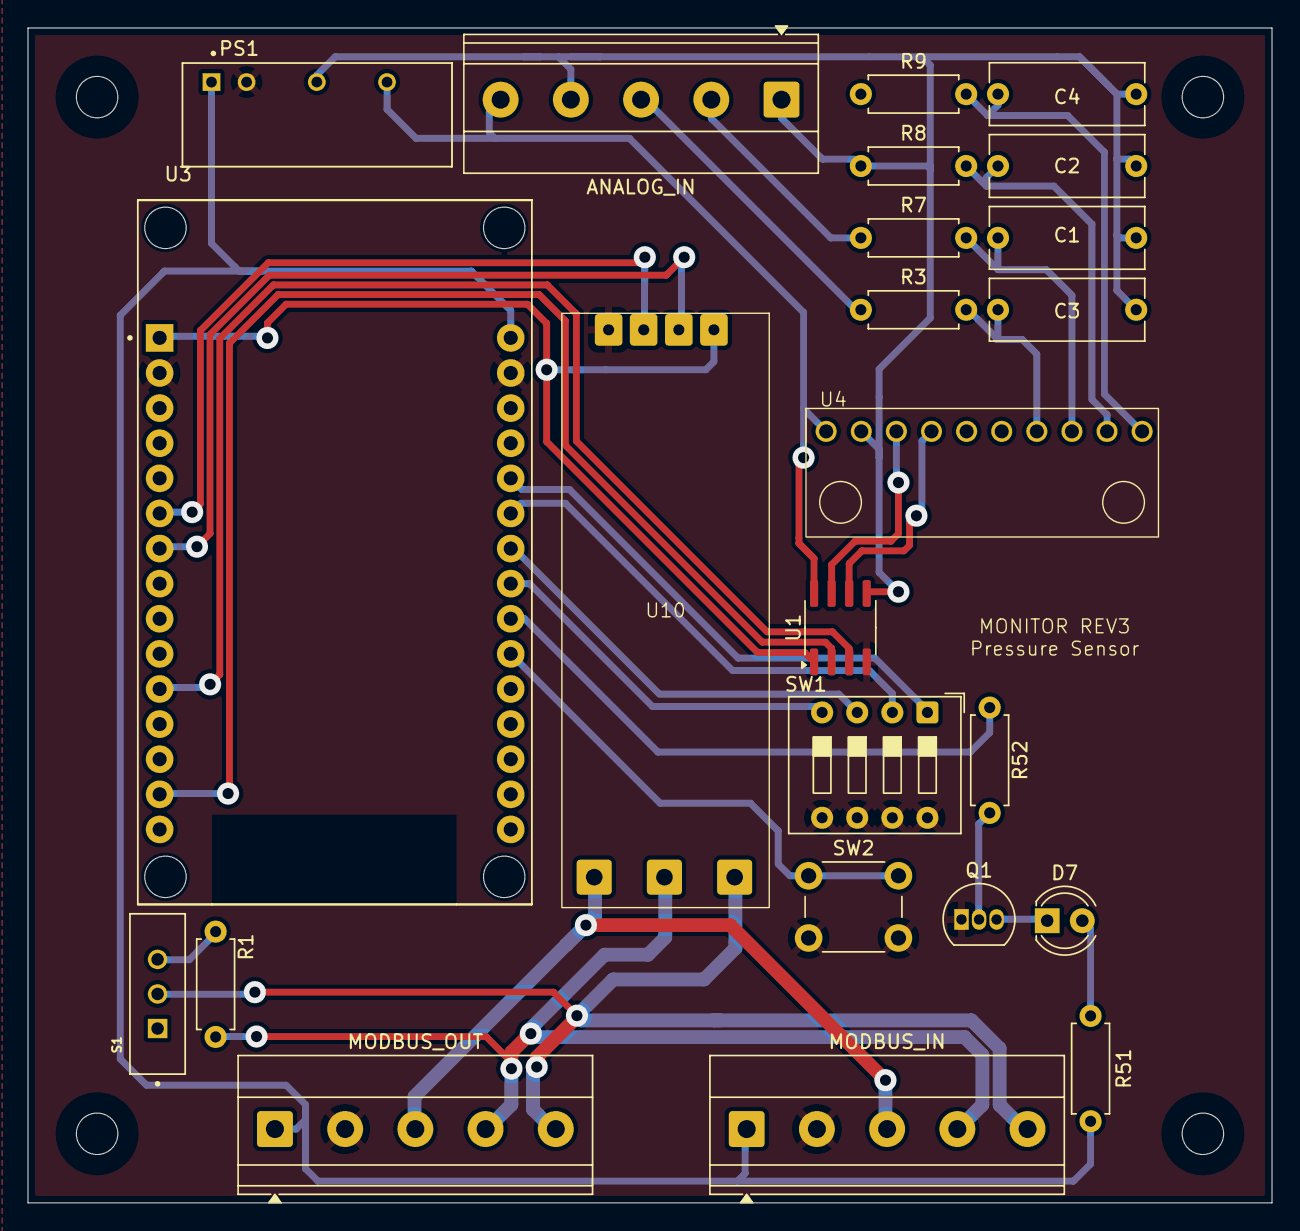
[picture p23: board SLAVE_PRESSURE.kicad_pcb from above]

Board: 2 copper layers, 90.0 x 85.0 mm, 24 parts (0 on the bottom side), 31 nets.

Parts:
ANALOG_IN: SCREW_TERMINAL_5; TerminalBlock_Phoenix_MKDS-1,5-5-5.08_1x05_P5.08mm_Horizont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
C1, C2, C3, C4: 100nF; C_Rect_L11.0mm_W4.3mm_P10.00mm_MKT
D7: LED; LED_D4.0mm
MODBUS_IN: SCREW_TERMINAL_5; TerminalBlock_Phoenix_MKDS-1,5-5-5.08_1x05_P5.08mm_Horizont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
MODBUS_OUT: SCREW_TEMINAL_5; TerminalBlock_Phoenix_MKDS-1,5-5-5.08_1x05_P5.08mm_Horizont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
PS1: TMH_0505S; CONV_TMH_0505S
Q1: PN2222A; TO-92_Inline
R1, R51: 330; R_Axial_DIN0207_L6.3mm_D2.5mm_P7.62mm_Horizontal
R3, R7, R8, R9: 1K; R_Axial_DIN0207_L6.3mm_D2.5mm_P7.62mm_Horizontal
R52: 3.3k; R_Axial_DIN0207_L6.3mm_D2.5mm_P7.62mm_Horizontal
S1: MINI-SPDT-SW; SW_MINI-SPDT-SW
SW1: SW_DIP_x04; SW_DIP_SPSTx04_Slide_9.78x12.34mm_W7.62mm_P2.54mm
SW2: SW_Push; SW_PUSH_6mm
U1: ADuM1201AR; SOIC-8_3.9x4.9mm_P1.27mm
U3: ESP32-DEVKIT-V1; MODULE_ESP32_DEVKIT_V1
U4: ADS1015
U10: RS485_TRANSCEIVER; XY-017

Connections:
3V3: U1.1 (VDD1), U3.1 (3V3), U10.1 (VCC)
5V: MODBUS_IN.1, MODBUS_OUT.1, PS1.1 (+VIN(VCC)), R51.1, U3.30 (VIN)
5V_ISO: ANALOG_IN.5, PS1.6 (+VOUT), U1.8 (VDD2), U4.8 (VDD)
485+: MODBUS_IN.5, MODBUS_OUT.5, S1.2, U10.5 (A)
485-: MODBUS_IN.4, MODBUS_OUT.4, R1.2, U10.6 (B)
BUTTOM: SW2.1, U3.21 (D32)
DIP_1: SW1.1, U3.26 (D14)
DIP_2: SW1.2, U3.25 (D27)
DIP_3: SW1.3, U3.24 (D26)
DIP_4: SW1.4, U3.23 (D25)
GND: MODBUS_IN.2, MODBUS_OUT.2, PS1.2 (-VIN(GND)), Q1.1 (E), SW1.5, SW1.6, SW1.7, SW1.8, SW2.2, U1.4 (GND1), U3.2 (GND), U3.29 (GND), U10.4 (GND)
GND_ISO: ANALOG_IN.4, C1.1, C2.1, C3.1, C4.1, PS1.4 (-VOUT), U1.5 (GND2), U4.3 (GND)
GND_T: MODBUS_IN.3, MODBUS_OUT.3, U10.7 (GND)
LED: R52.2, U3.22 (D33)
unnamed: D7.2 (A), R51.2
unnamed: D7.1 (K), Q1.3 (C)
unnamed: Q1.2 (B), R52.1
unnamed: R1.1, S1.3
RX: U3.6 (RX2), U10.3 (RXD)
SCL: U1.2 (VOA), U3.14 (D22)
SCL_H: U1.7 (VIA), U4.10 (SCL)
SDA: U1.3 (VIB), U3.11 (D21)
SDA_H: U1.6 (VOB), U4.9 (SDA)
SIGNAL_1: ANALOG_IN.3, R3.1
SIGNAL_2: ANALOG_IN.2, R7.1
SIGNAL_3: ANALOG_IN.1, R8.1
SIGNAL_OUT1: C3.2, R3.2, U4.4 (AIN0)
SIGNAL_OUT2: C1.2, R7.2, U4.5 (AIN1)
SIGNAL_OUT3: C2.2, R8.2, U4.6 (AIN2)
SIGNAL_OUT4: C4.2, R9.2, U4.7 (AIN3)
TX: U3.7 (TX2), U10.2 (TXD)

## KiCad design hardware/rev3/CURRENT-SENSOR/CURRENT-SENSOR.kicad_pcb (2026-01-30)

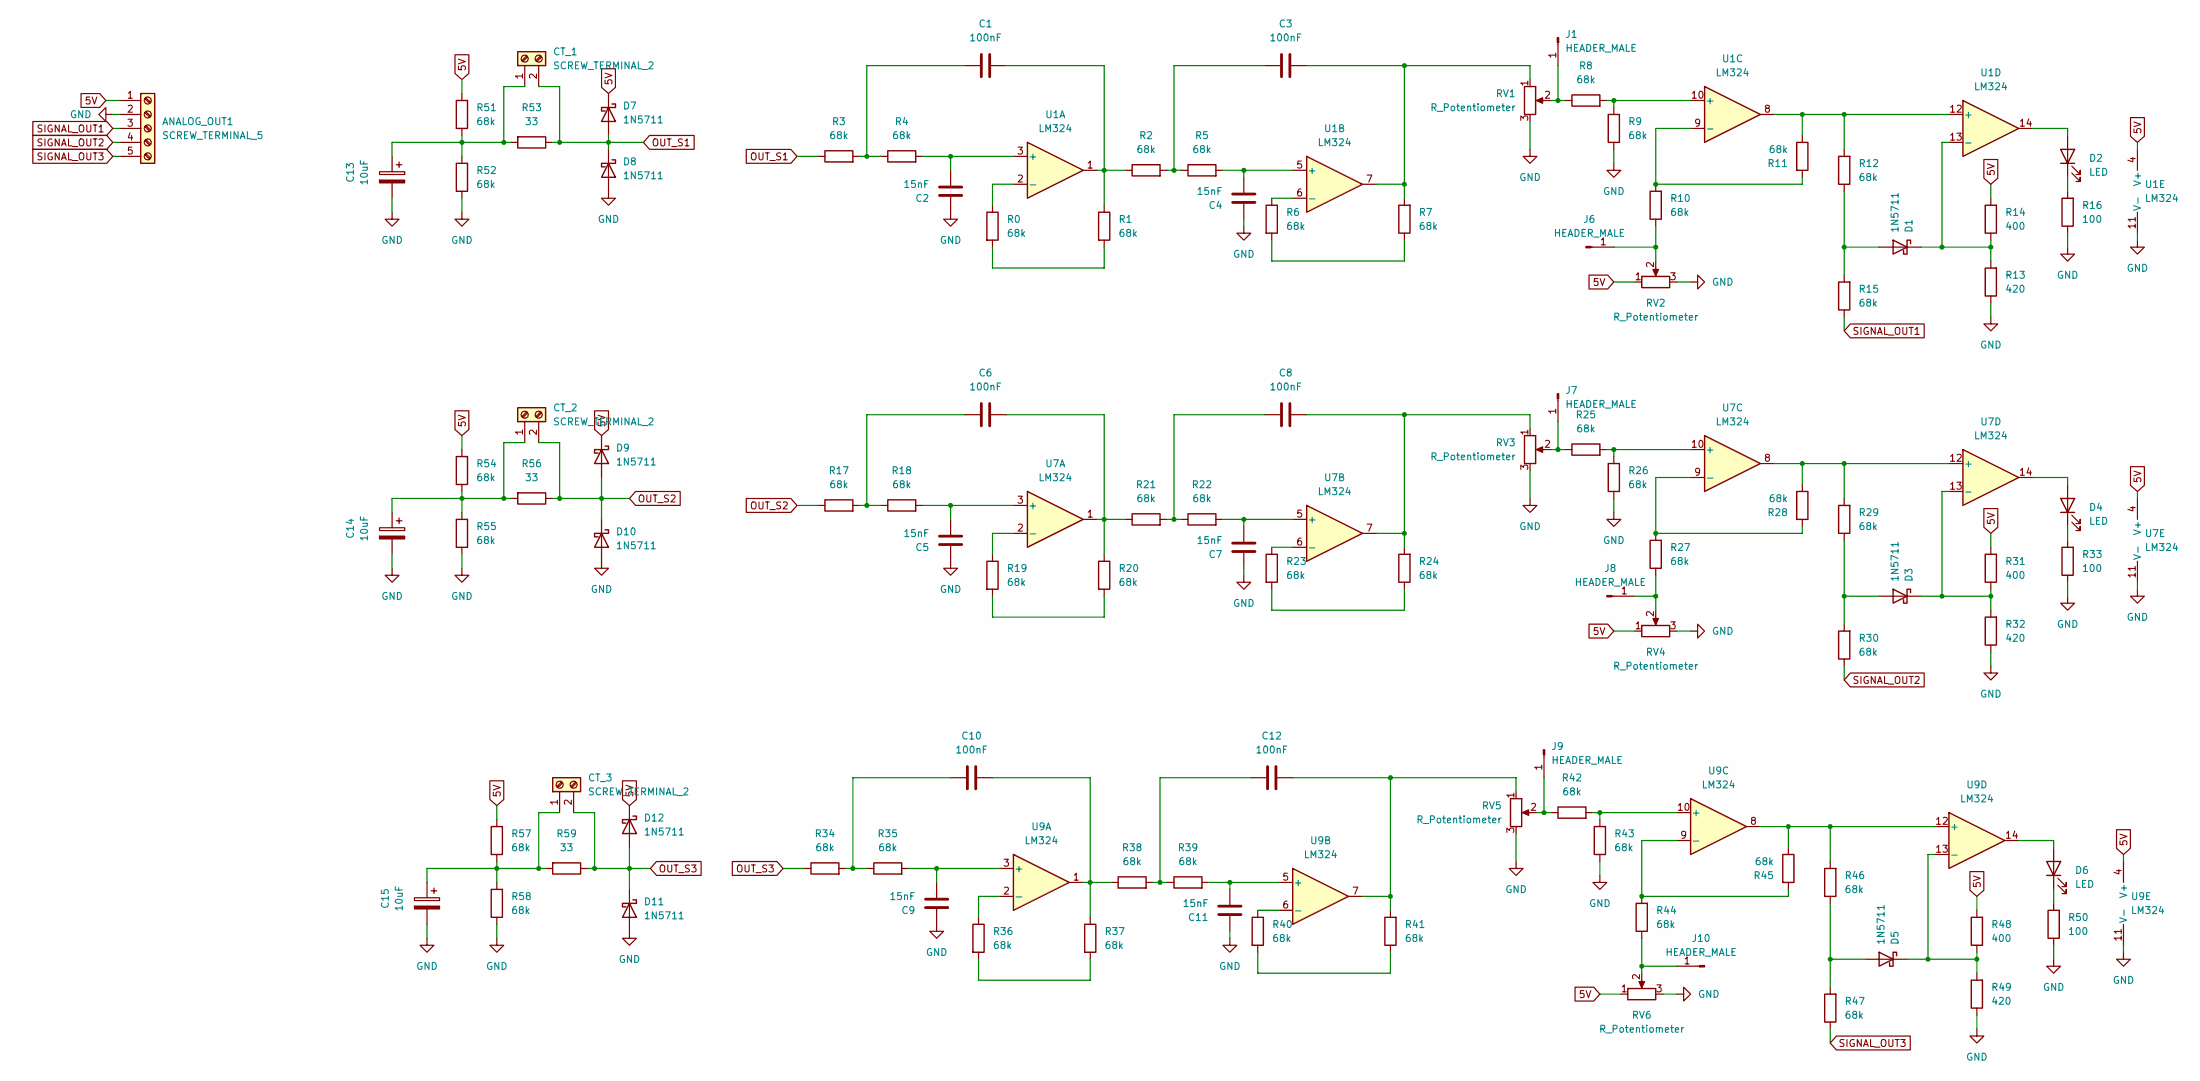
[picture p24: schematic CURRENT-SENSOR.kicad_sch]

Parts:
ANALOG_OUT1: SCREW_TERMINAL_5; TerminalBlock_Phoenix_MKDS-1,5-5-5.08_1x05_P5.08mm_Horizont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
C1, C3, C6, C8, C10, C12: 100nF; C_Rect_L11.0mm_W4.3mm_P10.00mm_MKT
C2, C4, C5, C7, C9, C11: 15nF; C_Rect_L7.0mm_W2.5mm_P5.00mm
C13, C14, C15: 10uF; CP_Radial_D5.0mm_P2.00mm
CT_1, CT_2, CT_3: SCREW_TERMINAL_2; TerminalBlock_Phoenix_MKDS-1,5-2-5.08_1x02_P5.08mm_Horizont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
D1, D3, D5, D7, D8, D9, D10, D11, D12: 1N5711; D_DO-35_SOD27_P7.62mm_Horizontal
D2, D4, D6: LED; LED_D4.0mm
J1, J6, J7, J8, J9, J10: HEADER_MALE; PinSocket_1x01_P2.54mm_Vertical
R0, R1, R2, R3, R4, R5, R6, R7, R8, R9, R10, R11, R12, R15, R17, R18, R19, R20, R21, R22, R23, R24, R25, R26, R27, R28, R29, R30, R34, R35, R36, R37, R38, R39, R40, R41, R42, R43, R44, R45, R46, R47, R51, R52, R54, R55, R57, R58: 68k; R_Axial_DIN0207_L6.3mm_D2.5mm_P7.62mm_Horizontal
R13, R32, R49: 420; R_Axial_DIN0207_L6.3mm_D2.5mm_P7.62mm_Horizontal
R14, R31, R48: 400; R_Axial_DIN0207_L6.3mm_D2.5mm_P7.62mm_Horizontal
R16, R33, R50: 100; R_Axial_DIN0207_L6.3mm_D2.5mm_P7.62mm_Horizontal
R53, R56, R59: 33; R_Axial_DIN0207_L6.3mm_D2.5mm_P7.62mm_Horizontal
RV1, RV2, RV3, RV4, RV5, RV6: R_Potentiometer; Potentiometer_Bourns_3296W_Vertical
U1, U7, U9: LM324; DIP-14_W7.62mm_LongPads

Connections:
5V: ANALOG_OUT1.1, D7.1 (K), D9.1 (K), D12.1 (K), R14.2, R31.2, R48.2, R51.2, R54.2, R57.2, RV2.1, RV4.1, RV6.1, U1.4 (V+), U7.4 (V+), U9.4 (V+)
GND: ANALOG_OUT1.2, C2.1, C4.1, C5.1, C7.1, C9.1, C11.1, C13.2, C14.2, C15.2, D8.2 (A), D10.2 (A), D11.2 (A), R9.1, R13.1, R16.1, R26.1, R32.1, R33.1, R43.1, R49.1, R50.1, R52.1, R55.1, R58.1, RV1.3, RV2.3, RV3.3, RV4.3, RV5.3, RV6.3, U1.11 (V-), U7.11 (V-), U9.11 (V-)
unnamed: C1.1, R3.2, R4.1
unnamed: C1.2, R1.1, R2.1, U1.1
unnamed: C3.1, R2.2, R5.1
unnamed: C3.2, R7.2, RV1.1, U1.7
unnamed: C6.1, R17.2, R18.1
unnamed: C6.2, R20.1, R21.1, U7.1
unnamed: C8.1, R21.2, R22.1
unnamed: C8.2, R24.2, RV3.1, U7.7
unnamed: C10.1, R34.2, R35.1
unnamed: C10.2, R37.1, R38.1, U9.1
unnamed: C12.1, R38.2, R39.1
unnamed: C12.2, R41.2, RV5.1, U9.7
unnamed: C13.1, CT_1.1, R51.1, R52.2, R53.2
unnamed: C14.1, CT_2.1, R54.1, R55.2, R56.2
unnamed: C15.1, CT_3.1, R57.1, R58.2, R59.2
unnamed: D1.2 (A), R12.1, R15.2
unnamed: D1.1 (K), R13.2, R14.1, U1.13 (-)
unnamed: D2.2 (A), U1.14
unnamed: D2.1 (K), R16.2
unnamed: D3.2 (A), R29.1, R30.2
unnamed: D3.1 (K), R31.1, R32.2, U7.13 (-)
unnamed: D4.2 (A), U7.14
unnamed: D4.1 (K), R33.2
unnamed: D5.2 (A), R46.1, R47.2
unnamed: D5.1 (K), R48.1, R49.2, U9.13 (-)
unnamed: D6.2 (A), U9.14
unnamed: D6.1 (K), R50.2
unnamed: J1.1, R8.1, RV1.2
unnamed: J6.1, R10.1, RV2.2
unnamed: J7.1, R25.1, RV3.2
unnamed: J8.1, R27.1, RV4.2
unnamed: J9.1, R42.1, RV5.2
unnamed: J10.1, R44.1, RV6.2
unnamed: R0.2, R1.2
unnamed: R6.2, R7.1
unnamed: R19.2, R20.2
unnamed: R23.2, R24.1
unnamed: R36.2, R37.2
unnamed: R40.2, R41.1
unnamed: C2.2, R4.2, U1.3 (+)
unnamed: R0.1, U1.2 (-)
unnamed: C4.2, R5.2, U1.5 (+)
unnamed: R6.1, U1.6 (-)
unnamed: R8.2, R9.2, U1.10 (+)
unnamed: R10.2, R11.2, U1.9 (-)
unnamed: R11.1, R12.2, U1.8, U1.12 (+)
unnamed: C5.2, R18.2, U7.3 (+)
unnamed: R19.1, U7.2 (-)
unnamed: C7.2, R22.2, U7.5 (+)
unnamed: R23.1, U7.6 (-)
unnamed: R25.2, R26.2, U7.10 (+)
unnamed: R27.2, R28.2, U7.9 (-)
unnamed: R28.1, R29.2, U7.8, U7.12 (+)
unnamed: C9.2, R35.2, U9.3 (+)
unnamed: R36.1, U9.2 (-)
unnamed: C11.2, R39.2, U9.5 (+)
unnamed: R40.1, U9.6 (-)
unnamed: R42.2, R43.2, U9.10 (+)
unnamed: R44.2, R45.2, U9.9 (-)
unnamed: R45.1, R46.2, U9.8, U9.12 (+)
OUT_S1: CT_1.2, D7.2 (A), D8.1 (K), R3.1, R53.1
OUT_S2: CT_2.2, D9.2 (A), D10.1 (K), R17.1, R56.1
OUT_S3: CT_3.2, D11.1 (K), D12.2 (A), R34.1, R59.1
SIGNAL_OUT1: ANALOG_OUT1.3, R15.1
SIGNAL_OUT2: ANALOG_OUT1.4, R30.1
SIGNAL_OUT3: ANALOG_OUT1.5, R47.1

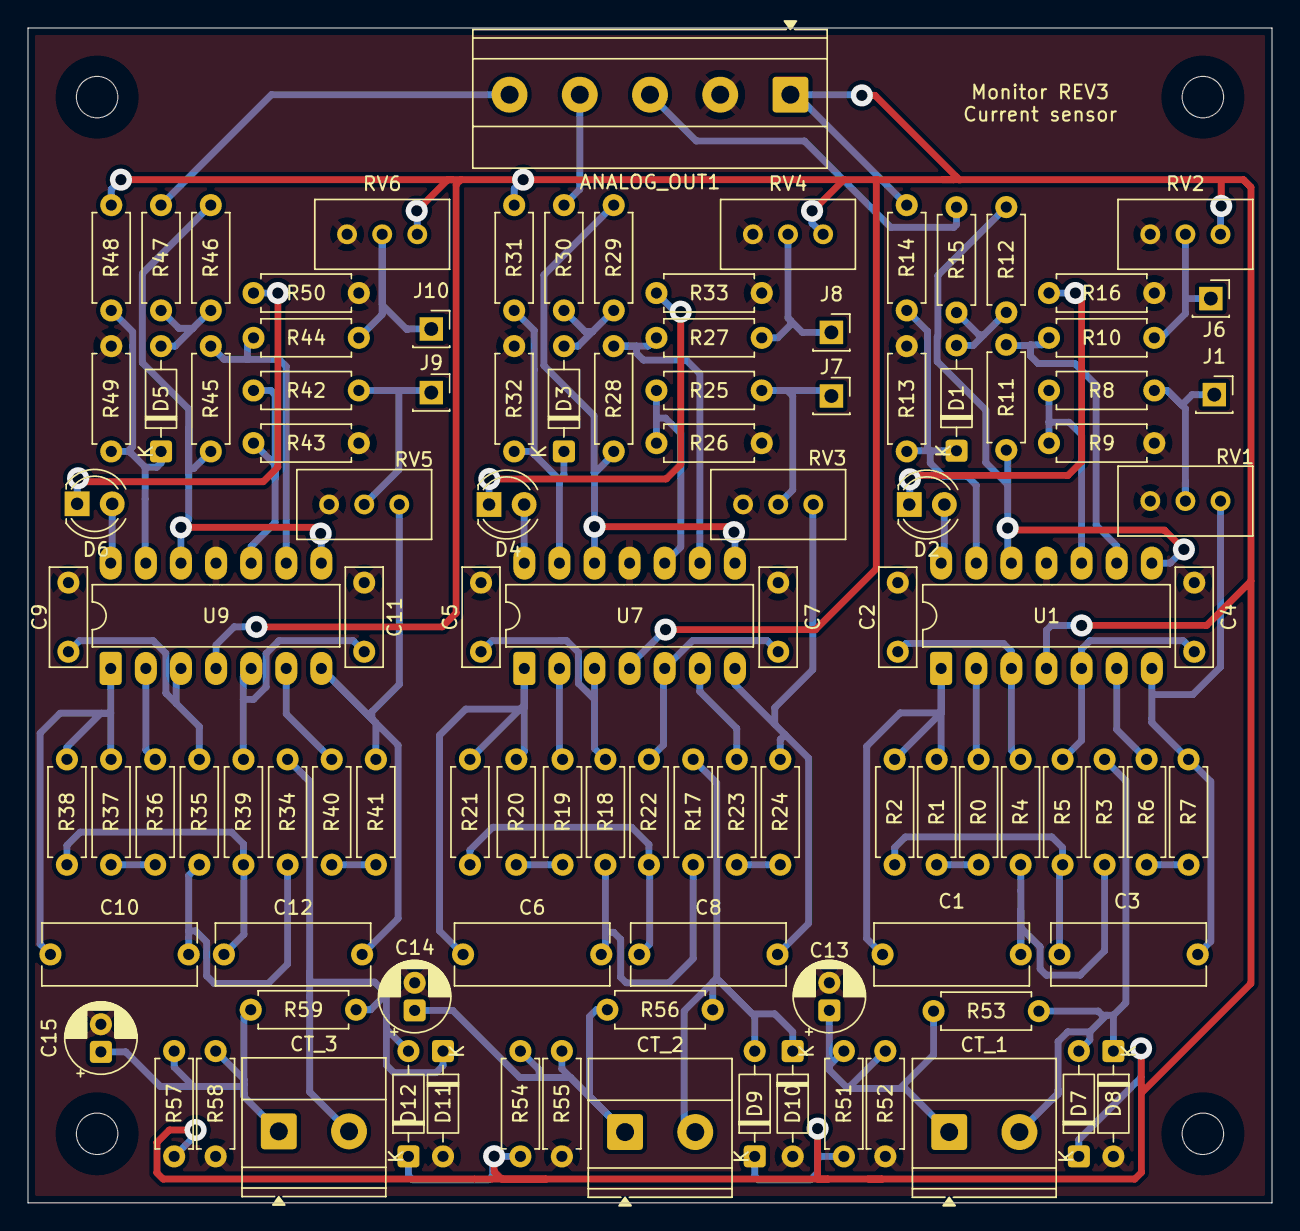
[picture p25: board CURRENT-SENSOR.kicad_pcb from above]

Board: 2 copper layers, 90.0 x 85.0 mm, 106 parts (0 on the bottom side), 68 nets.

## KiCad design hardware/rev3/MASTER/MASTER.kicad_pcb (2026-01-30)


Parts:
C1, C5: 100nF; C_Disc_D5.0mm_W2.5mm_P2.50mm
C3: 100 uF; CP_Radial_D8.0mm_P5.00mm
C4: 10uF; C_Disc_D7.5mm_W5.0mm_P5.00mm
D1, D2: LED; LED_D5.0mm
D3, D4, D6, D7, D8, D9: 1N5711; D_DO-35_SOD27_P7.62mm_Horizontal
D5: SMAJ24CA; D_SMA
DIGITAL_INPUTS1: SCREW_TERMINAL_5; TerminalBlock_Phoenix_MKDS-1,5-5-5.08_1x05_P5.08mm_Horizont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
ESP32: ESP32; ttgo_lora32
MODBUS_OUT1: SCREW_TERMINAL_5; TerminalBlock_Phoenix_MKDS-1,5-5-5.08_1x05_P5.08mm_Horizont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
PWR_IN1: SCREW_TERMINAL_2; TerminalBlock_Phoenix_MKDS-1,5-2-5.08_1x02_P5.08mm_Horizont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
R0, R1, R2, R3, R5, R8, R10, R12, R14: 10k; R_Axial_DIN0207_L6.3mm_D2.5mm_P7.62mm_Horizontal
R4: 100k; R_Axial_DIN0207_L6.3mm_D2.5mm_P7.62mm_Horizontal
R6: 1k; R_Axial_DIN0207_L6.3mm_D2.5mm_P7.62mm_Horizontal
R7, R9, R11, R13: 4.7k; R_Axial_DIN0207_L6.3mm_D2.5mm_P7.62mm_Horizontal
S1: MINI-SPDT-SW; SW_MINI-SPDT-SW
SW1, SW2, SW3, SW4, SW5: SW_Push; SW_PUSH_6mm
U1: MCP23017_SP; DIP-28_W7.62mm_LongPads
U2: RS485_TRANSCEIVER; XY-017
U4, U5, U6, U7: PC817; DIP-4_W7.62mm

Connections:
5V_IN: PWR_IN1.1, S1.2
+3.3V: D3.1 (K), ESP32.11 (3.3V), R0.1, R1.1, U1.9 (VDD), U1.18 (~RESET), U2.1 (VCC), U4.4, U5.4, U6.4, U7.4
+5V: C3.1, C4.1, C5.1, D2.2 (A), ESP32.13 (5V), MODBUS_OUT1.1, S1.3
A+: MODBUS_OUT1.5, U2.5 (A)
ADC_PIN_1: D3.2 (A), D4.1 (K), ESP32.19 (14), R6.1
B-: MODBUS_OUT1.4, U2.6 (B)
BAT: D5.2 (A2), DIGITAL_INPUTS1.1, R4.2, R7.2, R9.2, R11.2, R13.2
Button_1: SW1.1, U1.27 (GPA6)
Button_2: SW2.1, U1.25 (GPA4)
Button_3: SW3.1, U1.26 (GPA5)
Button_4: SW4.1, U1.24 (GPA3)
Button_5: SW5.1, U1.28 (GPA7)
Button_6: U1.3 (GPB2)
Button_7: U1.4 (GPB3)
D_IN_1: D6.2 (A), DIGITAL_INPUTS1.2, U4.2
D_IN_2: D7.2 (A), DIGITAL_INPUTS1.3, U5.2
D_IN_3: D8.2 (A), DIGITAL_INPUTS1.4, U6.2
D_IN_4: D9.2 (A), DIGITAL_INPUTS1.5, U7.2
GND: C1.2, C3.2, C4.2, C5.2, D4.2 (A), D5.1 (A1), ESP32.12 (GND), MODBUS_OUT1.2, PWR_IN1.2, R2.1, R3.1, R5.1, R8.1, R10.1, R12.1, R14.1, SW1.2, SW2.2, SW3.2, SW4.2, SW5.2, U1.10 (VSS), U1.15 (A0), U1.16 (A1), U1.17 (A2), U2.4 (GND)
GND_T: MODBUS_OUT1.3, U2.7 (GND)
INTA: ESP32.17 (34), R0.2, U1.20 (INTA)
INTB: ESP32.18 (35), R1.2, U1.19 (INTB)
IN_1: R8.2, U1.21 (GPA0), U4.3
IN_2: R10.2, U1.8 (GPB7), U5.3
IN_3: R12.2, U1.22 (GPA1), U6.3
IN_4: R14.2, U1.23 (GPA2), U7.3
LIBRE2: ESP32.25 (04)
LIBRE3: ESP32.26 (25)
unnamed: C1.1, R4.1, R5.2, R6.2
unnamed: D1.2 (A), S1.1
unnamed: D1.1 (K), R2.2
unnamed: D2.1 (K), R3.2
unnamed: D6.1 (K), R7.1, U4.1
unnamed: D7.1 (K), R9.1, U5.1
unnamed: D8.1 (K), R11.1, U6.1
unnamed: D9.1 (K), R13.1, U7.1
RX: ESP32.21 (13), U2.3 (RXD)
SCL: ESP32.4 (22), U1.12 (SCK)
SDA: ESP32.1 (21), U1.13 (SDA)
TX: ESP32.20 (12), U2.2 (TXD)

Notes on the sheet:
MLCC
Electronic or Tantalum


Board: 2 copper layers, 90.0 x 85.0 mm, 44 parts (0 on the bottom side), 36 nets.

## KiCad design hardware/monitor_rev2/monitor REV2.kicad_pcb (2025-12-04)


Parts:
C1, C4: 100uF; CP_Radial_D6.3mm_P2.50mm
C2, C3: 100nF; C_Disc_D3.0mm_W1.6mm_P2.50mm
D1, D2: 1N5819; D_DO-41_SOD81_P10.16mm_Horizontal
ESP32: ttgo_lora32
J1: Conn_01x02_Pin; PinSocket_1x02_P2.54mm_Vertical
J2: Conn_01x05; JST_XH_B5B-XH-A_1x05_P2.50mm_Vertical
JST_5V1: Conn_01x02; JST_XH_B2B-XH-A_1x02_P2.50mm_Vertical
PLANTA1: Screw_Terminal_01x03; TerminalBlock_Phoenix_MKDS-1,5-3-5.08_1x03_P5.08mm_Horizont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
R0, R1, R2, R3, R4, R5, R6, R7, R11: 10k; R_Axial_DIN0207_L6.3mm_D2.5mm_P7.62mm_Horizontal
R8, R9: 100k; R_Axial_DIN0207_L6.3mm_D2.5mm_P7.62mm_Horizontal
R10: 1.2k; R_Axial_DIN0207_L6.3mm_D2.5mm_P7.62mm_Horizontal
RV1, RV2: R_Potentiometer; Potentiometer_Bourns_3296W_Vertical
SW1: SW_DIP_x08; SW_DS01C-254-S-08BE
U1: 74HC165; DIP-16_W7.62mm
U2: PC817; DIP-4_W7.62mm_Socket_LongPads
U3: LM358; DIP-8_W7.62mm_LongPads
U4: XY-017

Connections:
+3.3V: ESP32.11 (3.3V), R0.1, R1.1, R2.1, R3.1, R4.1, R5.1, R6.1, R7.1, R11.2, U1.16 (VCC), U4.1 (VCC)
+5V: C1.1, C2.1, ESP32.13 (5V), J2.1, JST_5V1.1, R10.1, RV2.1, U3.8 (V+)
A+: J2.3, U4.5 (A)
B-: J2.4, U4.6 (B)
BATERIA: PLANTA1.1, RV1.1
E: J2.5, U4.7 (GND)
GND: C1.2, C2.2, C3.1, C4.2, ESP32.12 (GND), J2.2, JST_5V1.2, PLANTA1.2, RV1.3, RV2.3, SW1.9, SW1.10, SW1.11, SW1.12, SW1.13, SW1.14, SW1.15, SW1.16, U1.8 (GND), U1.15 (~CE), U2.3, U3.4 (V-), U4.4 (GND)
NIVEL_BATERIA: ESP32.18 (35), R9.2
unnamed: D1.2 (A), R8.2, R9.1
unnamed: D1.1 (K), RV2.2
unnamed: D2.2 (A), U3.1
unnamed: D2.1 (K), R8.1, U3.2 (-)
unnamed: C3.2, C4.1, J1.1, RV1.2
unnamed: J1.2, U3.3 (+)
unnamed: R10.2, U2.1
PIN_DATA: ESP32.19 (14), U1.9 (Q7)
PLANTA_IGN: PLANTA1.3, U2.2
PLANTA_ON: ESP32.17 (34), R11.1, U2.4
Pin_0: R0.2, SW1.8, U1.14 (D3)
Pin_1: R1.2, SW1.7, U1.13 (D2)
Pin_2: R2.2, SW1.6, U1.12 (D1)
Pin_3: R3.2, SW1.5, U1.11 (D0)
Pin_4: R7.2, SW1.4, U1.6 (D7)
Pin_5: R6.2, SW1.3, U1.5 (D6)
Pin_6: R5.2, SW1.2, U1.4 (D5)
Pin_7: R4.2, SW1.1, U1.3 (D4)
RX: ESP32.21 (13), U4.3 (RXD)
TX: ESP32.20 (12), U4.2 (TXD)
clockPin: ESP32.26 (25), U1.2 (CP)
latchPin: ESP32.25 (04), U1.1 (~PL)

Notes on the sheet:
BATTERY LEVEL
IGNITION DETECTION


Board: 2 copper layers, 95.0 x 95.0 mm, 30 parts (0 on the bottom side), 30 nets.

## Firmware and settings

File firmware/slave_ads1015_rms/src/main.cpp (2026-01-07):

/**
 * @file main.cpp
 * @brief Modbus RTU Slave Firmware with ADS1015 and real-time RMS calculation (ESP32).
 * @details This system acquires analog signals from 3 channels using ADS1015 ADC,
 * calculates real-time RMS values using circular FIFOs, maintains a measurement
 * history and responds to Modbus RTU queries over RS485. Includes channel-specific
 * conversion factors and improved ADC multiplexer handling.
 * @date 2025-12-04
 */

#include <Arduino.h>
#include <Wire.h>
#include <Adafruit_ADS1X15.h>
#include "HardwareSerial.h"
#include "ModbusServerRTU.h"

// =================================================================
// --- DEBUG / LOGGING ---
// =================================================================

// 0 = off, 1 = on
#define LOG_RMS 0
#define LOG_MODBUS_REG_UPDATE 0
#define LOG_LOOP 0
#define LOG_MODBUS_FRAMES 1

static void printHexBytes(const uint8_t *data, size_t len) {
    for (size_t i = 0; i < len; ++i) {
        Serial.printf("%02X", data[i]);
        if (i + 1 < len) Serial.print(' ');
    }
}

static void logModbusMessageHex(const char *tag, const ModbusMessage &msg) {
    ModbusMessage &nonConstMsg = const_cast<ModbusMessage &>(msg);
    Serial.printf("[MODBUS] %s len=%u : ", tag, (unsigned)nonConstMsg.size());
    const uint8_t *p = (const uint8_t *)nonConstMsg.data();
    printHexBytes(p, nonConstMsg.size());
    Serial.println();
}

/**
 * @brief Serial port instance for Modbus RS485 communication.
 * @ingroup group_modbus
 */
HardwareSerial ModbusSerial(1);

// =================================================================
// --- COMBINED CONFIGURATION ---
// =================================================================

/**
 * @def I2C_SDA_PIN
 * @brief I2C SDA pin for ADS1015 communication.
 * @ingroup group_hardware
 */
#define I2C_SDA_PIN 9

/**
 * @def I2C_SCL_PIN
 * @brief I2C SCL pin for ADS1015 communication.
 * @ingroup group_hardware
 */
#define I2C_SCL_PIN 8

/**
 * @def ADS_ALERT_PIN
 * @brief ADS1015 interrupt pin for completed conversions.
 * @ingroup group_hardware
 */
#define ADS_ALERT_PIN 10

/**
 * @var NUM_CHANNELS
 * @brief Number of ADC channels to sample.
 * @ingroup group_hardware
 */
const int NUM_CHANNELS = 3;

/**
 * @var FIFO_SIZE
 * @brief Circular FIFO buffer size for RMS calculation.
 * @ingroup group_adc_rms
 */
const int FIFO_SIZE = 320;

/**
 * @var PROCESS_INTERVAL_MS
 * @brief RMS processing interval in milliseconds.
 * @ingroup group_adc_rms
 */
const int PROCESS_INTERVAL_MS = 1000;

/**
 * @var RMS_HISTORY_SIZE
 * @brief RMS value history size for each channel.
 * @ingroup group_adc_rms
 */
const int RMS_HISTORY_SIZE = 100;

/**
 * @def SLAVE_ID
 * @brief Modbus slave device address.
 * @ingroup group_modbus
 */
#define SLAVE_ID 1

/**
 * @def NUM_REGISTERS
 * @brief Total number of Modbus registers available for RMS data.
 * @ingroup group_modbus
 */
#define NUM_REGISTERS 18

/**
 * @def RX_PIN
 * @brief UART receive pin for RS485.
 * @ingroup group_hardware
 */
#define RX_PIN 20

/**
 * @def TX_PIN
 * @brief UART transmit pin for RS485.
 * @ingroup group_hardware
 */
#define TX_PIN 21

/**
 * @var MODBUS_UPDATE_INTERVAL_MS
 * @brief Modbus register update interval in milliseconds.
 * @ingroup group_modbus
 */
const int MODBUS_UPDATE_INTERVAL_MS = 300;

/**
 * @var CONVERSION_FACTOR
 * @brief Global conversion factor (maintained for compatibility).
 * @deprecated Use CONVERSION_FACTORS array for channel-specific factors.
 * @ingroup group_adc_rms
 */
const float CONVERSION_FACTOR = 0.618f;

/**
 * @brief Channel-specific conversion factors for each ADC channel.
 * @details Enables individual channel calibration to compensate for differences
 * in sensors, signal conditioning or specific measurement ranges.
 * @ingroup group_adc_rms
 */
const float CONVERSION_FACTORS[NUM_CHANNELS] = {
    0.653f,  ///< Factor for Channel 0
    0.679f,  ///< Factor for Channel 1
    1.133f   ///< Factor for Channel 2
};

// =================================================================
// --- DATA STRUCTURES AND GLOBAL VARIABLES ---
// =================================================================

/**
 * @brief ADS1015 converter instance.
 * @ingroup group_hardware
 */
Adafruit_ADS1015 ads;

/**
 * @struct ADC_Sample
 * @brief ADC sample with value and associated channel.
 * @ingroup group_adc_rms
 */
struct ADC_Sample {
    int16_t value;   ///< ADC conversion value.
    uint8_t channel; ///< Channel from which the sample originates.
};

/**
 * @brief Communication queue for ADC samples.
 * @ingroup group_adc_rms
 */
QueueHandle_t queue_adc_samples;

/**
 * @struct RMS_FIFO
 * @brief Circular buffer for efficient RMS calculation.
 * @details Maintains cumulative sums for incremental mean and variance calculation.
 * @ingroup group_adc_rms
 */
struct RMS_FIFO {
    int16_t buffer[FIFO_SIZE]; ///< Circular sample buffer.
    int head = 0;              ///< Write index (buffer head).
    int count = 0;             ///< Number of valid samples in buffer.
    int64_t sum_x = 0;         ///< Cumulative sum of samples.
    int64_t sum_x2 = 0;        ///< Cumulative sum of squared samples.
};

/**
 * @brief Array of FIFOs for each measurement channel.
 * @ingroup group_adc_rms
 */
RMS_FIFO fifos[NUM_CHANNELS];

/**
 * @brief RMS value history for channel 0.
 * @ingroup group_adc_rms
 */
float rms_history_ch0[RMS_HISTORY_SIZE];

/**
 * @brief RMS value history for channel 1.
 * @ingroup group_adc_rms
 */
float rms_history_ch1[RMS_HISTORY_SIZE];

/**
 * @brief RMS value history for channel 2.
 * @ingroup group_adc_rms
 */
float rms_history_ch2[RMS_HISTORY_SIZE];

/**
 * @brief Write index for RMS histories.
 * @ingroup group_adc_rms
 */
volatile int rms_history_head = 0;

/**
 * @brief Mutex for concurrent access protection to RMS histories.
 * @ingroup group_adc_rms
 */
SemaphoreHandle_t rms_history_mutex;

/**
 * @brief ADC data ready flag (ISR).
 * @ingroup group_adc_rms
 */
volatile bool adc_data_ready = false;

/**
 * @brief Current channel in sampling sequence (ISR).
 * @ingroup group_adc_rms
 */
volatile uint8_t current_isr_channel = 0;

/**
 * @brief Modbus RTU server with 2000ms timeout.
 * @ingroup group_modbus
 */
ModbusServerRTU MBserver(2000);

/**
 * @brief Modbus registers for RMS data.
 * @ingroup group_modbus
 */
uint16_t holdingRegisters[NUM_REGISTERS];

/**
 * @brief Mutex for Modbus register protection.
 * @ingroup group_modbus
 */
SemaphoreHandle_t dataMutex;

/**
 * @brief Handle for Modbus data update task.
 * @ingroup group_modbus
 */
TaskHandle_t dataUpdateTaskHandle;

// =================================================================
// --- FUNCTIONS (ADC and RMS) ---
// =================================================================

/**
 * @brief Interrupt service routine for completed ADC conversions.
 * @details Executes when ADS1015 completes a conversion and activates ALERT line.
 * @ingroup group_adc_rms
 */
void IRAM_ATTR on_adc_data_ready() { adc_data_ready = true; }

/**
 * @brief ADC data acquisition task with improved multiplexer handling.
 * @details Manages ADC conversion sequence in round-robin mode between channels.
 * Implements explicit multiplexer configuration selection for each channel.
 * Enqueues samples in `queue_adc_samples` for subsequent processing.
 * @param pvParameters Task parameters (unused).
 * @ingroup group_adc_rms
 */
void task_adquisicion(void *pvParameters) {
    ads.startADCReading(ADS1X15_REG_CONFIG_MUX_SINGLE_0, false);
    while (true) {
        if (adc_data_ready) {
            adc_data_ready = false;
            ADC_Sample sample = {ads.getLastConversionResults(), current_isr_channel};
            xQueueSend(queue_adc_samples, &sample, 0);
            
            current_isr_channel = (current_isr_channel + 1) % NUM_CHANNELS;
            
            /**
             * @brief Explicit multiplexer configuration selection per channel.
             * @details Direct mapping from channel number to ADS1015 multiplexer
             * configuration constant to avoid addressing errors.
             */
            uint16_t mux_config;
            switch(current_isr_channel) {
                case 0: mux_config = ADS1X15_REG_CONFIG_MUX_SINGLE_0; break;
                case 1: mux_config = ADS1X15_REG_CONFIG_MUX_SINGLE_1; break;
                case 2: mux_config = ADS1X15_REG_CONFIG_MUX_SINGLE_2; break;
                default: mux_config = ADS1X15_REG_CONFIG_MUX_SINGLE_0; break;
            }
            ads.startADCReading(mux_config, false);

        } else { vTaskDelay(1); }
    }
}

/**
 * @brief Sample processing and RMS calculation task.
 * @details Consumes samples from `queue_adc_samples`, stores them in circular FIFOs
 * and periodically calculates RMS values using efficient incremental algorithms.
 * Updates RMS history in a thread-safe manner.
 * @param pvParameters Task parameters (unused).
 * @ingroup group_adc_rms
 */
void task_procesamiento(void *pvParameters) {
    ADC_Sample sample;
    TickType_t last_process_time = xTaskGetTickCount();
    const int samples_per_channel = NUM_REGISTERS / NUM_CHANNELS;

    while (true) {
        while (xQueueReceive(queue_adc_samples, &sample, 0) == pdTRUE) {
            if (sample.channel < NUM_CHANNELS) {
                RMS_FIFO &fifo = fifos[sample.channel];
                if (fifo.count == FIFO_SIZE) {
                    int16_t old_val = fifo.buffer[fifo.head];
                    fifo.sum_x -= old_val;
                    fifo.sum_x2 -= (int64_t)old_val * old_val;
                } else { fifo.count++; }
                fifo.buffer[fifo.head] = sample.value;
                fifo.sum_x += sample.value;
                fifo.sum_x2 += (int64_t)sample.value * sample.value;
                fifo.head = (fifo.head + 1) % FIFO_SIZE;
            }
        }
        
        if (xTaskGetTickCount() - last_process_time >= pdMS_TO_TICKS(PROCESS_INTERVAL_MS)) {
            last_process_time = xTaskGetTickCount();
            float calculated_rms[NUM_CHANNELS] = {0};
            
            // --- PARTE A: CALCULAR Y GUARDAR HISTORIAL ---
            if (xSemaphoreTake(rms_history_mutex, portMAX_DELAY) == pdTRUE) {
                for (int i = 0; i < NUM_CHANNELS; i++) {
                    if (fifos[i].count > 0) {
                        double mean = (double)fifos[i].sum_x / fifos[i].count;
                        double var = ((double)fifos[i].sum_x2 / fifos[i].count) - (mean * mean);
                        calculated_rms[i] = sqrt(var < 0 ? 0 : var);
                    }
                }
                rms_history_ch0[rms_history_head] = calculated_rms[0];
                rms_history_ch1[rms_history_head] = calculated_rms[1];
                rms_history_ch2[rms_history_head] = calculated_rms[2];
                
                #if LOG_RMS
                Serial.printf("[RMS] T=%lu head=%d CH0=%.1f CH1=%.1f CH2=%.1f\n",
                              millis(), rms_history_head,
                              calculated_rms[0], calculated_rms[1], calculated_rms[2]);
                #endif
                
                rms_history_head = (rms_history_head + 1) % RMS_HISTORY_SIZE;
                xSemaphoreGive(rms_history_mutex);
            }

            // --- PARTE B: ACTUALIZAR MODBUS ---
            if (xSemaphoreTake(dataMutex, portMAX_DELAY) == pdTRUE) {
                float rms_channel[NUM_CHANNELS][samples_per_channel];
                int counts[NUM_CHANNELS];

                for (int ch = 0; ch < NUM_CHANNELS; ch++) {
                    counts[ch] = get_rms_history(ch, rms_channel[ch], samples_per_channel);
                }

                for (int ch = 0; ch < NUM_CHANNELS; ch++) {
                    for (int i = 0; i < samples_per_channel; i++) {
                        int idx = ch * samples_per_channel + i;
                        float volts = rms_channel[ch][i] * CONVERSION_FACTORS[ch]; 
                        holdingRegisters[idx] = (counts[ch] > i) ? (uint16_t)round(volts) : 0;
                    }
                }
                
                #if LOG_MODBUS_REG_UPDATE
                Serial.printf("[MODBUS] Regs CH0: %u,%u,%u,%u,%u,%u\n",
                              holdingRegisters[0], holdingRegisters[1], holdingRegisters[2],
                              holdingRegisters[3], holdingRegisters[4], holdingRegisters[5]);
                #endif
                
                xSemaphoreGive(dataMutex);
            }
        }
        vTaskDelay(pdMS_TO_TICKS(10));
    }
}

/**
 * @brief Gets RMS value history for a specific channel.
 * @details Extracts the last N RMS values in a thread-safe manner using mutex.
 * Values are returned in chronological order (oldest first).
 * @param channel Channel number (0, 1 or 2).
 * @param output_buffer Output buffer for RMS values.
 * @param count Number of requested values.
 * @return Number of values actually copied.
 * @ingroup group_adc_rms
 */
int get_rms_history(int channel, float* output_buffer, int count) {
    if (count > RMS_HISTORY_SIZE || channel < 0 || channel >= NUM_CHANNELS) {
        return 0;
    }

    float* source_buffer;
    switch(channel) {
        case 0: source_buffer = rms_history_ch0; break;
        case 1: source_buffer = rms_history_ch1; break;
        case 2: source_buffer = rms_history_ch2; break;
        default: return 0;
    }

    if (xSemaphoreTake(rms_history_mutex, pdMS_TO_TICKS(10)) == pdTRUE) {
        int most_recent_idx = (rms_history_head == 0) ? (RMS_HISTORY_SIZE - 1) : (rms_history_head - 1);
        for (int i = 0; i < count; i++) {
            int source_idx = (most_recent_idx - (count - 1 - i) + RMS_HISTORY_SIZE) % RMS_HISTORY_SIZE;
            output_buffer[i] = source_buffer[source_idx];
        }
        xSemaphoreGive(rms_history_mutex);
        return count;
    }
    return 0;
}

// =================================================================
// --- FUNCTIONS (Modbus) ---
// =================================================================

/**
 * @brief Modbus register update task with per-channel conversion factors.
 * @details Periodically updates Modbus registers with latest RMS values
 * from all channels. Dynamically organizes data according to configured number of channels.
 * Applies channel-specific conversion factors from CONVERSION_FACTORS array.
 * @param pvParameters Task parameters (unused).
 * @ingroup group_modbus
 */
void dataUpdateTask(void *pvParameters) {
    Serial.println("Data update task started on Core 0.");

    const int samples_per_channel = NUM_REGISTERS / NUM_CHANNELS;

    while (true) {
        if (xSemaphoreTake(dataMutex, portMAX_DELAY) == pdTRUE) {
            float rms_channel[NUM_CHANNELS][samples_per_channel];
            int counts[NUM_CHANNELS];

            for (int ch = 0; ch < NUM_CHANNELS; ch++) {
                counts[ch] = get_rms_history(ch, rms_channel[ch], samples_per_channel);
            }

            for (int ch = 0; ch < NUM_CHANNELS; ch++) {
                for (int i = 0; i < samples_per_channel; i++) {
                    int idx = ch * samples_per_channel + i;
                    
                    /**
                     * @brief Application of channel-specific conversion factor.
                     * @details Uses CONVERSION_FACTORS[ch] instead of global factor
                     * to enable individual channel calibration.
                     */
                    float volts = rms_channel[ch][i] * CONVERSION_FACTORS[ch]; 
                    
                    holdingRegisters[idx] = (counts[ch] > i) ? (uint16_t)round(volts) : 0;
                }
            }

            xSemaphoreGive(dataMutex);
        }
        vTaskDelay(pdMS_TO_TICKS(MODBUS_UPDATE_INTERVAL_MS));
    }
}

/**
 * @struct SensorData
 * @brief Sensor configuration parameters for Modbus discovery.
 * @ingroup group_modbus
 */
struct SensorData {
    uint16_t sensorID;          ///< Unique sensor identifier.
    uint16_t numberOfChannels;  ///< Number of measurement channels.
    uint16_t startAddress;      ///< Data start address in Modbus registers.
    uint16_t maxRegisters;      ///< Maximum number of available registers.
    uint16_t samplingInterval;  ///< Sampling interval in milliseconds.
    uint16_t dataType;          ///< Data type: 1=uint8, 2=uint16, 3=compressed bytes, 4=float16.
    uint16_t scale;             ///< Scale factor (10^scale).
    uint16_t compressedBytes;   ///< Bytes per compressed value (only if dataType=3).
};

/**
 * @brief Sensor configuration for discovery responses.
 * @ingroup group_modbus
 */
SensorData sensor = {1, 3, 10, NUM_REGISTERS, PROCESS_INTERVAL_MS, 1, 1, 0};

/**
 * @brief Worker to handle Modbus holding register read requests.
 * @details Responds to two types of queries:
 * - Registers 0-7: Sensor configuration parameters
 * - Registers 10+: Historical RMS data
 * Implements address boundary validation to prevent invalid access.
 * @param request Received Modbus request message.
 * @return ModbusMessage Formatted Modbus response.
 * @ingroup group_modbus
 */
ModbusMessage readHoldingRegistersWorker(ModbusMessage request) {
    uint16_t address, words;
    ModbusMessage response;

    #if LOG_MODBUS_FRAMES
    logModbusMessageHex("RX", request);
    #endif

    request.get(2, address);
    request.get(4, words);

    #if LOG_MODBUS_FRAMES
    Serial.printf("[MODBUS] Req: SID=%u FC=%u addr=%u words=%u\n",
                  (unsigned)request.getServerID(), (unsigned)request.getFunctionCode(),
                  (unsigned)address, (unsigned)words);
    #endif

    if (address == 0 && words == 8) {
        response.add(request.getServerID(), request.getFunctionCode(), (uint8_t)(words * 2));
        response.add(sensor.sensorID);
        response.add(sensor.numberOfChannels);
        response.add(sensor.startAddress);
        response.add(sensor.maxRegisters);
        response.add(sensor.samplingInterval);
        response.add(sensor.dataType);
        response.add(sensor.scale);
        response.add(sensor.compressedBytes);

        #if LOG_MODBUS_FRAMES
        logModbusMessageHex("TX", response);
        #endif
        return response;
    }
    else if (address == 10 && words == NUM_REGISTERS)
    {
        if (xSemaphoreTake(dataMutex, pdMS_TO_TICKS(100)) == pdTRUE) {
            response.add(request.getServerID(), request.getFunctionCode(), (uint8_t)(words * 2));
            for (uint16_t i = 0; i < words; ++i) {
                response.add((uint16_t)holdingRegisters[i]);
            }

            #if LOG_MODBUS_FRAMES
            Serial.print("[MODBUS] TX regs:");
            for (uint16_t i = 0; i < words; ++i) {
                Serial.printf(" %u", (unsigned)holdingRegisters[i]);
            }
            Serial.println();
            logModbusMessageHex("TX", response);
            #endif

            xSemaphoreGive(dataMutex);
        } else {
            response.setError(request.getServerID(), request.getFunctionCode(), SERVER_DEVICE_BUSY);

            #if LOG_MODBUS_FRAMES
            logModbusMessageHex("TX-EX", response);
            #endif
        }
        return response;
    }
    else if (address >= NUM_REGISTERS || (address + words) > NUM_REGISTERS) {
        response.setError(request.getServerID(), request.getFunctionCode(), ILLEGAL_DATA_ADDRESS);

        #if LOG_MODBUS_FRAMES
        logModbusMessageHex("TX-EX", response);
        #endif
        return response;
    }
    else {
        response.setError(request.getServerID(), request.getFunctionCode(), ILLEGAL_DATA_ADDRESS);

        #if LOG_MODBUS_FRAMES
        logModbusMessageHex("TX-EX", response);
        #endif
        return response;
    }
}

// =================================================================
// --- SETUP AND LOOP ---
// =================================================================
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
void loop() {
    vTaskDelay(pdMS_TO_TICKS(1000));

    #if LOG_LOOP
    Serial.println("Main loop active...");
    const int num_datos = 6;
    float datos_ch1[num_datos];
    int obtenidos = get_rms_history(1, datos_ch1, num_datos);
    if (obtenidos > 0) {
        Serial.printf("Last %d RMS from Channel 1 (in ADC units):\n", obtenidos);
        for (int i = 0; i < obtenidos; i++) {
            Serial.printf("  %.3f\n", datos_ch1[i]);
        }
    }
    #endif
}

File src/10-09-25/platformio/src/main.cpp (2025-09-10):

/**********************************************************************************************************************
 * @file        main.cpp
 * @author      Manuel Felipe Ospina
 * @date        2025-09-03
 * @version     1.0
 *
 * @brief       Firmware for NEMO (Node for Electromechanical Monitoring &
 *Operation).
 * @details     This firmware runs on an ESP32 and is designed for the
 *acquisition, processing, and transmission of analog signals (current/voltage).
 *It features an OLED display for real-time visualization and uses LoRaWAN for
 *data uplink.
 *
 * --------------------------------------------------------------------------------------------------------------------
 *
 * @copyright   Copyright (c) 2025, EMASA. All rights reserved.
 *
 * @license     Pending
 *
 **********************************************************************************************************************
 *
 * System Architecture:
 * --------------------
 * The system uses FreeRTOS to manage concurrent tasks for data acquisition,
 *processing, and communication.
 * - An ISR (`onADCTimer`) samples ADC pins at a high frequency (`FS_HZ`) and
 *stores data in a circular FIFO buffer.
 * - `TaskProcesamiento`: Periodically calculates RMS values from the FIFO,
 *applies an adaptive EMA filter, and sends the results to a processing queue.
 * - `TaskRegistroResultados`: Collects processed results into blocks. Once a
 *block is full or the system is disabled, it encodes the data into a bit-packed
 *LoRaWAN payload.
 * - `tareaLoRa`: Manages the LoRaWAN communication, sending payloads from a
 *queue and handling TX/RX events.
 * - `TaskBatteryLevel`: Periodically measures the battery voltage.
 * - `TaskDisplay`: Manages the OLED screen, showing a boot sequence and a log
 *of recent LoRaWAN transmissions.
 * - `TaskMonitorPin`: Controls the system's global enable/disable state based
 *on a physical pin.
 *
 * Main Features:
 * --------------
 * - Multi-channel ADC sampling using a hardware timer ISR.
 * - Efficient RMS calculation with a running circular buffer.
 * - Adaptive Exponential Moving Average (EMA) filtering for signal smoothing.
 * - Data blocking and bit-packed payload encoding for efficient LoRaWAN
 *transmission.
 * - LoRaWAN uplink configured for US915 (Sub-band 7, DR3).
 * - Battery level monitoring.
 * - System ON/OFF control via `MONITOR_PIN`.
 * - OLED display with boot logo and event history.
 *
 * Hardware Configuration:
 * -----------------------
 * - MCU:          ESP32
 * - Display:      128x64 OLED (I2C Addr: 0x3C)
 * - LoRa Module:  (LMIC compatible)
 * - NSS:        GPIO 18
 * - RST:        GPIO 14
 * - DIO{0,1,2}: GPIO {26, 33, 32}
 * - Analog Inputs:
 * - Voltage 1:  GPIO 36
 * - Voltage 2:  GPIO 39
 * - Voltage 3:  GPIO 34
 * - Current 1:  GPIO 25
 * - Control & Monitoring:
 * - System EN/DIS: GPIO 35 (MONITOR_PIN)
 * - Battery ADC:   GPIO 14 (BATTERY_PIN) *Note: Same as LoRa RST.*
 *
 * Dependencies:
 * -------------
 * - Arduino Core for ESP32
 * - FreeRTOS (ESP-IDF)
 * - ESP32AnalogRead library
 * - MCCI LoRaWAN LMIC library
 * - Adafruit GFX and Adafruit SSD1306 libraries
 *
 * Revision History:
 * -----------------
 * Version |    Date    |     Author      |              Description
 * --------|------------|-----------------|----------------------------------------------------
 * 1.0     | 2025-09-03 | Manuel F. Ospina| Changed LoRa message transmission to
 *a unified |            |                 | message model, replacing previous
 *fragmented system.
 * --------|------------|-----------------|----------------------------------------------------
 * 1.1     | 2025-09-05 | Manuel F. Ospina| Redesigned payload format into a
 *unified, scalable |            |                 | and modular message model
 *for LoRa transmission.
 * --------|------------|-----------------|----------------------------------------------------
 *
 *********************************************************************************************************************/
#include <Arduino.h>

// Display
#include <Adafruit_GFX.h>
#include <Adafruit_SSD1306.h>
#include <Fonts/Picopixel.h>
#include <Fonts/TomThumb.h> // fuente ultra pequeña
#include <Wire.h>

// Logo de arranque (20x20px)
const unsigned char epd_bitmap_[] PROGMEM = {
    // 'Asset 3, 20x20px
    0x00, 0x00, 0x00, 0x07, 0xfe, 0x00, 0x1f, 0xff, 0x80, 0x3f, 0xff, 0xc0,
    0x7e, 0x07, 0xe0, 0x78, 0x01, 0xf0, 0x71, 0xf8, 0xe0, 0x03, 0xfc, 0x00,
    0x07, 0xff, 0x00, 0x0f, 0xff, 0x00, 0x0f, 0x0f, 0x00, 0x06, 0x02, 0x00,
    0x00, 0xf0, 0x00, 0x00, 0xf0, 0x00, 0x00, 0xf0, 0x00, 0x00, 0x60, 0x00,
    0x00, 0x00, 0x00, 0x00, 0x00, 0x00, 0x00, 0x00, 0x00, 0x00, 0x00, 0x00};

// ADC, math, RTOS, LoRa
#include <ESP32AnalogRead.h>
#include <math.h>
#include <stdint.h>
#include <vector>
// Deshabilitar ventana RX de recepción
#define DISABLE_INVERT_IQ_ON_RX 1
#define DISABLE_RX 1

#include <SPI.h>
#include <hal/hal.h>
#include <lmic.h>

// ==================== DEFINES / PARÁMETROS ====================
// Parámetros del display
constexpr int SCREEN_WIDTH = 128;
constexpr int SCREEN_HEIGHT = 64;
constexpr int OLED_RESET = -1;
Adafruit_SSD1306 display(SCREEN_WIDTH, SCREEN_HEIGHT, &Wire, OLED_RESET);

#define MONITOR_PIN 35
volatile bool sistema_habilitado = false;

// ==================== PARÁMETROS DEL PIN_ACTIVACIÓN ====================

// ==================== PARÁMETROS DEL SISTEMA ====================
// Valores por defecto - pueden ser sobrescritos desde platformio.ini usando build_flags
#ifndef FS_HZ
#define FS_HZ 960
#endif
#ifndef EMA_ALPHA
#define EMA_ALPHA 0.08f
#endif
#ifndef PROCESS_PERIOD_MS
#define PROCESS_PERIOD_MS 300
#endif

// Constantes internas optimizadas (usando los valores definidos arriba)
constexpr int SYSTEM_FS_HZ = FS_HZ;
constexpr float SYSTEM_EMA_ALPHA = EMA_ALPHA;
constexpr int SYSTEM_PROCESS_PERIOD_MS = PROCESS_PERIOD_MS;

constexpr int NUM_PINES = 4;
constexpr int RESULTADOS_POR_BLOQUE = 20;

constexpr size_t LORA_PAYLOAD_MAX = 220; // Payload máximo para DR3

// ==================== REGISTRO PARA LCD (NUEVA ESTRUCTURA)
// ====================
#define NUM_EVENTOS_LCD 3

// Nueva estructura de datos para la comunicación con la pantalla.
// Contiene toda la información necesaria para mostrar un envío.
struct DisplayInfo
{
    unsigned long timestamp_s;
    bool sistema_activo;
    bool bateria_incluida;
    float valor_bateria;
    float primer_valor_corriente;
    float primer_valor_voltaje1; // Podríamos mostrar los 3, pero simplificamos
};

// Cola para enviar la información a la tarea de display.
QueueHandle_t queueDisplayInfo;

// ==================== BATTERY LEVEL CONFIG ====================
#define BATTERY_PIN 14            // Cambia esto según tu conexión
#define BATTERY_BUFFER_SIZE 1     // Muestras por paquete
#define BATTERY_INTERVAL_MS 60000 // 60 segundos

struct ResultadoBattery
{
    unsigned long timestamp;
    uint8_t nivel_codificado;
};
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

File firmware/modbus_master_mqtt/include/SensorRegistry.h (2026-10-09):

#ifndef SENSOR_REGISTRY_H
#define SENSOR_REGISTRY_H

#include <cstdint>
#include <array>

// =================================================================================================
// Symbolic sensor IDs.
// =================================================================================================
// IMPORTANT! These IDs are part of the wire format of the LoRa payload
// (see construirPayloadUnificado). They must NOT be reordered or reassigned
// without coordinating with the gateway/codec owner.

/**
 * @def SENSOR_ID_BATERIA
 * @brief Bit 0 of the Activate Byte.
 */
constexpr uint8_t SENSOR_ID_BATERIA = 0;

/**
 * @def SENSOR_ID_VOLTAJE
 * @brief Bit 1 of the Activate Byte.
 */
constexpr uint8_t SENSOR_ID_VOLTAJE = 1;

/**
 * @def SENSOR_ID_CORRIENTE
 * @brief Bit 2 of the Activate Byte.
 */
constexpr uint8_t SENSOR_ID_CORRIENTE = 2;

/**
 * @def SENSOR_ID_EXT_START
 * @brief Start of IDs for external sensors (Bits 3-7).
 */
constexpr uint8_t SENSOR_ID_EXT_START = 3;

/**
 * @def MAX_SENSORES_EXTERNOS
 * @brief Number of remaining available bits in the Activate Byte (3 to 7).
 */
constexpr int MAX_SENSORES_EXTERNOS = 5;

// =================================================================================================
// Named IDs for the external sensors (aliases of SENSOR_ID_EXT_START + n).
// =================================================================================================
// El orden coincide con los bits 3..7 del Activate Byte y con el codec del gateway:
//   EXT+0 = real_power, EXT+1 = apparent_power, EXT+2 = reactive_power,
//   EXT+3 = power_factor, EXT+4 = frequency.

/** @brief Potencia Activa Total. Bit 3 (EXT+0). */
constexpr uint8_t SENSOR_ID_POTENCIA_ACTIVA   = SENSOR_ID_EXT_START + 0;

/** @brief Potencia Aparente Total. Bit 4 (EXT+1). */
constexpr uint8_t SENSOR_ID_POTENCIA_APARENTE = SENSOR_ID_EXT_START + 1;

/** @brief Potencia Reactiva Total. Bit 5 (EXT+2). */
constexpr uint8_t SENSOR_ID_POTENCIA_REACTIVA = SENSOR_ID_EXT_START + 2;

/** @brief Factor de Potencia Combinado. Bit 6 (EXT+3). */
constexpr uint8_t SENSOR_ID_FACTOR_POTENCIA   = SENSOR_ID_EXT_START + 3;

/** @brief Frecuencia Fase A. Bit 7 (EXT+4). */
constexpr uint8_t SENSOR_ID_FRECUENCIA        = SENSOR_ID_EXT_START + 4;

// =================================================================================================
// Priority configuration.
// =================================================================================================
// Sensors listed here trigger immediate transmission in the aggregator task.
// Add or remove IDs here without touching the rest of the logic.

/**
 * @brief Sensors that act as "Bus Drivers" (i.e. trigger the send).
 */
constexpr std::array<uint8_t, 2> DEFINED_PRIORITY_IDS = {
    SENSOR_ID_VOLTAJE,
    SENSOR_ID_CORRIENTE
};

#endif // SENSOR_REGISTRY_H

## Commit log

2025-08-21 Replacement of FreeRTOS task-based acquisition sys
    - ADC acquisition task removed
    - Samples are now captured via software ISR
    - Circular queue accumulates sum of values
    - RMS calculation simplified by obtaining the accumulated value directly
    ---
    NOTE: peding for cleaning code
    [main.cpp]
2025-08-21 Data acquisition board Monitor
    single-layer design
    [monitor.kicad_pcb, monitor.kicad_sch]
2025-08-25 Bit packaging function implemented
    Bit packaging function implemented in current signal data
    Note: temporary implementation, unification of messages into a single
    pending message
    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
2025-09-03 Implement unified LoRa payload
    This commit introduces a major architectural refactor to improve
    firmware efficiency, robustness, and clarity. The primary change is the
    consolidation of all sensor and status data into a single, unified
    LoRaWAN payload, replacing the previous fragmented message system.
    This approach significantly reduces uplink traffic, simplifies backend
    decoding, and ensures data atomicity.
2025-09-05 Redesign LoRa payload format
    - Refactored the LoRa message handling system by replacing the fragmented
    payload structure with a unified model. The new design is modular and
    scalable, allowing easier integration of new sensors and message types
    while reducing redundancy and improving maintainability.
    [main.cpp]
2025-09-06 Corrected: battery data
    Battery data was sent as zero unless new data arrived. Fixed now sends
    the data in each payload and changes correctly when new data is
    recorded.
    [main.cpp]
2025-09-08 updated: payload
    - Battery data is now treated like any other sensor data, in search of a
    more standard and scalable format.
    - The screen was redesigned to display more information about the
    payload to be sent.
    [main.cpp]
2025-09-09 updated: payload format
    - payload updated and compatible with current version of the decoder
    - updated documentation on the payload format
2025-09-10 display task changed and optimized
    - increased I2C communication speed
    - optimized data display screen
2025-09-10 refactor: Improve ISR and task scheduling
    - Replaced `TaskMonitorPin` with a more efficient, debounced hardware
    interrupt.
    - Optimized ADC sampling ISR by removing the internal loop, ensuring
    deterministic execution.
    - Hardened periodic tasks by implementing `vTaskDelayUntil` for accurate
    timing.
    - Improved ISR performance by using integer math for running
    calculations.
    [main.cpp]
2025-10-10 Added: Modbus master code with LORAWAN capability
    -Register size changes in sample codes
2025-10-22 Update: TTGO master code
    - Test pending
    - Pending update of ADS115 slave sensor to adapt to TTGO master
2025-10-24 Successful payload creation
    -Missing: assign unique keys to connect to the LoRaWAN gateway
    [main.cpp]
2025-12-04 Retrucured Repo
    [monitor.kicad_pcb, monitor.kicad_sch]
2025-12-04 Add: Modbus Monitor Master PCB documentation
    [monitor REV2.csv, monitor REV2.kicad_pcb, monitor REV2.kicad_sch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]
2026-01-07 FIX: Corrected Modbus communication handling in master and slave devices
    - It was identified that the master device was sending data packets with a delay of 3 messages compared to what was reported by the slave.
    - Code is added to the slave device for intensive debugging
    - The error in the Modbus API is identified and corrected by discarding responses backed up in the queue.
    [ModbusAPI.cpp, main.cpp]
2026-01-30 Introduce generic Modbus slave core and ADS-specific data layer
    Reworked firmware architecture to separate concerns between the Modbus RTU slave
    core and the sensor data pipeline.
    The main application now operates as a generic Modbus endpoint that reads from
    a shared buffer, while all ADS1015 configuration, sampling, analysis and RMS
    history tracking are encapsulated in a dedicated library.
    [ADSManager.cpp, main.cpp]
2026-01-30 Schematics and monitor control board
    [CURRENT-SENSOR-B_Cu.gbr, CURRENT-SENSOR-B_Mask.gbr, CURRENT-SENSOR-Edge_Cuts.gbr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]
2026-02-02 feat: refactor ADS acquisition core
    - **Purpose**: Shared foundation for all ADS-based sensors
    - **Features**:
    - Type-agnostic initialization (ADS1015/ADS1115)
    - Protected helper methods: initADS(), readChannel()
    - Thread-safe data access with FreeRTOS mutex
    - Abstract interface enforcing begin() and startSampling()
    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
2026-02-02 Deterministic epoch-based scheduler
    -Aligns nextSampleTime to a common epoch to synchronize periods.
    -Orders the scheduler by interval, slaveID, and sensorID.
    -Reschedules without drift (interval skips).
    -Reorders dynamically when sensors are added.
    [main.cpp]
2026-02-04 Added: Pro sensor priority system
    - The system reserves the right to initiate communication to high-priority sensors known as bus drivers.
    - The low-priority sensors, known as passengers, arrive and will be stored in memory until a driver arrives.
    - When a driver arrives, it waits a grace period to wait for its complementary sensor, if there is one.
    - Once the time has passed, it takes the waiting passengers and sends them to the driver.
    - A timeout period is implemented to send passengers if, for any reason, drivers do not arrive.
2026-02-06 Added: Base code for temperature sensor
    -It's just the shell, waiting for the full logic to be implemented.
2026-02-06 Refactor: Sensor abstraction through inheritance
    - Extracted common I2C logic to ADSBase abstract class.
    - Standardized public interface for generic sensor usage in main.
    - Decoupled application logic from specific sensor implementation (RMS/Temp).
2026-02-07 Macros for conditional compilation
    - Implementation of macros to change the object to compile (temperature, voltage/current)
2026-02-07 refactor: move processing params to managers
    - ADSBaseConfig now only contains: type, i2c_addr, gain, process_interval_ms
    - num_channels & conversion_factors moved to ADSManagerConfig
    - Cleaner separation between hardware config and processing logic
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2026-02-10 Handling the missing I2C sensor at startup
    - Detects I2C communication failure during initialization
    - Skips sensor read and buffer fill tasks when sensor is absent
    - Fills data buffer with 0xFF to signal error to the master
    - Runtime handling and restart logic pending
    [main.cpp]
2026-03-14 Change: reading data by polling
    [SLAVE_V-C_NO_INSOLATED-B_Cu.gbr_inverted_iso.DXF, SLAVE_V-C_NO_INSOLATED-B_Mask.gbr_iso.DXF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]
2026-06-04 PCB light intensity meter
    - Preliminary implementation of Modbus LoRaWAN master
    [LUXOMETER.kicad_pcb, LUXOMETER.kicad_sch]
2026-06-05 refactor: table-driven Modbus polling with static request config
    Replace the dynamic auto-discovery, scheduler, and aggregator tasks
    with a single polling loop driven by a static request table.
    Changes:
    - New ModbusConfig.h: bus config, per-device overrides, and request table
    - ModbusAPI: accept baud rate and UART config parameters
    - main.cpp reduced ~70% (1192 to 347 lines):
    - Remove slaveList, scheduleList, schedulerMutex, auto-discovery
    - Remove DataRequestScheduler, DataAggregatorTask, registerSlave / unregisterSlave
    - Keep construirPayloadUnificado (wire format unchanged)
    - Keep LoRa tasks unchanged
    - Add mainPollingTask: batch reads -> group by sensorType -> LoRa send
    - Pa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
    [ModbusAPI.cpp, main.cpp]
2026-06-06 Changes to the PCB
    - DEV_MODULE_EXAPLE_SLAVE added
    [LUXOMETER-B_Cu.gbr_inverted_iso.DXF, LUXOMETER-F_Silkscreen.gbr_inverted_iso.DXF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]
2026-06-06 refactor: strip ADC acquisition, add simulated sensor slave
    - Remove all ADS/I2C acquisition logic (ADSBase, ADSManager,
    TempADSManager, PressADSManager headers and sources)
    - Replace with simulated sensor task generating V (120V ± 5V)
    and I (5A ± 0.5A) with 120° phase shift between lines
    - Switch to Serial (UART0) with RTS pin 22 for RS485 transceiver
    half-duplex direction control
    - Make bus config match master: 9600 baud, SERIAL_8N1
    - Add documented register map (12 regs, 0x00-0x0B)
    - Remove all serial debug output (firmware is mute, Modbus only)
    - Drop Adafruit ADS1X15 dependency from platformio.ini
    [ADSManager.cpp, main.cpp]
2026-06-09 fix: pass RTS pin in ModbusServerRTU constructor instead of prepareHardwareSerial
    - ModbusServerRTU now constructed with (2000, 22) so eModbus
    manages GPIO22 as R/D via digitalWrite callback
    - Removed bogus prepareHardwareSerial(Serial, RTS_PIN) call
    that was misinterpreted as bufferSize=22
    - RTS pin is toggled LOW (receive) at idle and HIGH (transmit)
    before each response, fixing bus contention
    [main.cpp]
2026-06-09 Modbus communication correction
    -Error in sending a package via LoRaWan pending correction
    [LUXOMETER-B_Mask.gbr, LUXOMETER-job.gbrjob]
2026-06-09 fix: 1 registro por solicitud Modbus + Task Notification elimina crash
    [ModbusAPI.cpp]
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2026-06-10 fix: request ID matching prevents stale callback cross-talk
    [ModbusAPI.cpp]
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2026-06-16 fix: len byte now represents 4-byte samples, not Modbus reg count
    [main.cpp]
2026-06-16 fix: node phantom len byte now represents 4-byte samples, same patch as master
    [main.cpp]
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2026-06-19 fix: update devaddr, monitor speed, and kiCad visible layers
2026-06-19 fix: add .gitignore to itself and add KiCad backup patterns
2026-06-20 Pending KiCad files
    [LUXOMETER-B_Cu.gbr_inverted_iso.DXF, LUXOMETER-F_Silkscreen.gbr_inverted_iso.DXF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]
2026-06-27 feat: add DEV_TRIFASICO with swapWordOrder + per-request padding
    [main.cpp]
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2026-07-27 fix: add 10ms inter-frame delay between Modbus reads to prevent RS485 timing issues
    [main.cpp]
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2026-10-02 feat: add RadioLib LoRaWAN Modbus master for 3-phase meter
    New snapshot under src/12-09-26/CODE/TTGO_MASTER_MODBUS_LORA.
    - Migrate from MCCI LMIC to RadioLib (OTAA, Class A, downlink commands)
    - Configure for DEV_TRIFASICO_NUEVO (slave 1, low-byte-first, 12 requests)
    - Add 10 ms inter-frame delay between Modbus reads
    - Persist DevNonce/session in NVS; apply datarate after OTAA to fix PACKET_TOO_LONG
    [ModbusAPI.cpp, SensorRegistry.h, main.cpp]
2026-10-02 fix: rejoin OTAA on boot with DevNonce persistence and retries
    - Rejoin on every boot and drop session persistence to avoid FCnt gaps and NVS wear
    - Persist only DevNonce/JoinNonce and restore after beginOTAA()
    - Add boot join retries (5 x 5 s) and DevNonce logging
    - Auto-rejoin after 3 consecutive uplink errors and new 0x06 REJOIN downlink command
    [main.cpp]
2026-10-05 chore: stop tracking generated fabrication/docs artifacts
    - Add .gitignore rules for KiCad outputs (gerbers, DXF, ezd, FlatPrj), backups, logs and build artifacts
    - Add .gitattributes (EOL normalization + binary markers)
    - Untrack 253 already-committed generated files (kept on disk)
    - KiCad sources (.kicad_pcb/.kicad_sch) remain tracked
    [CURRENT-SENSOR-B_Cu.gbr, CURRENT-SENSOR-B_Mask.gbr, CURRENT-SENSOR-Edge_Cuts.gbr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]
2026-10-05 refactor: move hardware projects under hardware/
    KiCad projects moved under hardware/ (sources; generated outputs remain untracked).
    [CURRENT-SENSOR.csv, CURRENT-SENSOR.kicad_pcb, CURRENT-SENSOR.kicad_sch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]
2026-10-05 chore: keep KiCad .gitignore files with their projects
    Move parent-level KiCad ignore files into hardware/rev3 and hardware/monitor_rev2 so exported CSVs/netlists stay ignored; untrack 7 exported CSVs.
    [CURRENT-SENSOR.csv, MASTER.csv, SLAVE_PRESSURE.csv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]
2026-10-09 feat: add modbus_master_mqtt variant (block reads + MQTT-ready core)
    - New independent PlatformIO project firmware/modbus_master_mqtt (WiFi/MQTT transport, no LoRaWAN)
    - Modbus API slimmed to eModbus syncRequest; errors mapped from the Error enum
    - Block-based reads (12 requests -> 4) with a per-signal decode function
    - Named external sensor IDs; frequency A/B/C and power factor A/B/C/combined
    - MeasureFrame queue handoff to the MQTT task (publish step pending)
    - Ignore **/include/netconfig.h (secrets); add TUTORIAL_MODBUS.md
    [ModbusAPI.cpp, SensorRegistry.h, main.cpp]
2026-10-09 feat: add WiFi connectivity to modbus_master_mqtt
    - WiFi STA init (hostname, auto-reconnect) + network task on core 1
    - Remove setSleep(false) to match ESPHome default power save (fixes disconnect loop)
    - Move logging out of the WiFi event callback (flags only) to avoid blocking the WiFi task
    - Log disconnect reason; re-issue begin() only after 10s without connection
    [main.cpp]
2026-10-09 feat: add MQTT connectivity to modbus_master_mqtt
    - AsyncMqttClient configured in setup (keepalive 15s, clean session, LWT + birth)
    - Publish retained birth 'online' on connect to <base>/status; LWT 'offline' by broker
    - Network task connects MQTT only when WiFi is up, with reconnect backoff
    - Keep WiFi/MQTT callbacks flag-only (no logging in the AsyncTCP/WiFi tasks)
    [main.cpp]
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2026-11-03 feat: add simulated Modbus data and ABP activation
    - add coherent three-phase sensor simulator for demos
    - add ttgo-lora32-v21-sim env with 10s polling
    - switch LoRaWAN from OTAA to legacy ABP (sub-band 8)
    - fix codec power-factor extraction from register 0x0027
2026-11-04 fix: harden Sparkplug session and build reproducibility
    - persist bdSeq only after a successful NBIRTH
    - replace cross-core volatile flags with std::atomic
    - validate queue/task creation and remove dead poll notification path
    - pin espressif32 7.1.3 and eModbus v1.7.4, align monitor baud, add -Wall -Wextra
    - update AGENTS.md and AUDIT.md
2026-11-04 fix: lower Modbus timeout and bound poll cycle
    - set Modbus block timeout to 500 ms and document the worst-case cycle
    - replace the magic inter-block delay with MODBUS_BLOCK_GAP_MS
    - log per-cycle duration for field measurements
2026-11-04 fix: guarantee cycle-end NDATA and node health
    - make g_lastCycleOk atomic and update it from the polling task
    - preserve cycleEnd when the queue is full by evicting the oldest frame
    - start node health as false until the first completed cycle
2026-11-04 fix: require NTP before MQTT connect
    - gate MQTT CONNECT on timeReady() so NDEATH always has a timestamp
    - log configured NTP servers and wait status
    - document local NTP requirement for isolated LANs
2026-11-09 fix: retry device births per device
    - split NBIRTH from per-device DBIRTH publishing
    - track device birth state and retry only failed DBIRTHs
    - keep NDATA flowing when a device birth is pending
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2026-11-12 fix: guard node metric builders against overflow
    - add nextMetric() with an SPB_MAX_METRICS bounds check
    - use it in the node metric builders and assert the NBIRTH worst case
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
